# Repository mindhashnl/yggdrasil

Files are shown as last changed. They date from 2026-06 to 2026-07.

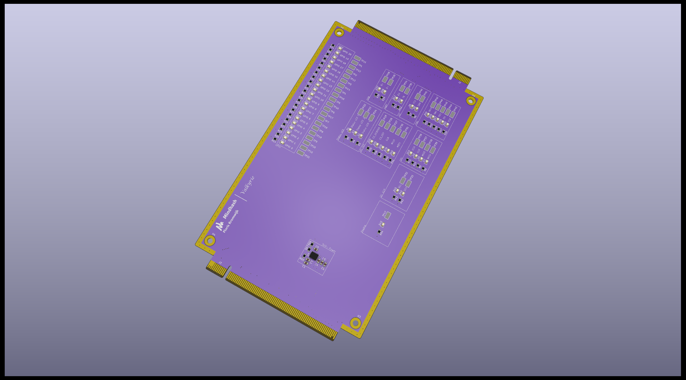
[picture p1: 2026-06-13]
hardware/valkyrie_led/TestBlade.png

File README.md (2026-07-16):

# 🌳 Yggdrasil - Hardware Infrastructure


[]()
[]()

> **⚠️ NOTE:** This repository contains **hardware design files only** (Schematics, PCB Layouts, Gerber files, BOMs, and Mechanical CAD). 
> The software stack is not yet updated to the new hardware.

## 📖 Overview

Yggdrasil is an open-source, modular hardware-in-the-loop (HIL) testing framework designed for continuous integration (CI/CD) of embedded systems. It allows developers to test firmware automatically on real microcontrollers (MCUs) at scale. 

The physical architecture is designed to fit inside a standard **19-inch 3U server rack** and consists of a primary control board, a multiplexing backplane, and hot-swappable target testing blades.

---

## 🧩 System Architecture

The hardware is split into three main modules:

### 1. Mimir (Compute Controller)
The "brain" of the server. It acts as the bridge between the high-level network and the low-level hardware matrix.
* **Core:** Raspberry Pi Compute Module 5 (CM5).
* **Storage:** M.2 NVMe SSD slot for reliable, high-speed storage.
* **Connectivity:** Gigabit Ethernet (RJ45), USB-A, HDMI (for local debugging).
* **Interface:** Connects to the backplane via a custom-pinned PCIe x8 mechanical connector.

### 2. Bifrost (The Backplane)
The routing matrix that connects Mimir to the testing blades. It contains no "smart" compute chips, only routing and switching logic.
* **Switching:** Uses cascaded `74HC595` and `SN74HCS165` shift registers to control `TMUX1511` analog multiplexers.
* **Buses:** Routes shared JTAG, UART, SPI, I2C, CAN, and GPIO lines to any connected blade.
* **Power:** Accepts 12V input and steps it down to 5V and 3.3V rails for the entire system using TPSM33625 modules.
* **Capacity:** Supports up to 16 daughter boards.

### 3. Valkyrie (Daughter Blades)
The Device-Under-Test (DUT) modules. These are inserted into the front of the server.
* **Form Factor:** 110mm x 170mm (excluding PCIe fingers). Fits in custom HDD-style hot-swap trays.
* **Standardization:** Connects to Bifrost using a custom-pinned PCIe x16 mechanical connector.
* **Included Reference Designs:**
  * **Valkyrie-ESP32S3:** A complete testing blade featuring an ESP32-S3, status LEDs, physical buttons, and a hardware identification EEPROM.
  * **Valkyrie-Test:** A diagnostic board with LEDs mapped to every PCIe lane to visually verify multiplexer switching logic.

---

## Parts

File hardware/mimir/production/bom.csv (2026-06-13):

Designator | Footprint | Quantity | Value | LCSC Part #
C1, C10, C11, C12, C2, C3 | 805 | 6 | 22uF
C13, C14, C15, C16, C17, C18, C20 | 1210 | 7 | 100uF
C4, C7 | 805 | 2 | 4.7uF
C5, C8 | 805 | 2 | 100nF
C6, C9 | 805 | 2 | 1uF
D1 | 603 | 1 | LED Green
J10 | HDMI_A_Molex_208658-1001_Horizontal | 1 | HDMI_A_1.4
J11 | PinHeader_2x07_P2.54mm_Vertical | 1 | Conn_02x07_Odd_Even
J2 | M.2 M Key socket | 1 | Bus_M.2_Socket_M
J3 | PinHeader_1x03_P2.54mm_Vertical | 1 | Conn_01x03
J5 | Hirose_FH12-22S-0.5SH_1x22-1MP_P0.50mm_Horizontal | 2 | Conn_01x22_Socket
J6 | RJ45_Hanrun_HR911130A_Horizontal | 1 | RJ45_Hanrun_HR911130A_Horizontal | C54408
J7 | BUS_PCIexpress_x8 | 1 | Bus_PCI_Express_x8
J9 | USB_A_Molex_67643_Horizontal | 1 | USB_A
MODULE3, MODULE4 | Raspberry-Pi-5-Compute-Module | 2 | ComputeModule5-CM5 | C597931
R1 | 805 | 1 | 1k
R10, R11, R12, R13 | 805 | 4 | 4.7kOhm
R3, R4 | 805 | 2 | 470R
R5 | 805 | 1 | 40.2kOhm
R6, R9 | 805 | 2 | 10kOhm
R7 | 805 | 1 | 20kOhm
R8 | 805 | 1 | 23.2kOhm
SW1 | KEY-TH_4P-L7.5-W6.8-P4.50-LS7.2 | 1 | 1825027-5
U1, U2 | RDN0011A-MFG_custom | 2 | TPSM33625RDNR

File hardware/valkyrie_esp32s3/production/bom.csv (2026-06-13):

Designator | Footprint | Quantity | Value | LCSC Part #
C1, C15 | 0805 | 2 | 4.7uF
C10, C16, C2, C7, C8, C9 | 0805 | 6 | 100nF
C11, C12, C13, C14, C17, C3 | 0805 | 6 | 1uF
C18, C19, C20, C4, C5, C6 | 0805 | 6 | 22uF
CR1 | SO-8_STM | 1 | M24C02-WMN6TP
D1, D2, D3 | 0805 | 3 | LED
J1 | BUS_PCIexpress_x16 | 1 | Bus_PCI_Express_x16_Blade
J2 | PinHeader_1x02_P2.54mm_Vertical | 1 | Conn_01x02_Pin
J4 | PinHeader_1x04_P2.54mm_Vertical | 1 | Conn_01x04_Pin
J5 | USB_C_Receptacle_G-Switch_GT-USB-7010ASV | 1 | USB_C_Receptacle_USB2.0_14P
R1 | 0805 | 1 | 40.2kOhm
R10, R11, R21, R22 | 0805 | 4 | 5.1K
R12, R8, R9 | 0805 | 3 | 10k
R13, R15, R17, R19 | 0805 | 4 | 1k
R14, R16, R18, R2, R20, R25 | 0805 | 6 | 10kOhm
R23 | 0805 | 1 | 20kOhm
R24 | 0805 | 1 | 23.2kOhm
R3, R4 | 0805 | 2 | 0Ohm
R5, R6, R7 | 0805 | 3 | 470
SW1, SW2, SW3, SW4, SW6 | SW_Push_1P1T_XKB_TS-1187A | 5 | SW_Push
SW5, SW7 | SW-TH_DSWB02LHGET | 2 | DSWB02LHGET
U1 | ESP32-S3-WROOM-1 | 1 | ESP32-S3-WROOM-1
U2 | SOIC8_ONS | 1 | CAT25160VI-GT3
U3, U5 | RDN0011A-MFG_custom | 2 | TPSM33625RDNR
U4 | RSW10_TEX | 1 | TS3USB30ERSWR

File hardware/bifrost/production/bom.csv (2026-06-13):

Designator | Footprint | Quantity | Value | LCSC Part #
C1, C2 | 0603 | 2 | 4.7uF
C10, C11, C12, C7, C8, C9 | 0603 | 6 | 22uF
C103, C104, C105, C13, C16, C17, C18, C19, C20, C21, C22, C23, C24, C25, C26, C27, C28, C29, C3, C30, C31, C32, C33, C34, C35, C36, C37, C38, C39, C4, C40, C41, C42, C43, C44, C45, C46, C47, C48, C49, C50, C51, C52, C53, C54, C55, C56, C57, C58, C59, C60, C61, C62, C63, C64, C65, C66, C67, C68, C69, C70, C71, C72, C73, C74, C75, C76, C77, C78, C79, C80, C81, C82, C83, C84, C85, C86, C87, C88, C89, C90, C91, C92, C93, C94, C95, C96, C97, C98, C99 | 0201 | 90 | 100nF
C5, C6 | 0603 | 2 | 1uF
IC1, IC2, IC3 | SOP50P326X110-16N | 3 | SN74HCS165DYYR
J1 | Molex_Mini-Fit_Jr_5566-02A_2x01_P4.20mm_Vertical | 1 | Conn_01x02_Socket
J11, J15, J4 | CONN-SMD_164P-P1.00-X3113WVS-164-9TV01 | 3 | Bus_PCI_Express_x16_Blade | C5711234
J2 | CONN-TH_2EG04927-D2LN-DF | 1 | Bus_PCI_Express_x8 | C5141736
J3 | USB_C_Receptacle_G-Switch_GT-USB-7010ASV | 1 | USB_C_Receptacle_USB2.0_14P
R1 | 0603 | 1 | 20kOhm
R10, R102, R105, R108, R11, R111, R114, R117, R12, R120, R123, R126, R129, R13, R132, R135, R138, R14, R141, R144, R145, R146, R147, R148, R149, R15, R150, R151, R152, R153, R154, R155, R156, R157, R158, R159, R16, R160, R161, R162, R163, R164, R165, R166, R17, R18, R19, R20, R21, R22, R23, R24, R27, R30, R33, R36, R39, R42, R45, R48, R51, R54, R57, R6, R60, R63, R66, R69, R7, R72, R75, R78, R8, R81, R84, R87, R9, R90, R93, R96, R99 | 0201 | 81 | 5.1K
R2 | 0603 | 1 | 23.2kOhm
R3, R5 | 0603 | 2 | 10kOhm
R4 | 0603 | 1 | 40.2kOhm
U1, U2 | RDN0011A-MFG_custom | 2 | TPSM33625RDNR
U10, U11, U12, U17, U18, U19, U20, U21, U22, U27, U28, U29, U30, U33, U34, U35, U36, U37, U42, U43, U44, U45, U46, U47, U52, U53, U54, U55, U58, U59, U60, U61, U62, U67, U68, U69, U70, U71, U72, U77, U78, U79, U8, U80, U9 | RSV0016A-MFG | 45 | TMUX1511RSVR
U13, U16, U23, U24, U25, U26, U38, U41, U48, U49, U50, U51, U63, U66, U73, U74, U75, U76 | TQFN-16_L2.5-W2.5-P0.40-BL-EP1.4 | 18 | 74HC595 | C2682068
U14, U3, U39, U64 | TQFN-16_L2.5-W2.5-P0.40-BL-EP1.4 | 4 | 74HC595
U15, U40, U65 | RSW10_TEX | 3 | TS3USB30ERSWR
U31, U32, U56, U57, U6, U7 | TSOT-23-8 | 6 | TCA9416DDFR
U4 | SOT-363_SC-70-6 | 1 | SiP32431DR3

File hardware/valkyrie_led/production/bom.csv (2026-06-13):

Designator | Footprint | Quantity | Value | LCSC Part #
C1 | 0805 | 1 | 4.7uF
C2 | 0805 | 1 | 100nF
C3 | 0805 | 1 | 1uF
C4, C5, C6 | 0805 | 3 | 22uF
D10, D11, D12, D13, D14, D15, D16, D17, D18, D19, D2, D20, D21, D22, D23, D24, D25, D26, D27, D28, D29, D3, D30, D31, D32, D33, D34, D35, D36, D37, D38, D39, D4, D40, D41, D42, D43, D5, D54, D55, D56, D57, D58, D6, D7, D8, D9 | 0805 | 47 | LED
J2, J3 | BUS_PCIexpress_x16 | 2 | Bus_PCI_Express_x16_Blade
R10, R11, R12, R13, R14, R15, R16, R17, R18, R19, R20, R21, R22, R23, R24, R25, R26, R27, R28, R29, R3, R30, R31, R32, R33, R34, R35, R36, R37, R38, R39, R4, R40, R41, R42, R43, R44, R5, R55, R56, R57, R58, R59, R6, R7, R8, R9 | 0805 | 47 | 470
R65 | 0805 | 1 | 20kOhm
R66 | 0805 | 1 | 23.2kOhm
R67 | 0805 | 1 | 10kOhm
TP1, TP10, TP11, TP12, TP13, TP14, TP15, TP16, TP17, TP18, TP19, TP2, TP20, TP21, TP22, TP23, TP24, TP25, TP26, TP27, TP28, TP29, TP3, TP30, TP31, TP32, TP33, TP34, TP35, TP36, TP37, TP38, TP39, TP4, TP40, TP41, TP42, TP43, TP44, TP45, TP46, TP47, TP5, TP6, TP7, TP8, TP9 | TestPoint_Keystone_5019_Minature | 47 | TestPoint
U1 | RDN0011A-MFG_custom | 1 | TPSM33625RDNR

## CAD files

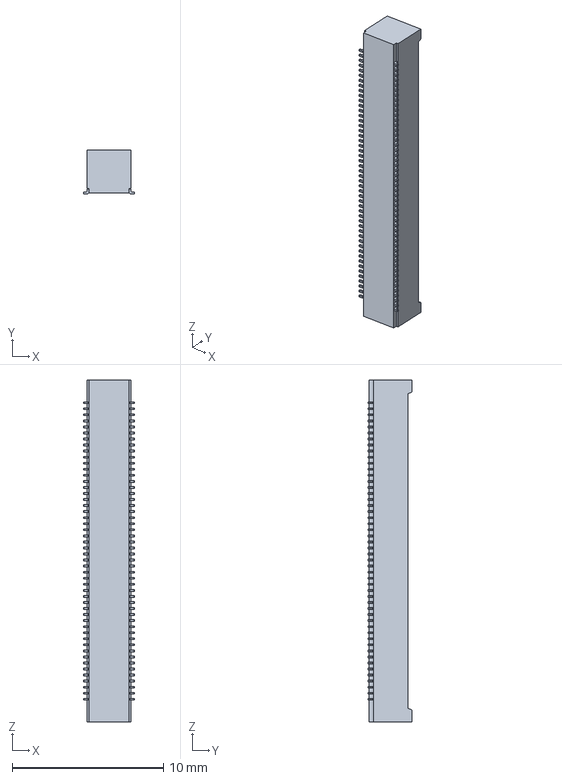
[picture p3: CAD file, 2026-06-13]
hardware/imports/RPi-CM4-Kicad-master/3D/DF40HC(3.0)-100DS-0.4V.stp
3.38 x 2.90 x 22.6 mm

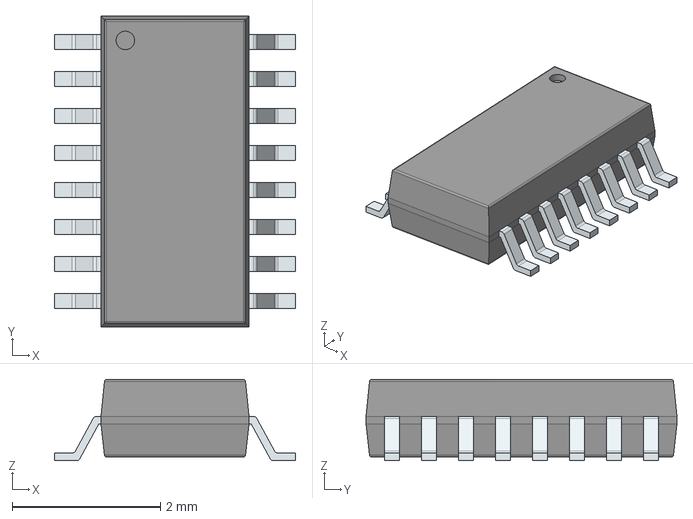
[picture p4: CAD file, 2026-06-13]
hardware/imports/step.3d/SN74HCS165DYYR.stp
3.26 x 4.20 x 1.10 mm
PinsArrayLR

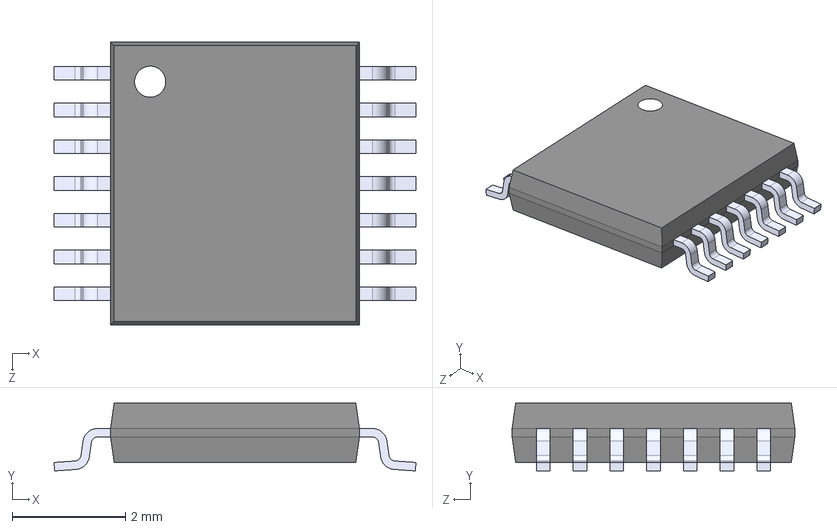
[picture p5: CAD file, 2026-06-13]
hardware/imports/TMUX1511PWR/TMUX1511PWR.step
6.40 x 1.20 x 5.00 mm

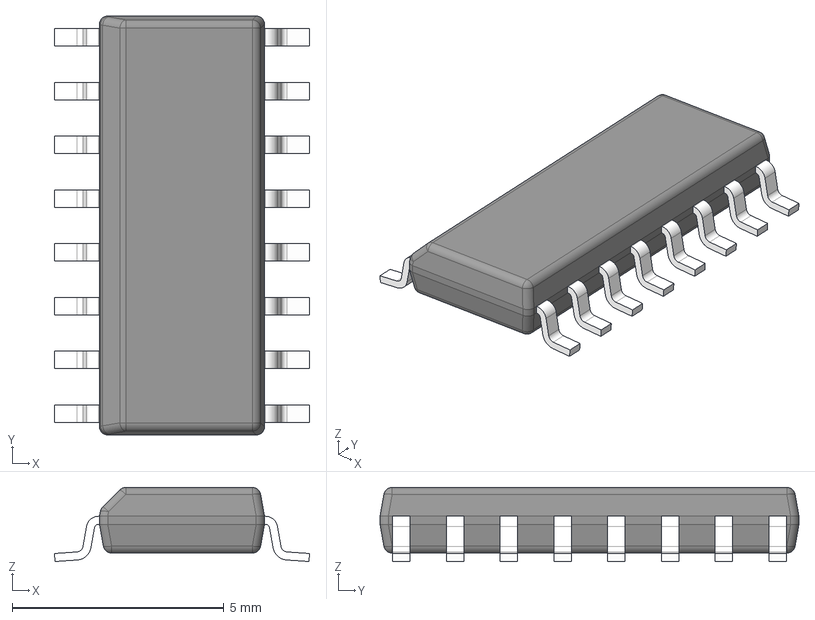
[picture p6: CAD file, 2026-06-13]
hardware/imports/ul_SN74HC595D/D0016A.stp
6.03 x 9.90 x 1.75 mm
BODY-SO
LEAD-SO x 16
PIN1-ID

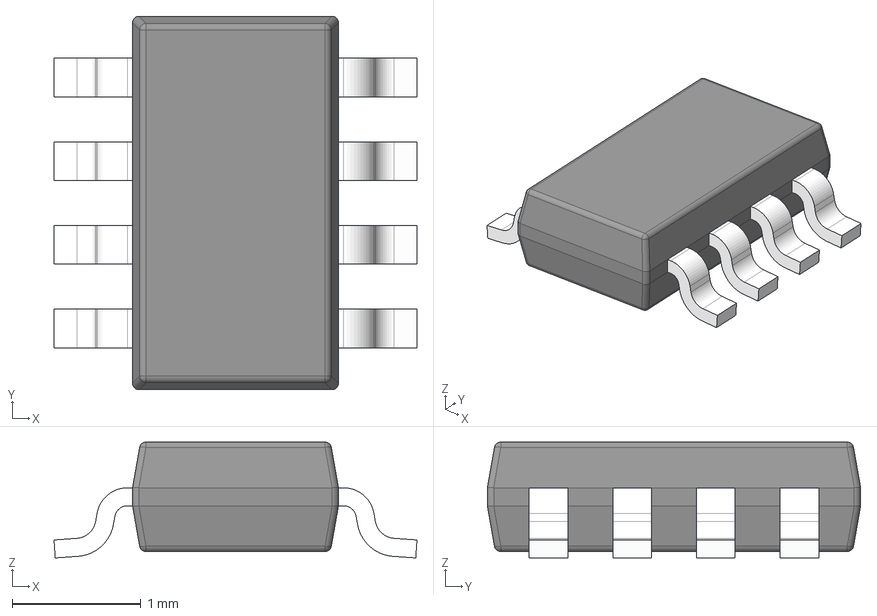
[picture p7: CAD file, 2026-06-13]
hardware/imports/ul_TCA9416DDFR/DDF0008A.stp
2.82 x 2.90 x 0.9 mm
BODY-SO
LEAD-SO x 8
PIN1-ID

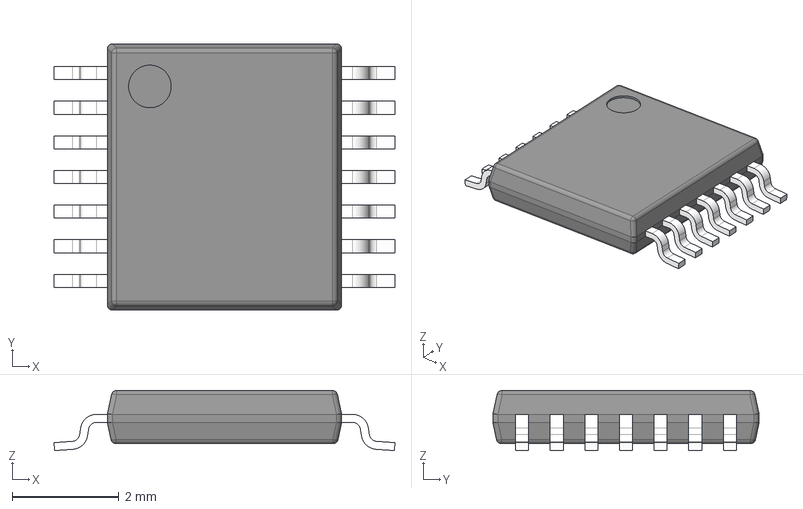
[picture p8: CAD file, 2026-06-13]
hardware/imports/ul_TMUX1511PWR/PW0014A.stp
6.40 x 5.00 x 1.13 mm
BODY-TSSOP
LEAD-TSSOP x 14
PIN1

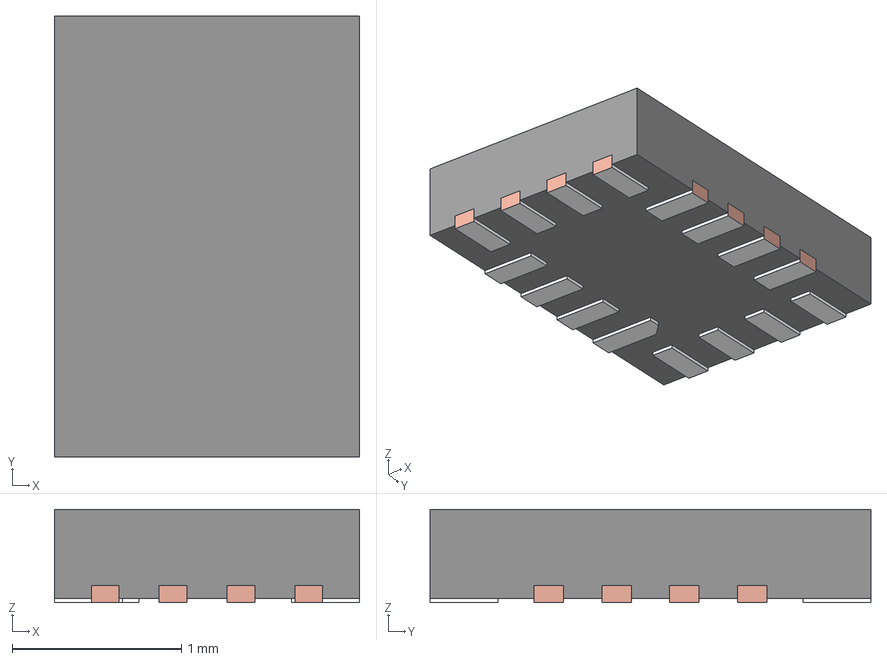
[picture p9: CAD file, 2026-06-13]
hardware/imports/ul_TMUX1511RSVR/RSV0016A.stp
1.80 x 2.60 x 0.55 mm
BODY-SON1
FRAME-RSV0016A

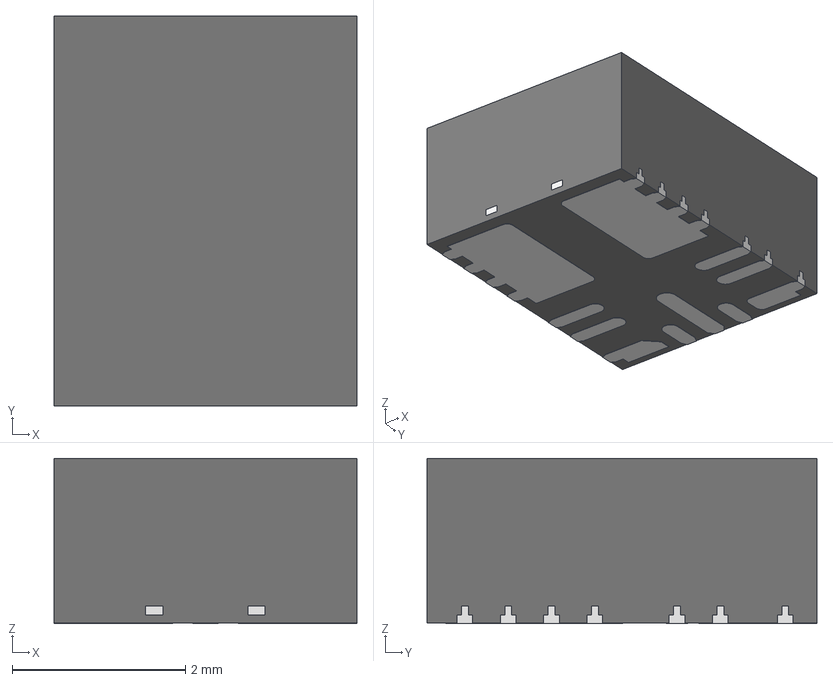
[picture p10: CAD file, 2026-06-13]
hardware/imports/ul_TPSM33625RDNR/TPSM33635.stp
3.50 x 4.50 x 1.91 mm
MOLD_CPOMPOUND_AF0
SOLID1-489_AF0
SOLID1-490_AF0
SOLID1-491_AF0
SOLID1-492_AF0
SOLID1-493_AF0
SOLID1-494_AF0
SOLID1-495_AF0
SOLID1-496_AF0
SOLID1-497_AF0
SOLID1-498_AF0

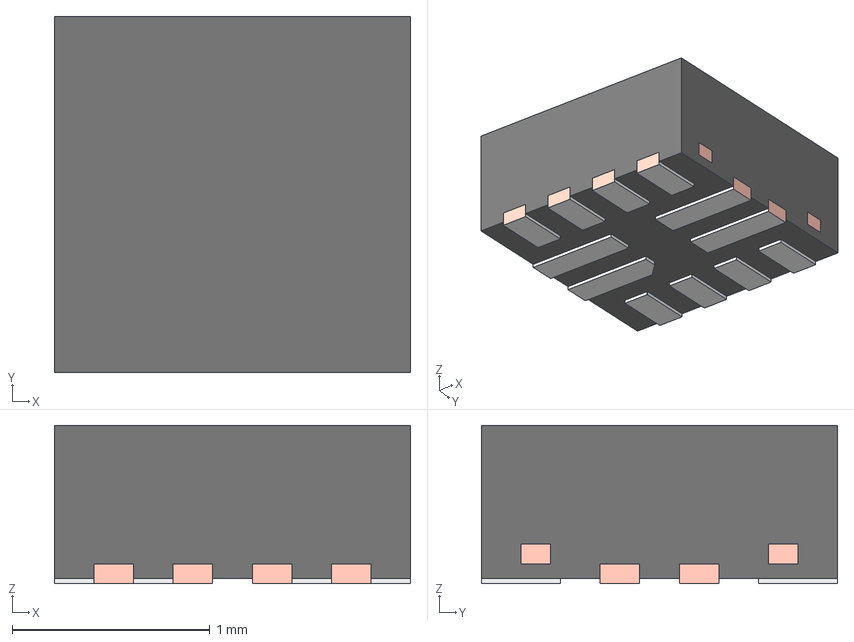
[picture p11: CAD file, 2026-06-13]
hardware/imports/ul_TS3USB3031RMGR/RMG0012A.stp
1.80 x 1.80 x 0.8 mm
FRAME
PIN1_AREA

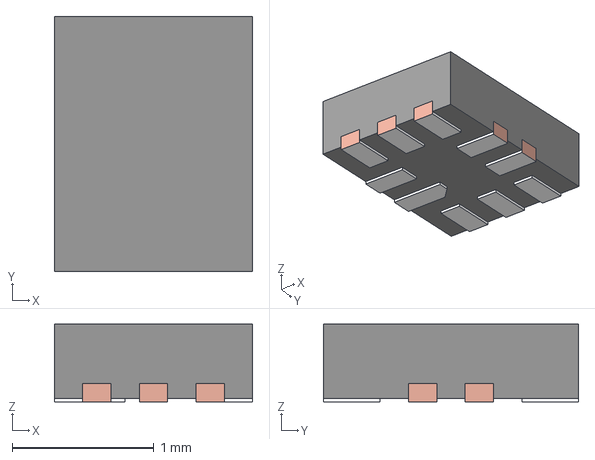
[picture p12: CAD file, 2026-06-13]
hardware/imports/ul_TS3USB30ERSWR/RSW0010A.stp
1.40 x 1.80 x 0.55 mm
FRAME

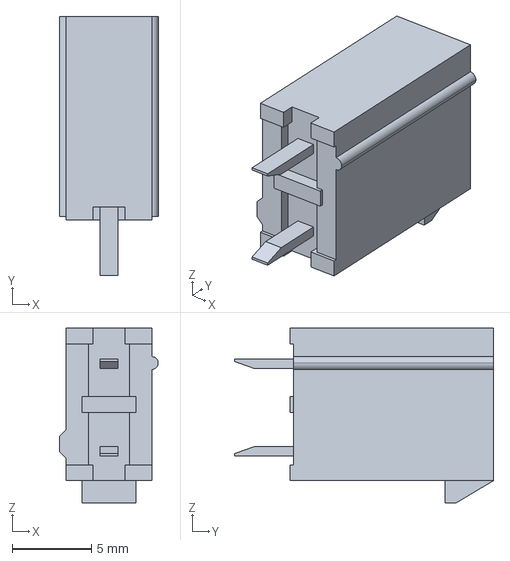
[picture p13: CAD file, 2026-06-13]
hardware/imports/174478858-659-0039281023/0039281023.stp
6.20 x 16.3 x 11.0 mm

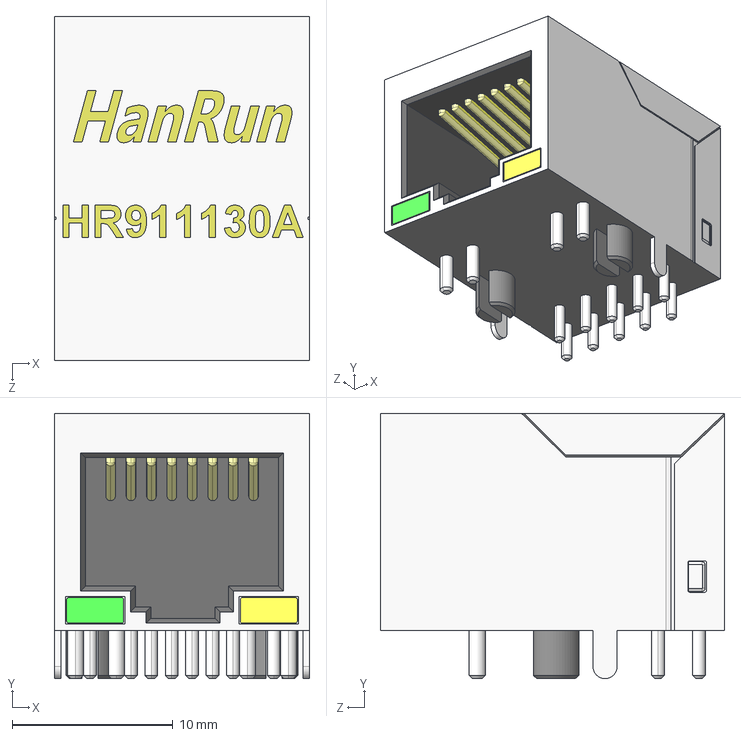
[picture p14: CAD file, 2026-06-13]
hardware/imports/Hanrun/HR911130A.STEP
15.9 x 16.5 x 21.4 mm

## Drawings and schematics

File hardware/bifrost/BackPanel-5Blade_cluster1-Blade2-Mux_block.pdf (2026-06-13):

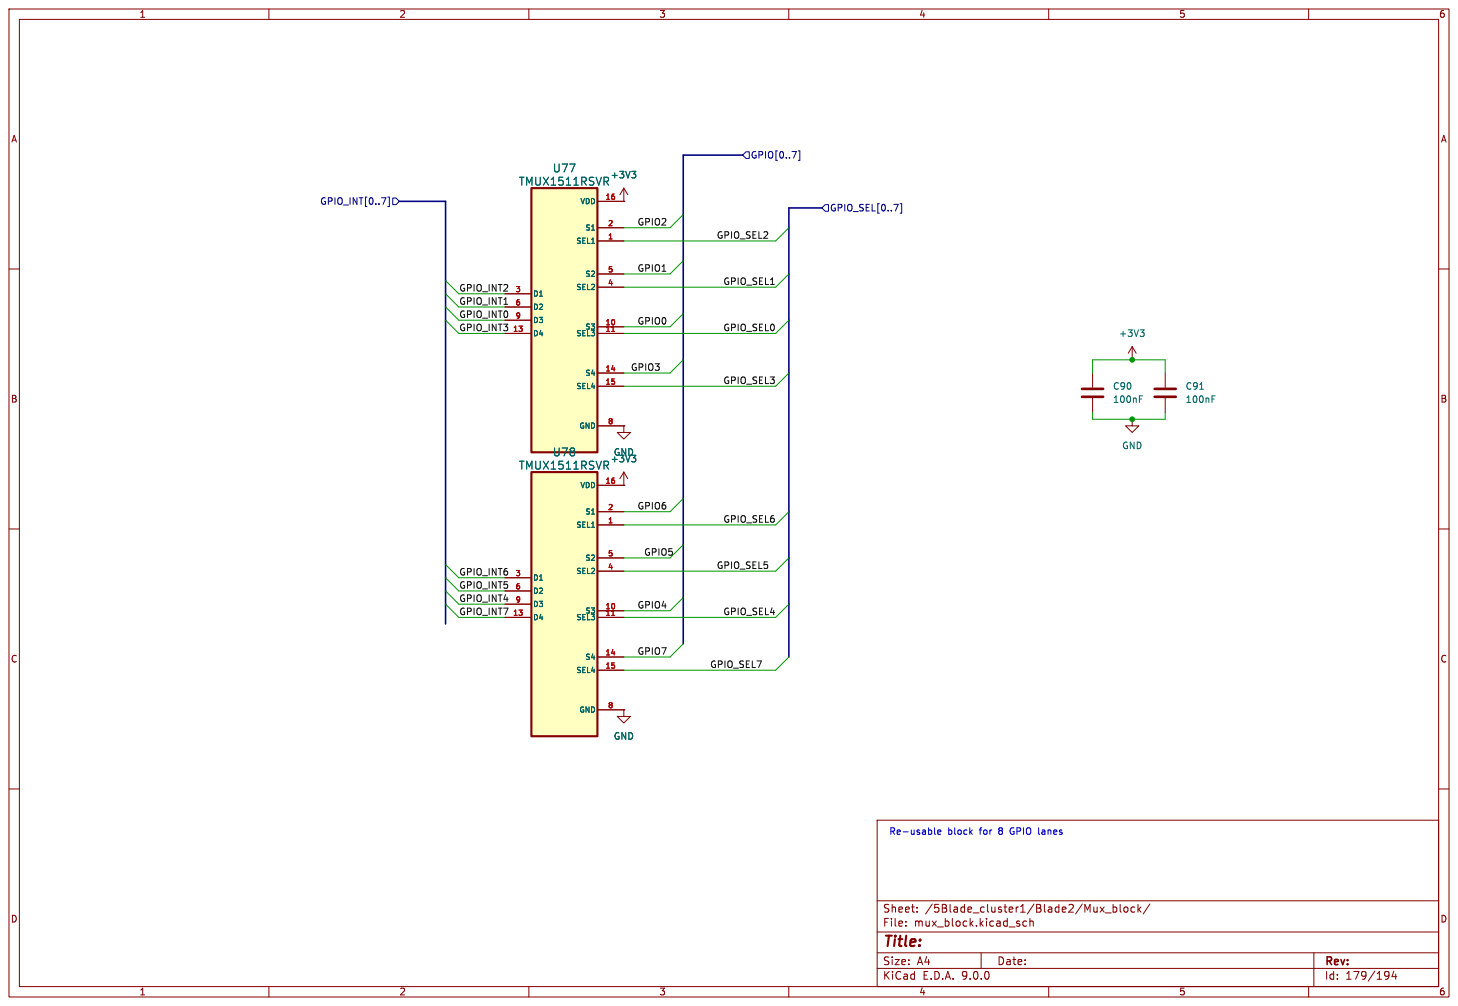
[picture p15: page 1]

Id: 179/194 Title: File: mux_block.kicad_sch Sheet: /5Blade_cluster1/Blade2/Mux_block/

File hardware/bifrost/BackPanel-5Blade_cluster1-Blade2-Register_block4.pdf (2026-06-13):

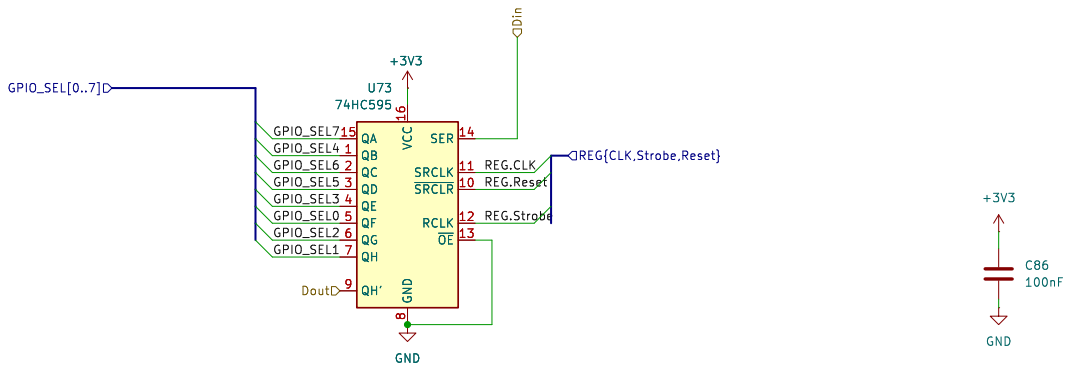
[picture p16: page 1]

8 QA 15 QB 1 QC 2 QD 3 QE 4 QF 5 QG 6 QH 7 QH' 9 GND

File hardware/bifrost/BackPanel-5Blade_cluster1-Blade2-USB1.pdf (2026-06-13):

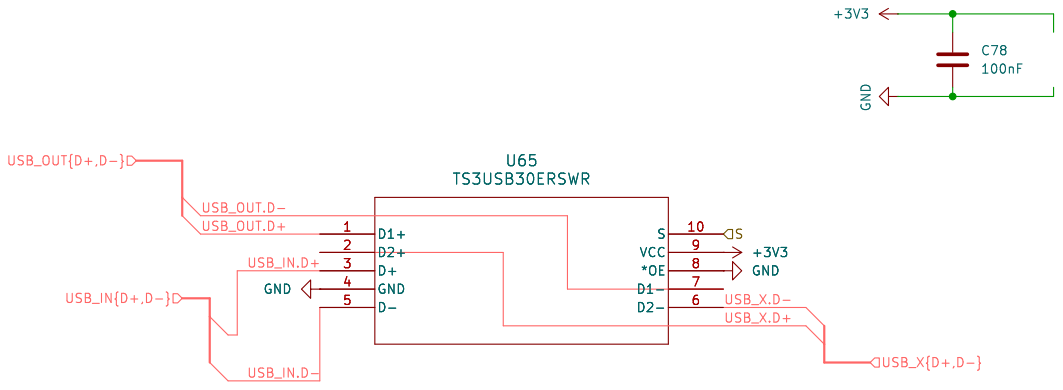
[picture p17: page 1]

Id: 169/194 Title: File: USB.kicad_sch Sheet: /5Blade_cluster1/Blade2/USB1/ GND

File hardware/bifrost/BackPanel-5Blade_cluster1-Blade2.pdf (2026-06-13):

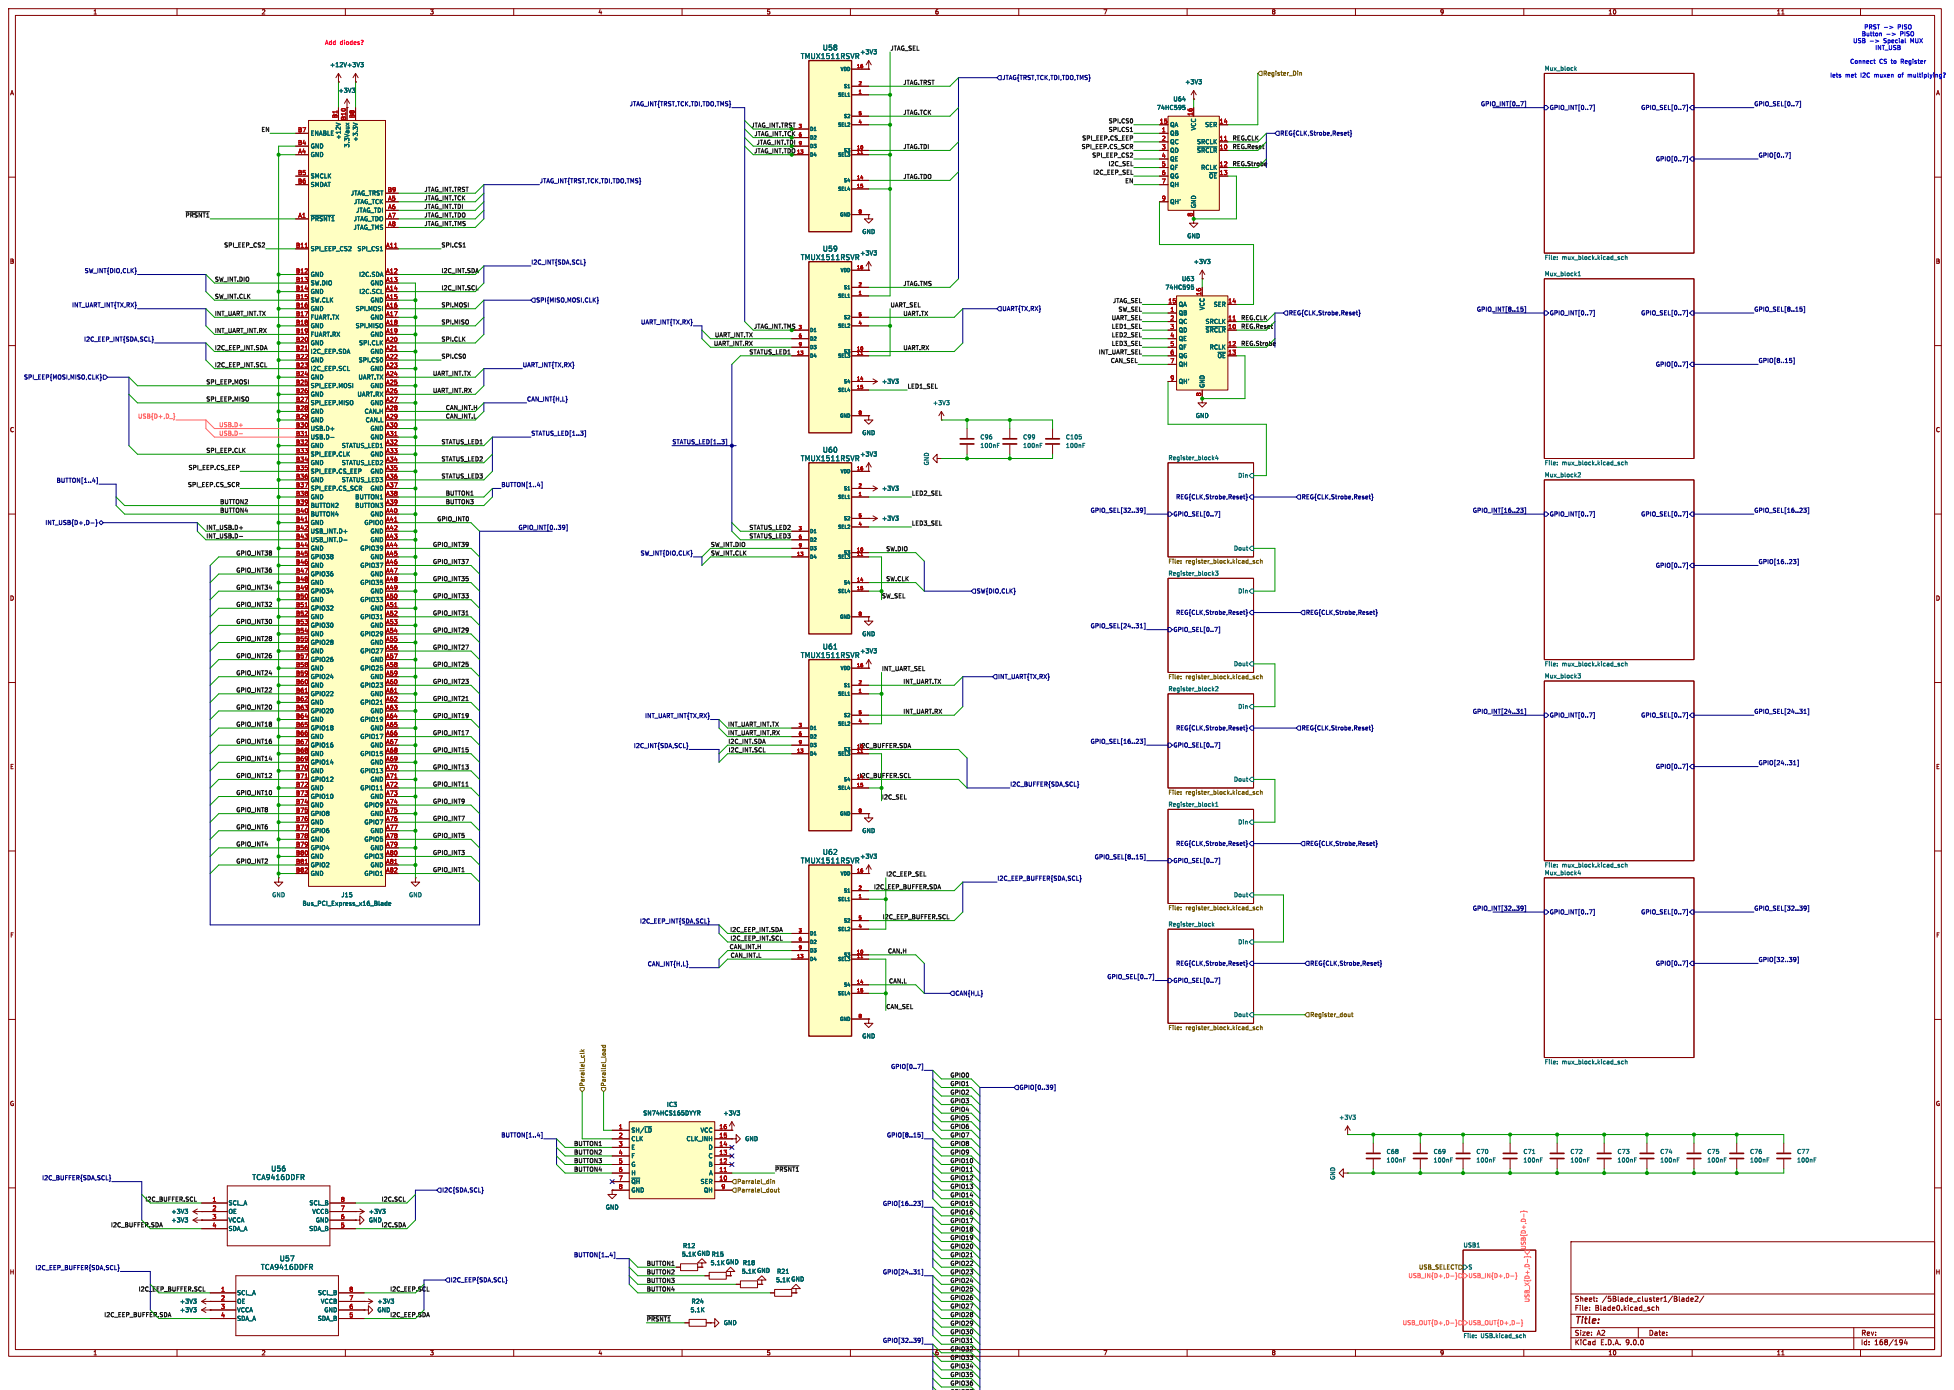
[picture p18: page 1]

INT_USB Connect CS to Register

ENABLE B7 GND B4 GND A4 SMCLK B5 SMDAT B6 ~{PRSNT1} A1 SPI_EEP_CS2 B11 GND B12 SW.DIO B13 GND B14 SW.CLK B15 GND B16 FUART.TX B17 GND B18 FUART.RX B19 GND B20

JTAG{TRST,TCK,TDI,TDO,TMS}

8 QA 15 QB 1 QC 2 QD 3 QE 4 QF 5 QG 6 QH 7 QH' 9 +3V3 GND

JTAG.TDI JTAG.TCK GPIO_INT[0..39] GPIO_INT25 GPIO_INT27 GPIO_INT33 GPIO_INT39 GPIO_INT37 GPIO_INT31 GPIO_INT35

REG{CLK,Strobe,Reset}

REG.Reset REG.CLK REG.Strobe

JTAG_INT{TRST,TCK,TDI,TDO,TMS}

I2C.SCL A14 GND A15 SPI.MOSI A16 GND A17 SPI.MISO A18 GND A19 SPI.CLK A20 GND A21 SPI.CS0 A22 GND A23 UART.TX A24 GND A25 UART.RX A26 GND A27 CAN.H A28 CAN.L A29 GND A30 GND A31 STATUS_LED1 A32 GND A33 STATUS_LED2 A34 GND A35 STATUS_LED3 A36 GND A37 BUTTON1 A38 BUTTON3 A39 GND A40 GPIO0 A41 GND A42 GND A43 GPIO39 A44 GND A45 GPIO37 A46 GND A47 GPIO35 A48 GND A49 GPIO33 A50 GND A51 GPIO31 A52 GND A53 GPIO29 A54 GND A55 GPIO27 A56 GND A57 GPIO25 A58 GND A59 GPIO23 A60 GND A61 GPIO21 A62 GND A63 GPIO19 A64 GND A65 GPIO17 A66 GND A67 GPIO15 A68 GND A69 GPIO13 A70 GND A71 GPIO11 A72 GND A73 GPIO9 A74 GND A75 GPIO7 A76 GND A77 GPIO5 A78 GND A79 GPIO3 A80 GND A81 GPIO1 A82

JTAG_TRST B9
JTAG_TCK A5
JTAG_TDI A6
JTAG_TDO A7
JTAG_TMS A8 SPI_CS1 A11
I2C_INT.SCL CAN_INT.H
I2C.SCL A14 GND A15 SPI.MOSI A16 GND A17 SPI.MISO A18 GND A19 SPI.CLK A20 GND A21 SPI.CS0 A22 GND A23 UART.TX A24 GND A25 UART.RX A26 GND A27 CAN.H A28 CAN.L A29 GND A30 GND A31 STATUS_LED1 A32 GND A33 STATUS_LED2 A34 GND A35 STATUS_LED3 A36 GND A37 BUTTON1 A38 BUTTON3 A39 GND A40 GPIO0 A41 GND A42 GND A43 GPIO39 A44 GND A45 GPIO37 A46 GND A47 GPIO35 A48 GND A49 GPIO33 A50 GND A51 GPIO31 A52 GND A53 GPIO29 A54 GND A55 GPIO27 A56 GND A57 GPIO25 A58 GND A59 GPIO23 A60 GND A61 GPIO21 A62 GND A63 GPIO19 A64 GND A65 GPIO17 A66 GND A67 GPIO15 A68 GND A69 GPIO13 A70 GND A71 GPIO11 A72 GND A73 GPIO9 A74 GND A75 GPIO7 A76 GND A77 GPIO5 A78 GND A79 GPIO3 A80 GND A81 GPIO1 A82 GND

+3V3 GND
GPIO[0..7] Mux_block1 File: mux_block.kicad_sch Din REG{CLK,Strobe,Reset}
12 ~{OE} 13 VCC 16 GND
14 SRCLK
SER
11 ~{SRCLR} 10 RCLK

I2C_EEP_INT.SCL SPI_EEP.MOSI SW_INT{DIO,CLK}

SPI{MISO,MOSI,CLK}

GPIO[0..7] Mux_block2 File: mux_block.kicad_sch Din REG{CLK,Strobe,Reset}

REG{CLK,Strobe,Reset} Parallel_clk

Din REG{CLK,Strobe,Reset}

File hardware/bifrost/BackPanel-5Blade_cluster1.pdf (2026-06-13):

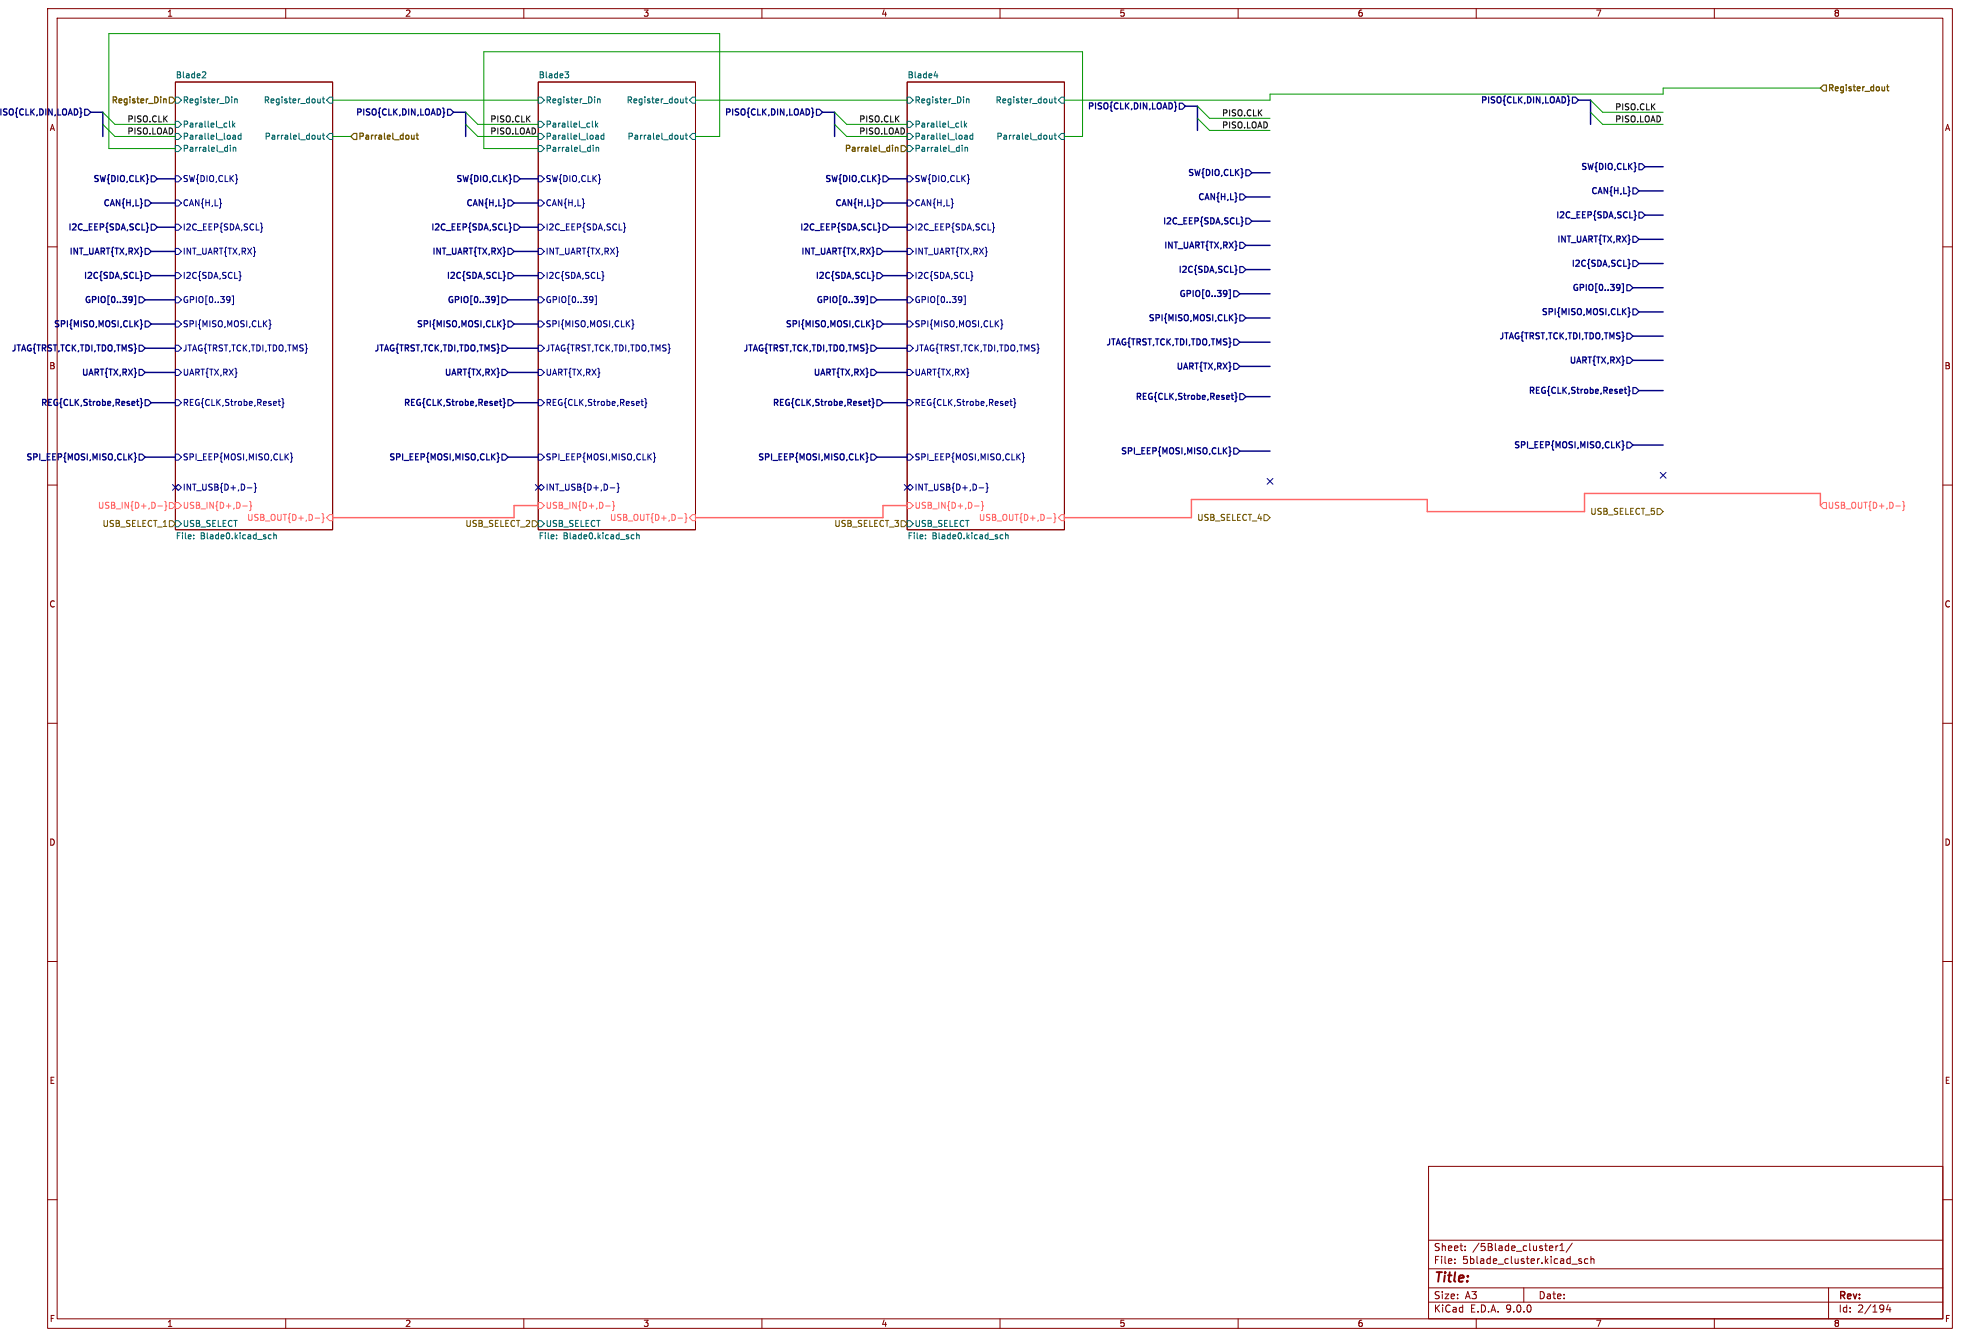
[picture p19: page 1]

SPI{MISO,MOSI,CLK} Blade5 File: Blade0.kicad_sch REG{CLK,Strobe,Reset}

PISO{CLK,DIN,LOAD}

I2C{SDA,SCL} Parralel_dout PISO{CLK,DIN,LOAD}

SPI{MISO,MOSI,CLK} Blade9 File: Blade0.kicad_sch REG{CLK,Strobe,Reset}

SPI{MISO,MOSI,CLK} Blade8 File: Blade0.kicad_sch REG{CLK,Strobe,Reset}

SPI{MISO,MOSI,CLK}

JTAG{TRST,TCK,TDI,TDO,TMS}

REG{CLK,Strobe,Reset}

Id: 2/194 Title: File: 5blade_cluster.kicad_sch Sheet: /5Blade_cluster1/

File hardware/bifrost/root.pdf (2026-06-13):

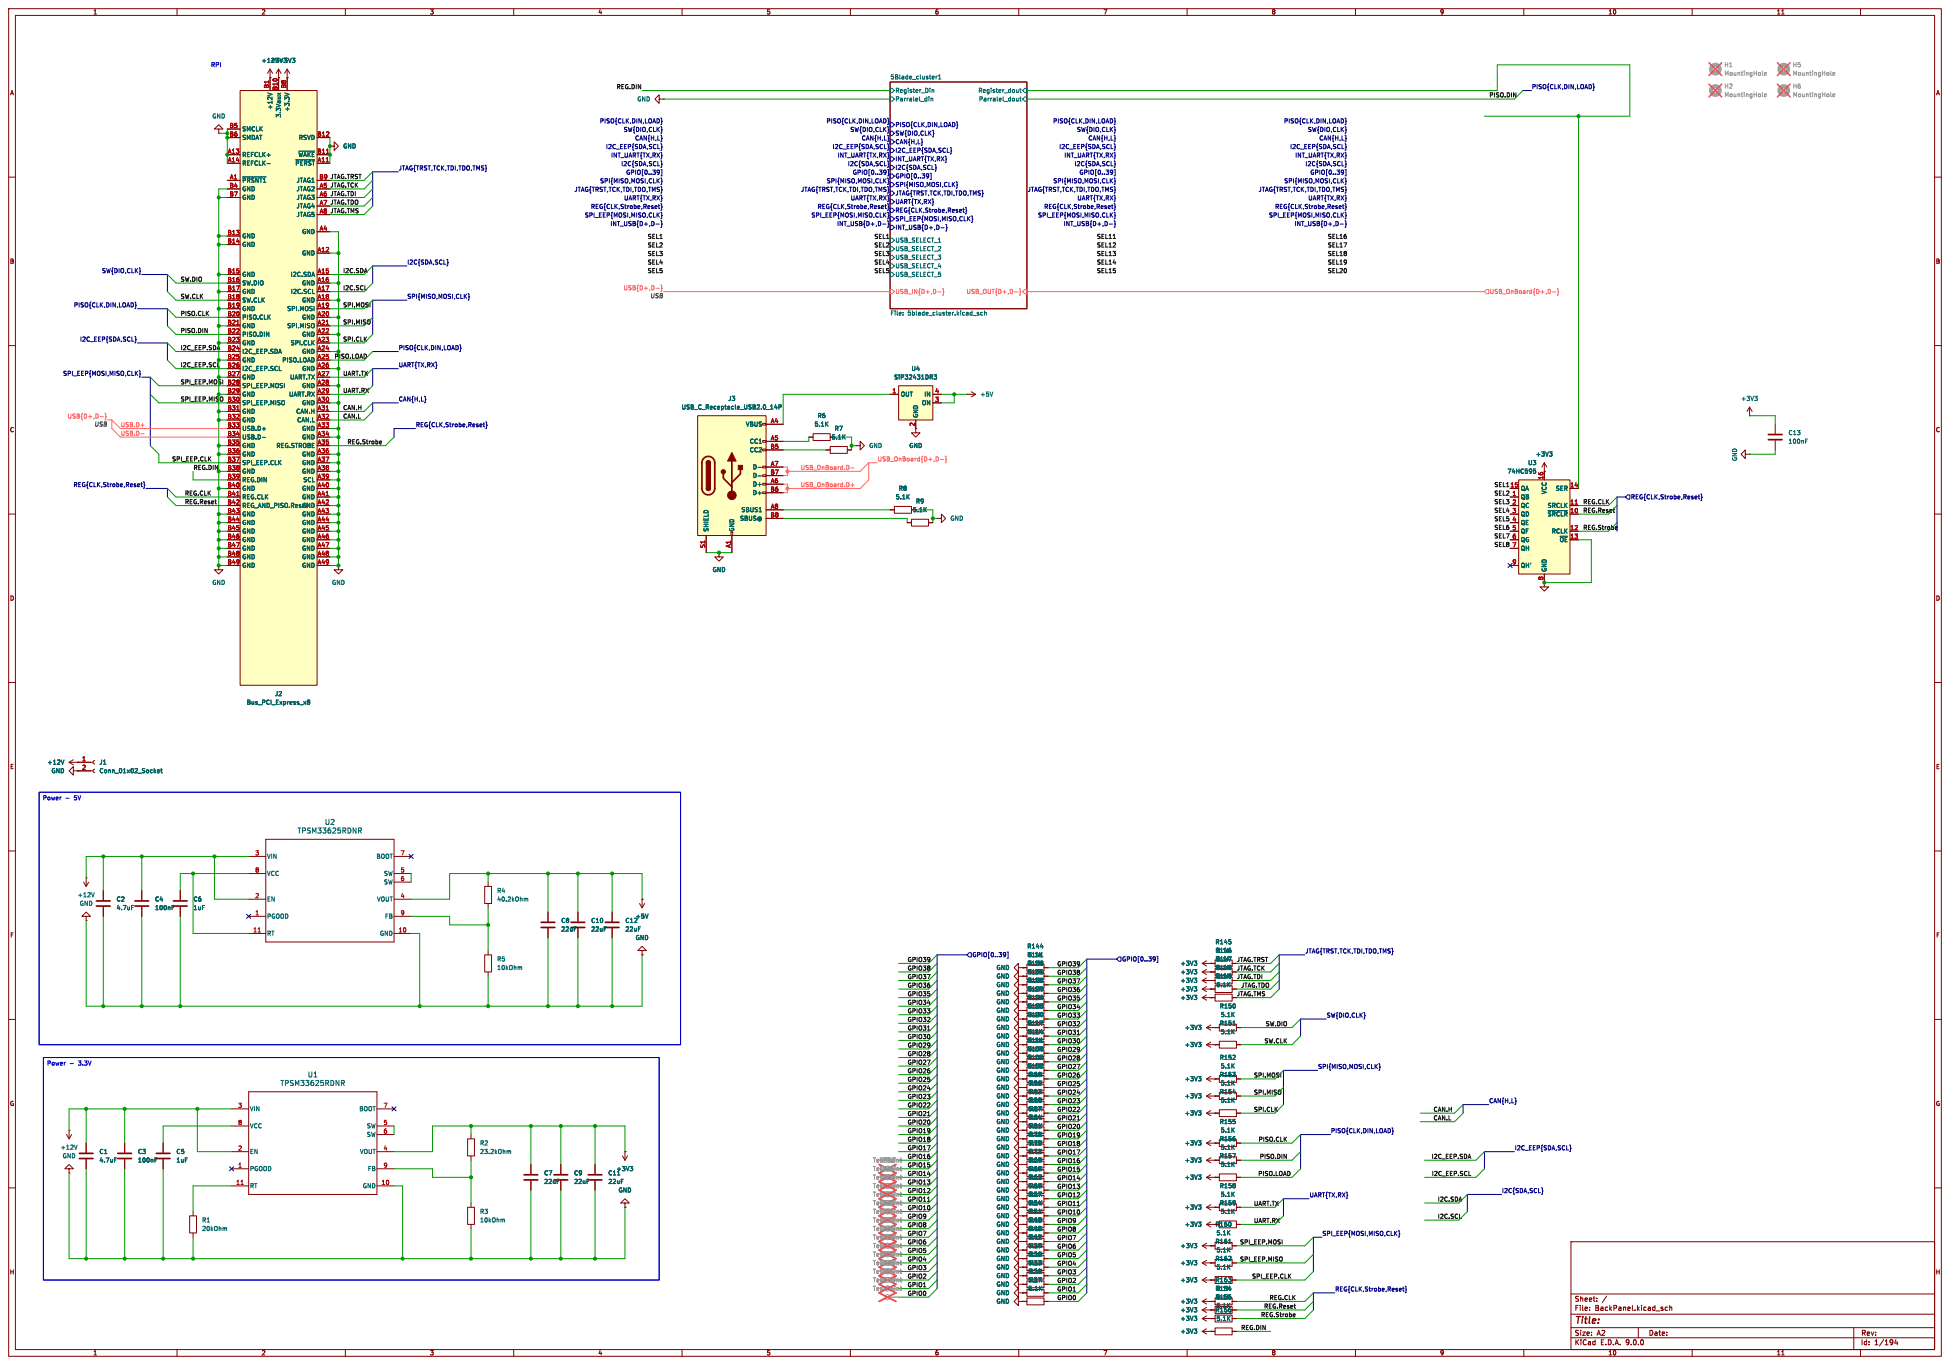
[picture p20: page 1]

+12V+3V3+3V3 GND
RPI
SMCLK B5 SMDAT B6 REFCLK+ A13 REFCLK- A14 ~{PRSNT1} A1 GND B4 GND B7 GND B13 GND B14 GND B15 SW.DIO B16 GND B17 SW.CLK B18 GND B19 PISO.CLK B20 GND B21 PISO.DIN B22 GND B23

PISO{CLK,DIN,LOAD} SEL11

Register_dout Parralel_dout PISO{CLK,DIN,LOAD}

PISO{CLK,DIN,LOAD}

INT_UART{TX,RX}
I2C{SDA,SCL}
GPIO[0..39]
SPI{MISO,MOSI,CLK}
JTAG{TRST,TCK,TDI,TDO,TMS}
UART{TX,RX}
REG{CLK,Strobe,Reset}
SPI_EEP{MOSI,MISO,CLK}
INT_USB{D+,D-}
USB_OUT{D+,D-} USB_SELECT_5 USB_SELECT_2 USB_SELECT_3 USB_SELECT_4 USB_IN{D+,D-} USB_SELECT_1

I2C{SDA,SCL} SPI_EEP.CLK REG.DIN
JTAG.TRST REG.CLK

INT_USB{D+,D-} SEL1 SPI{MISO,MOSI,CLK}

SPI{MISO,MOSI,CLK} SEL16 UART{TX,RX}

JTAG.TDI JTAG.TCK

JTAG.TDO
JTAG.TMS
I2C.SCL A17 GND A18 SPI.MOSI A19 GND A20 SPI.MISO A21 GND A22 SPI.CLK A23 GND A24 PISO.LOAD A25 GND A26 UART.TX A27 GND A28 UART.RX A29 GND A30 CAN.H A31 CAN.L A32 GND A33 GND A34 REG.STROBE A35 GND A36 GND A37 GND A38 SCL A39 GND A40 GND A41 GND A42 GND A43 GND A44 GND A45 GND A46 GND A47 GND A48 GND A49

SEL4 SPI_EEP{MOSI,MISO,CLK}

REG{CLK,Strobe,Reset} SEL13

USB_OnBoard{D+,D-} SEL7 USB{D+,D-} USB

REG{CLK,Strobe,Reset} SPI.MOSI
UART.RX REG.Strobe UART.TX

I2C_EEP{SDA,SCL}
I2C_EEP.SDA REG{CLK,Strobe,Reset}

REG.CLK REG.Strobe REG.Reset

5.1K GND GND GND GND GND GND GND GND

GPIO34 GPIO36
SPI{MISO,MOSI,CLK} GPIO21 GPIO20 GPIO35 GPIO33 GPIO29 GPIO32 GPIO31 GPIO27 GPIO26 GPIO23 GPIO24

5.1K GND GND GND GND GND GND

SPI.MOSI SPI.CLK

GPIO22
5.1K GND GND GND GND GND GND GND GND GND GND GND GND

GND

REG{CLK,Strobe,Reset} SPI_EEP.MOSI SPI_EEP.MISO

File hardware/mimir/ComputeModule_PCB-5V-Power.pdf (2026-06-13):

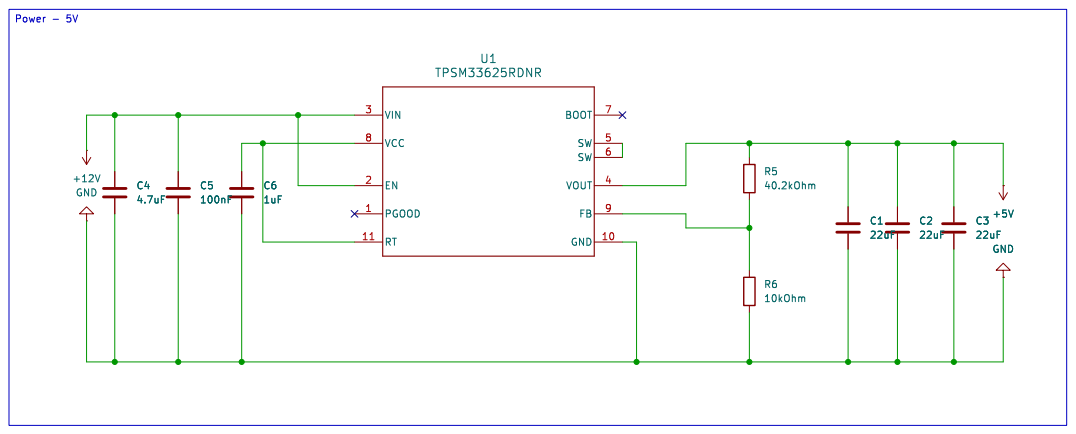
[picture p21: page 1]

Id: 3/3 Title: File: 5V_power.kicad_sch Sheet: /5V-Power/

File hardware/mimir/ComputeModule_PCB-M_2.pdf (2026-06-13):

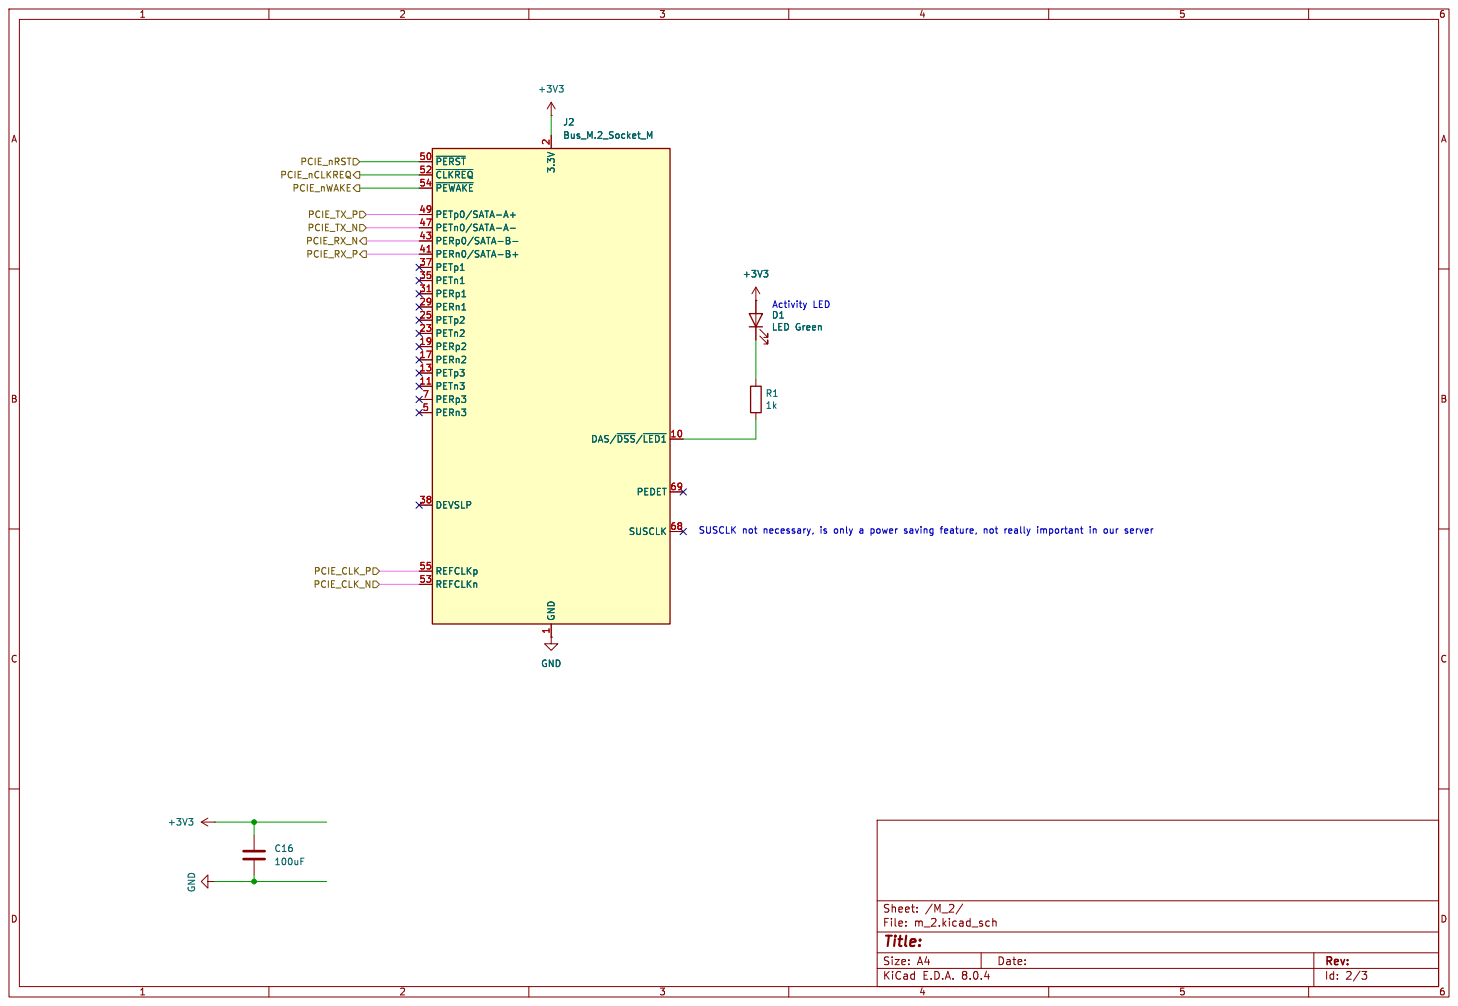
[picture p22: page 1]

2 PETn2 23 PETp2 25 PERn1 29 PERp1 31 PETn1 35 PETp1 37 DEVSLP 38 PERn0/SATA-B+ 41 PERp0/SATA-B- 43 PETn0/SATA-A- 47 PETp0/SATA-A+ 49 PERn3 5 ~{PERST} 50 ~{CLKREQ} 52 REFCLKn 53

Id: 2/3 Title: File: m_2.kicad_sch Sheet: /M_2/

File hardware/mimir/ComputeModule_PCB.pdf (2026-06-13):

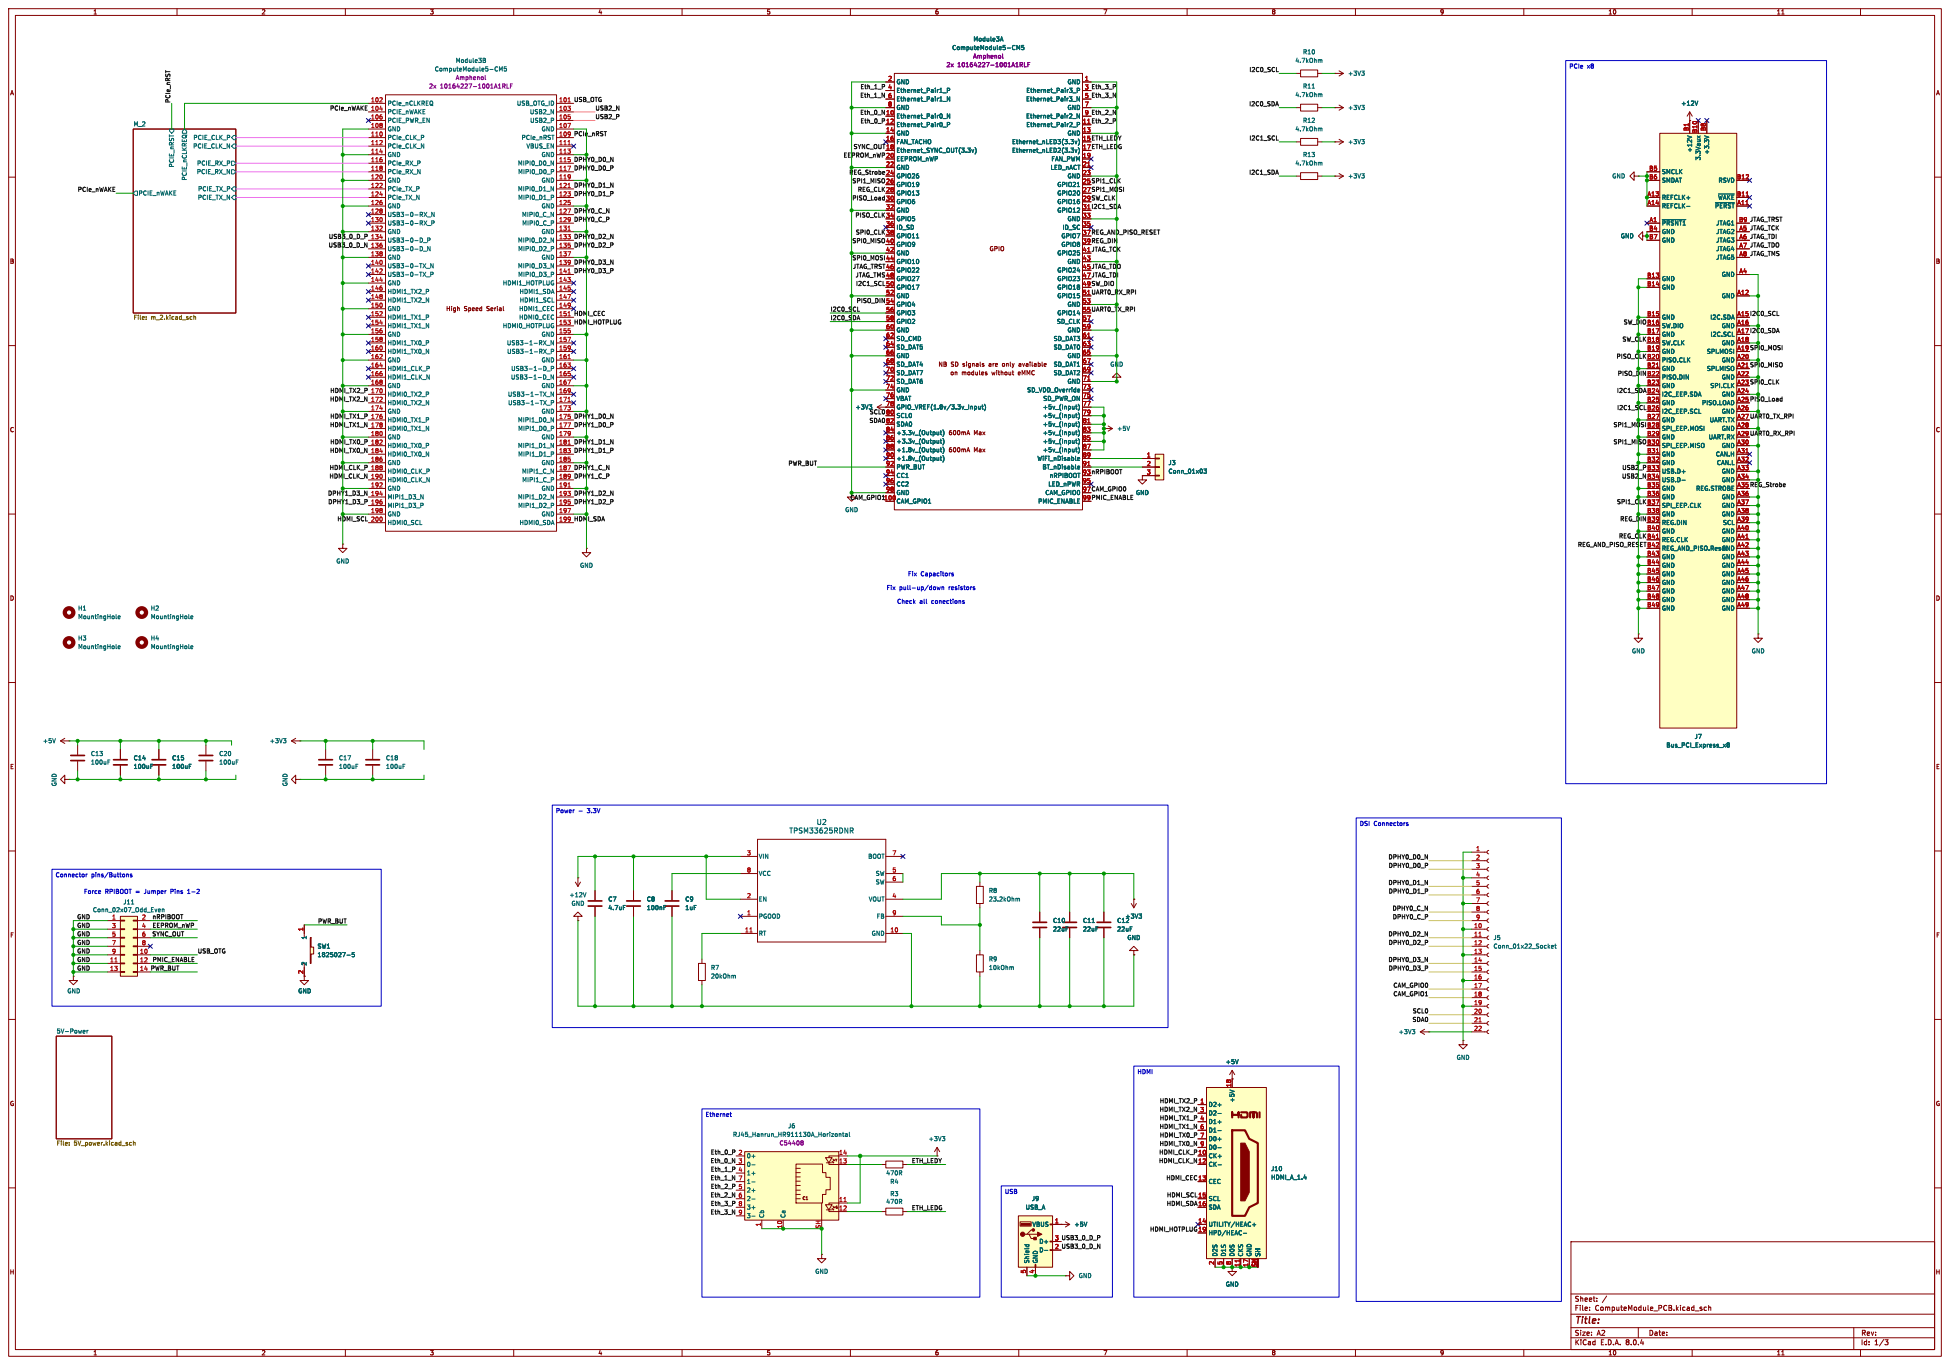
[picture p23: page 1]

600mA Max 600mA Max NB SD signals are only available

Force RPIBOOT = Jumper Pins 1-2
J11 Conn_02x07_Odd_Even

SYNC_OUT GND GND GND GND GND GND

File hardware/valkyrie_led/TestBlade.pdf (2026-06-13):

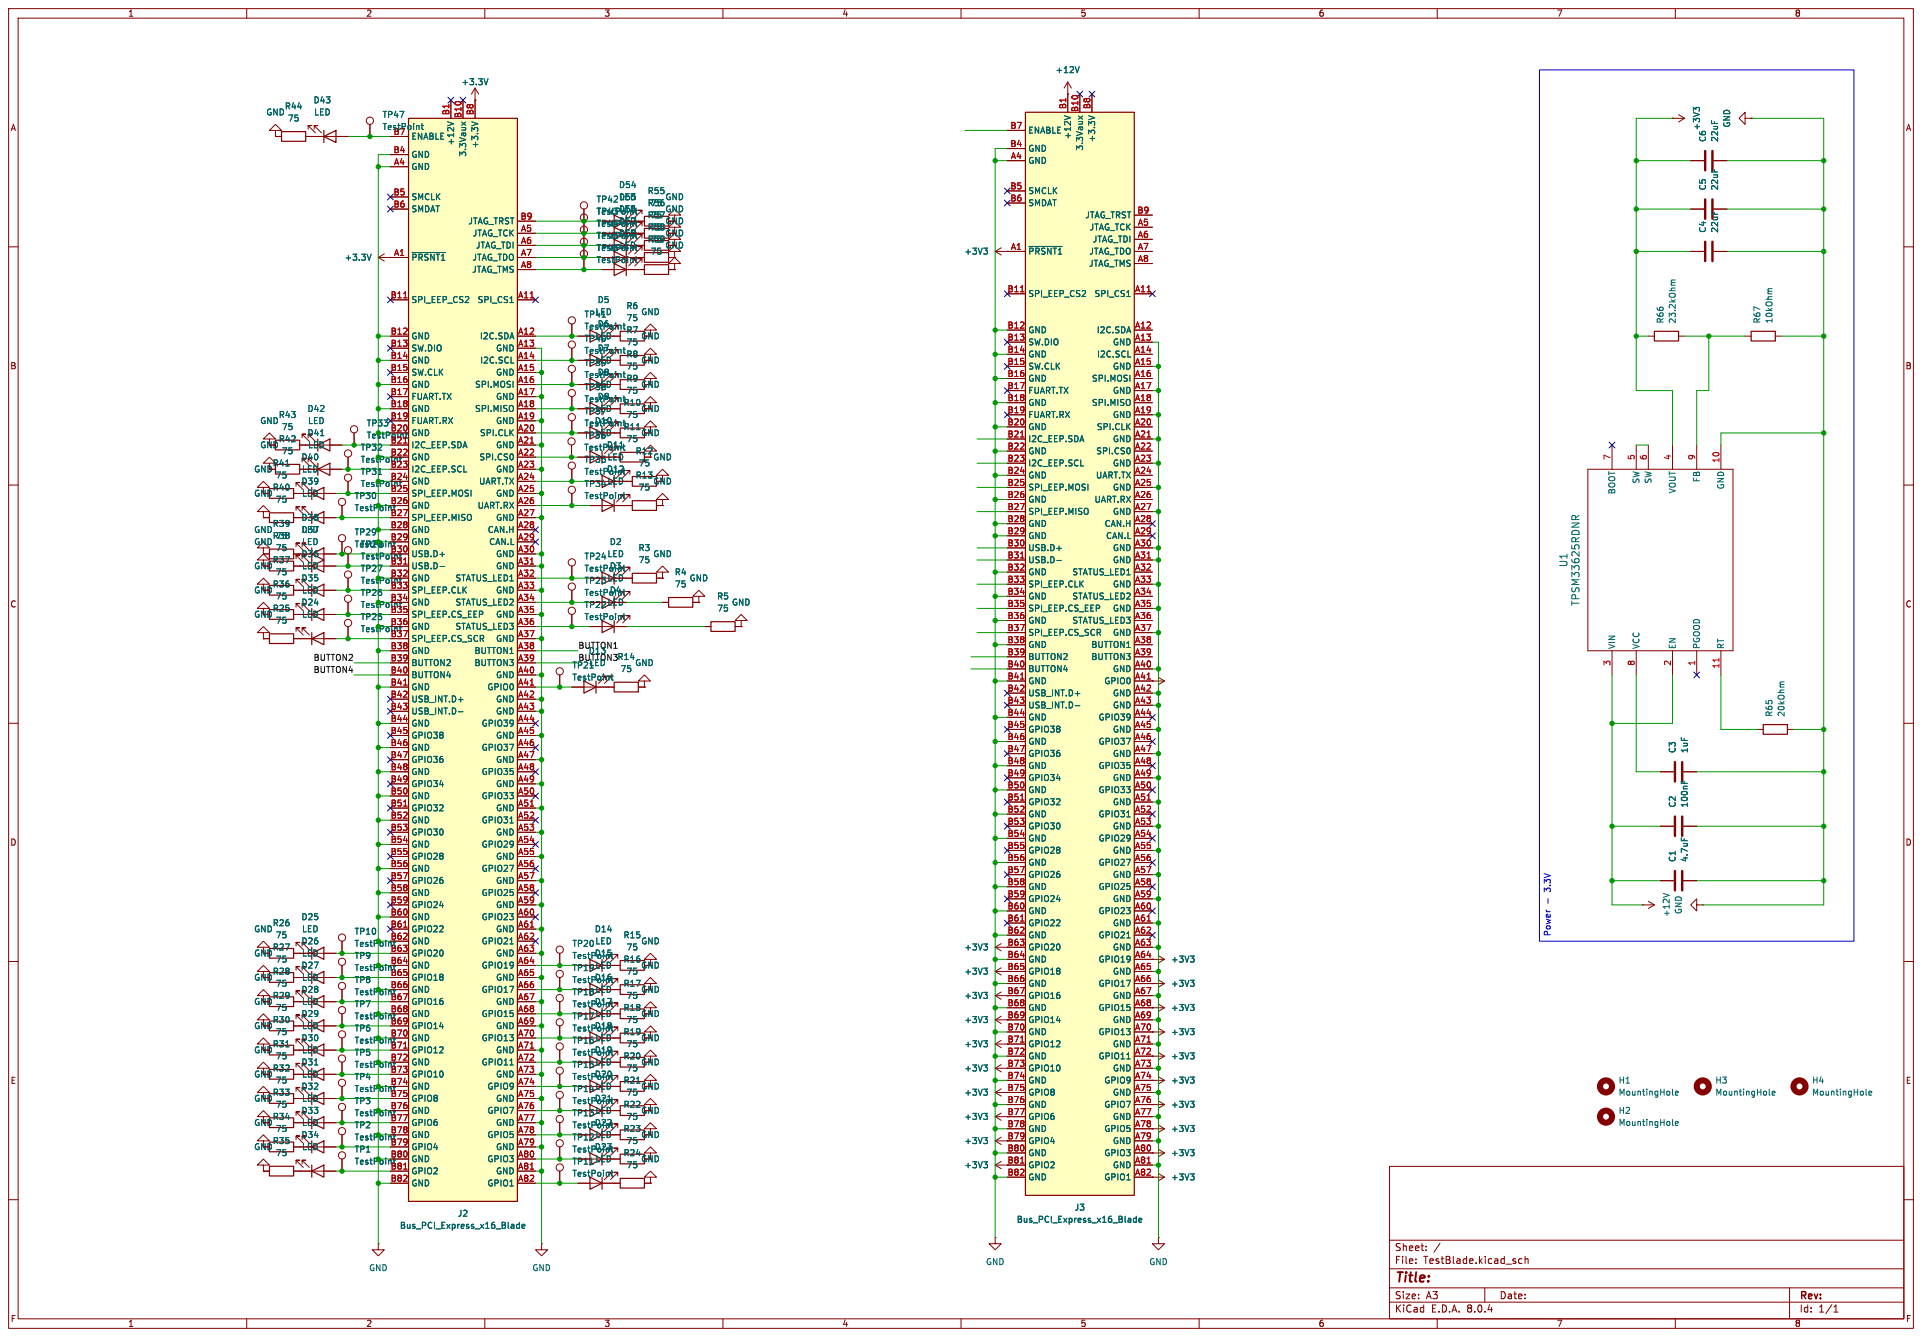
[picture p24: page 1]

GND B4 BUTTON4 B40 GND B41 USB_INT.D+ B42 USB_INT.D- B43 GND B44 GPIO38 B45 GND B46 GPIO36 B47 GND B48 GPIO34 B49
SMCLK B5 GND B50 GPIO32 B51 GND B52 GPIO30 B53 GND B54 GPIO28 B55 GND B56 GPIO26 B57 GND B58 GPIO24 B59
SMDAT B6
JTAG_TCK A5 GPIO33 A50 GND A51 GPIO31 A52 GND A53 GPIO29 A54 GND A55 GPIO27 A56 GND A57 GPIO25 A58 GND A59
JTAG_TDI A6 GPIO23 A60 GND A61 GPIO21 A62 GND A63 GPIO19 A64 GND A65 GPIO17 A66 GND A67 GPIO15 A68 GND A69
JTAG_TDO A7

TP47 TestPoint R44
JTAG_TMS A8

D54 D55 LED
75 GND GND
LED
TP39 TestPoint D5
75 GND
TestPoint TP41 TestPoint D7
D6 TP40LED
I2C.SCL A14 GND A15 SPI.MOSI A16 GND A17 SPI.MISO A18 GND A19 SPI.CLK A20 GND A21 SPI.CS0 A22 GND A23 UART.TX A24 GND A25 UART.RX A26 GND A27 CAN.H A28 CAN.L A29 GND A30 GND A31 STATUS_LED1 A32 GND A33 STATUS_LED2 A34 GND A35 STATUS_LED3 A36 GND A37 BUTTON1 A38 BUTTON3 A39

D56 D57 LED

I2C_EEP.SCL B23 GND B24 SPI_EEP.MOSI B25 GND B26 SPI_EEP.MISO B27 GND B28 GND B29 USB.D+ B30 USB.D- B31 GND B32 SPI_EEP.CLK B33 GND B34 SPI_EEP.CS_EEP B35 GND B36 SPI_EEP.CS_SCR B37 GND B38 BUTTON2 B39

GND B60 GPIO22 B61 GND B62 GPIO20 B63 GND B64 GPIO18 B65 GND B66 GPIO16 B67 GND B68 GPIO14 B69

Id: 1/1 Title: File: TestBlade.kicad_sch Sheet: /

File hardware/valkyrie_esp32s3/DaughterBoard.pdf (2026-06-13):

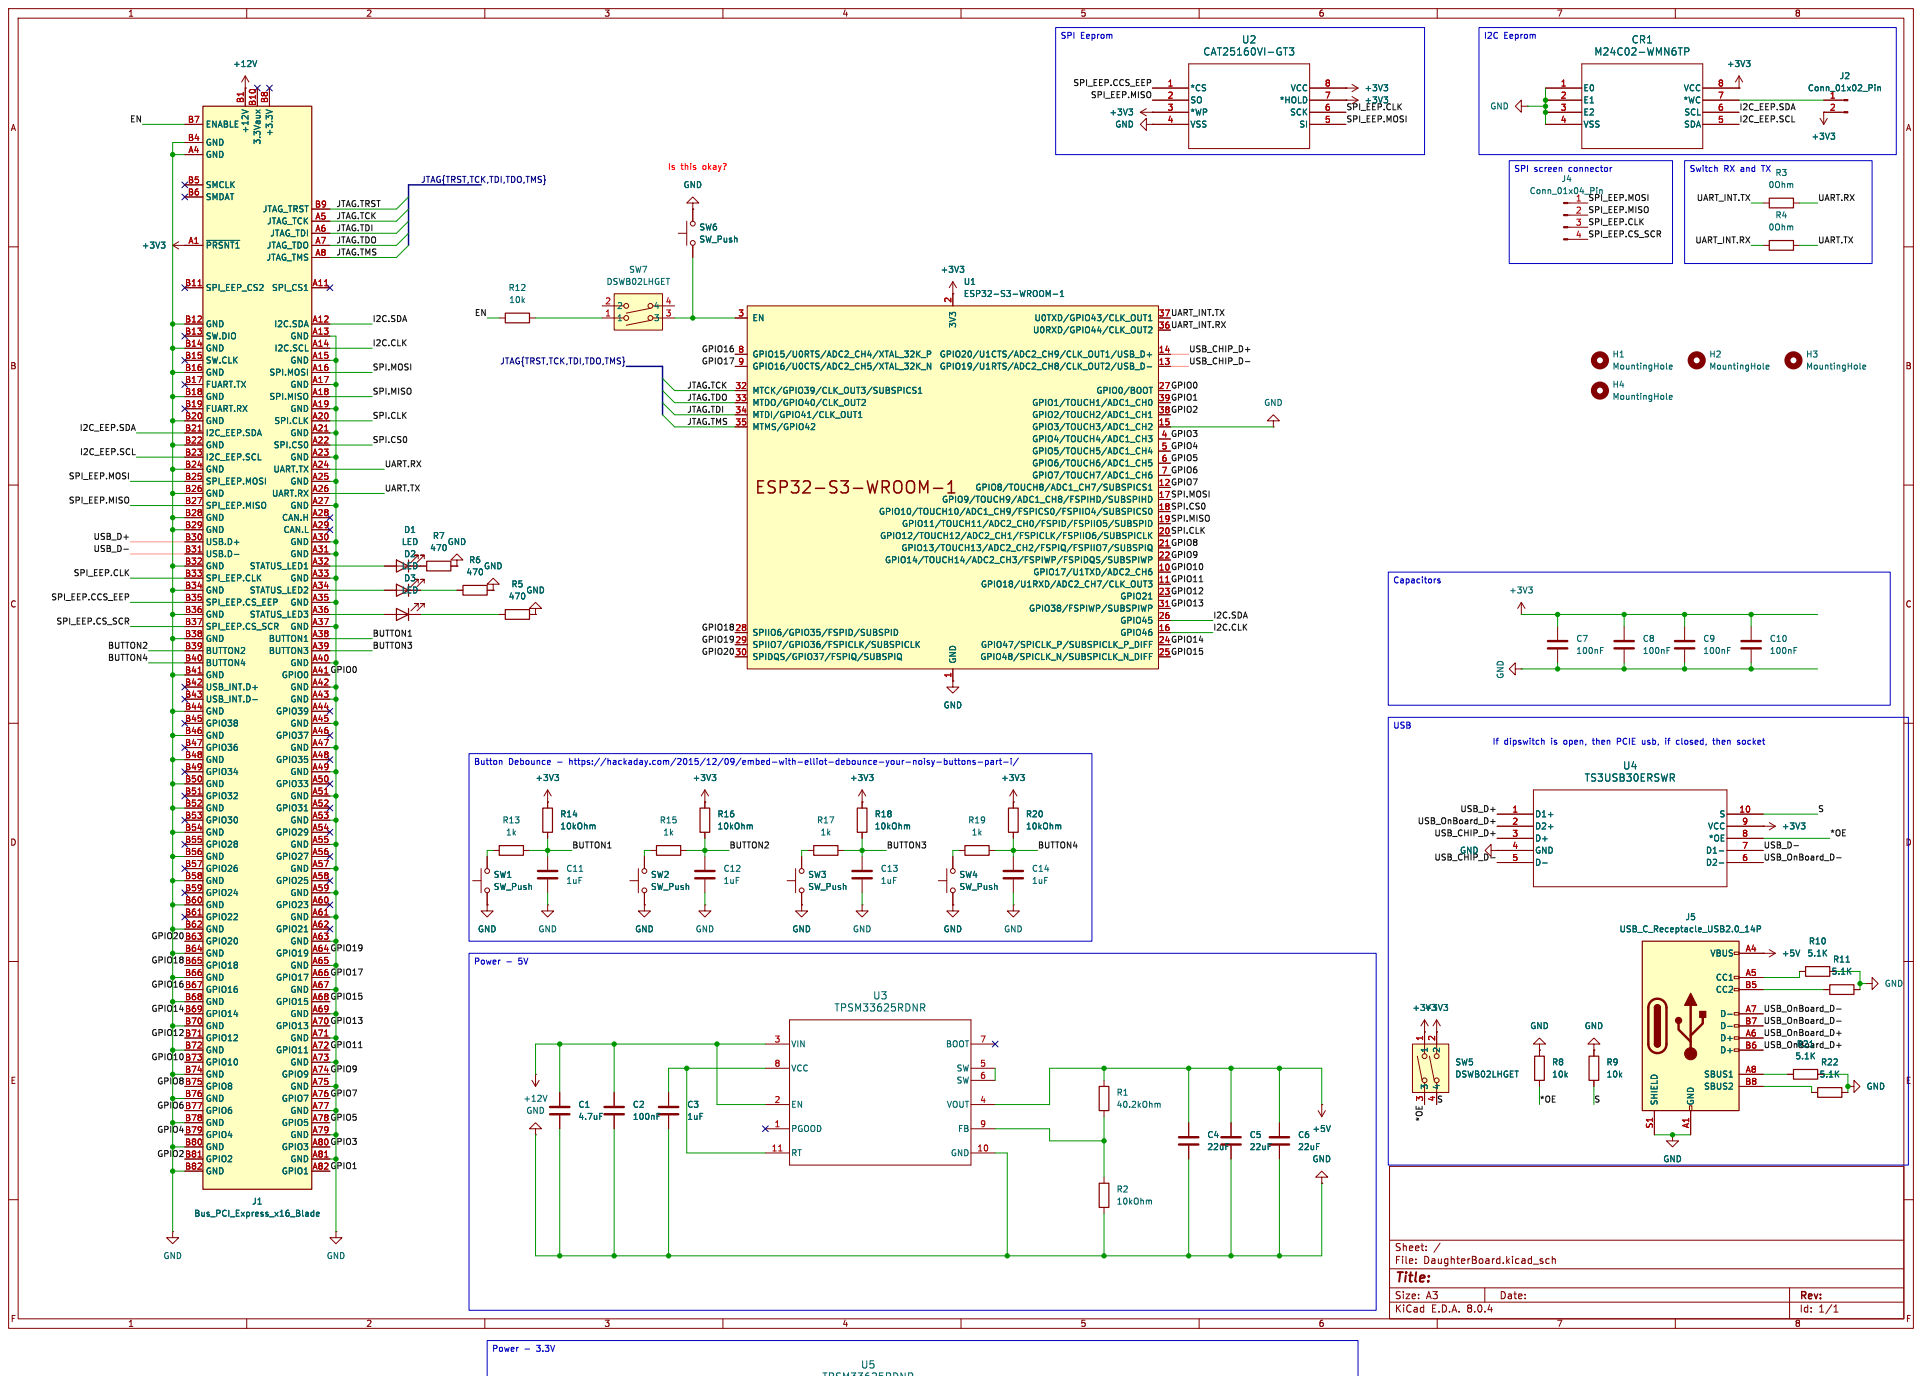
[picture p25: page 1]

SPI screen connector USB

Switch RX and TX

JTAG{TRST,TCK,TDI,TDO,TMS}

2 GPIO12/TOUCH12/ADC2_CH1/FSPICLK/FSPIIO6/SUBSPICLK 20 GPIO13/TOUCH13/ADC2_CH2/FSPIQ/FSPIIO7/SUBSPIQ 21 GPIO14/TOUCH14/ADC2_CH3/FSPIWP/FSPIDQS/SUBSPIWP 22 GPIO21 23 GPIO47/SPICLK_P/SUBSPICLK_P_DIFF 24 GPIO48/SPICLK_N/SUBSPICLK_N_DIFF 25 GPIO45 26 GPIO0/BOOT 27 SPIIO6/GPIO35/FSPID/SUBSPID 28 SPIIO7/GPIO36/FSPICLK/SUBSPICLK 29 EN 3 SPIDQS/GPIO37/FSPIQ/SUBSPIQ 30 GPIO38/FSPIWP/SUBSPIWP 31 MTCK/GPIO39/CLK_OUT3/SUBSPICS1 32 MTDO/GPIO40/CLK_OUT2 33 MTDI/GPIO41/CLK_OUT1 34 MTMS/GPIO42 35 U0RXD/GPIO44/CLK_OUT2 36 U0TXD/GPIO43/CLK_OUT1 37 GPIO2/TOUCH2/ADC1_CH1 38 GPIO1/TOUCH1/ADC1_CH0 39 GPIO4/TOUCH4/ADC1_CH3 4 GPIO5/TOUCH5/ADC1_CH4 5 GPIO6/TOUCH6/ADC1_CH5 6 GPIO7/TOUCH7/ADC1_CH6 7 GPIO15/U0RTS/ADC2_CH4/XTAL_32K_P 8 GPIO16/U0CTS/ADC2_CH5/XTAL_32K_N 9 U1ESP32-S3-WROOM-1

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

1 GPIO17/U1TXD/ADC2_CH6 10 GPIO18/U1RXD/ADC2_CH7/CLK_OUT3 11 GPIO8/TOUCH8/ADC1_CH7/SUBSPICS1 12 GPIO19/U1RTS/ADC2_CH8/CLK_OUT2/USB_D- 13 GPIO20/U1CTS/ADC2_CH9/CLK_OUT1/USB_D+ 14 GPIO3/TOUCH3/ADC1_CH2 15 GPIO46 16 GPIO9/TOUCH9/ADC1_CH8/FSPIHD/SUBSPIHD 17 GPIO10/TOUCH10/ADC1_CH9/FSPICS0/FSPIIO4/SUBSPICS0 18 GPIO11/TOUCH11/ADC2_CH0/FSPID/FSPIIO5/SUBSPID 19 3V3

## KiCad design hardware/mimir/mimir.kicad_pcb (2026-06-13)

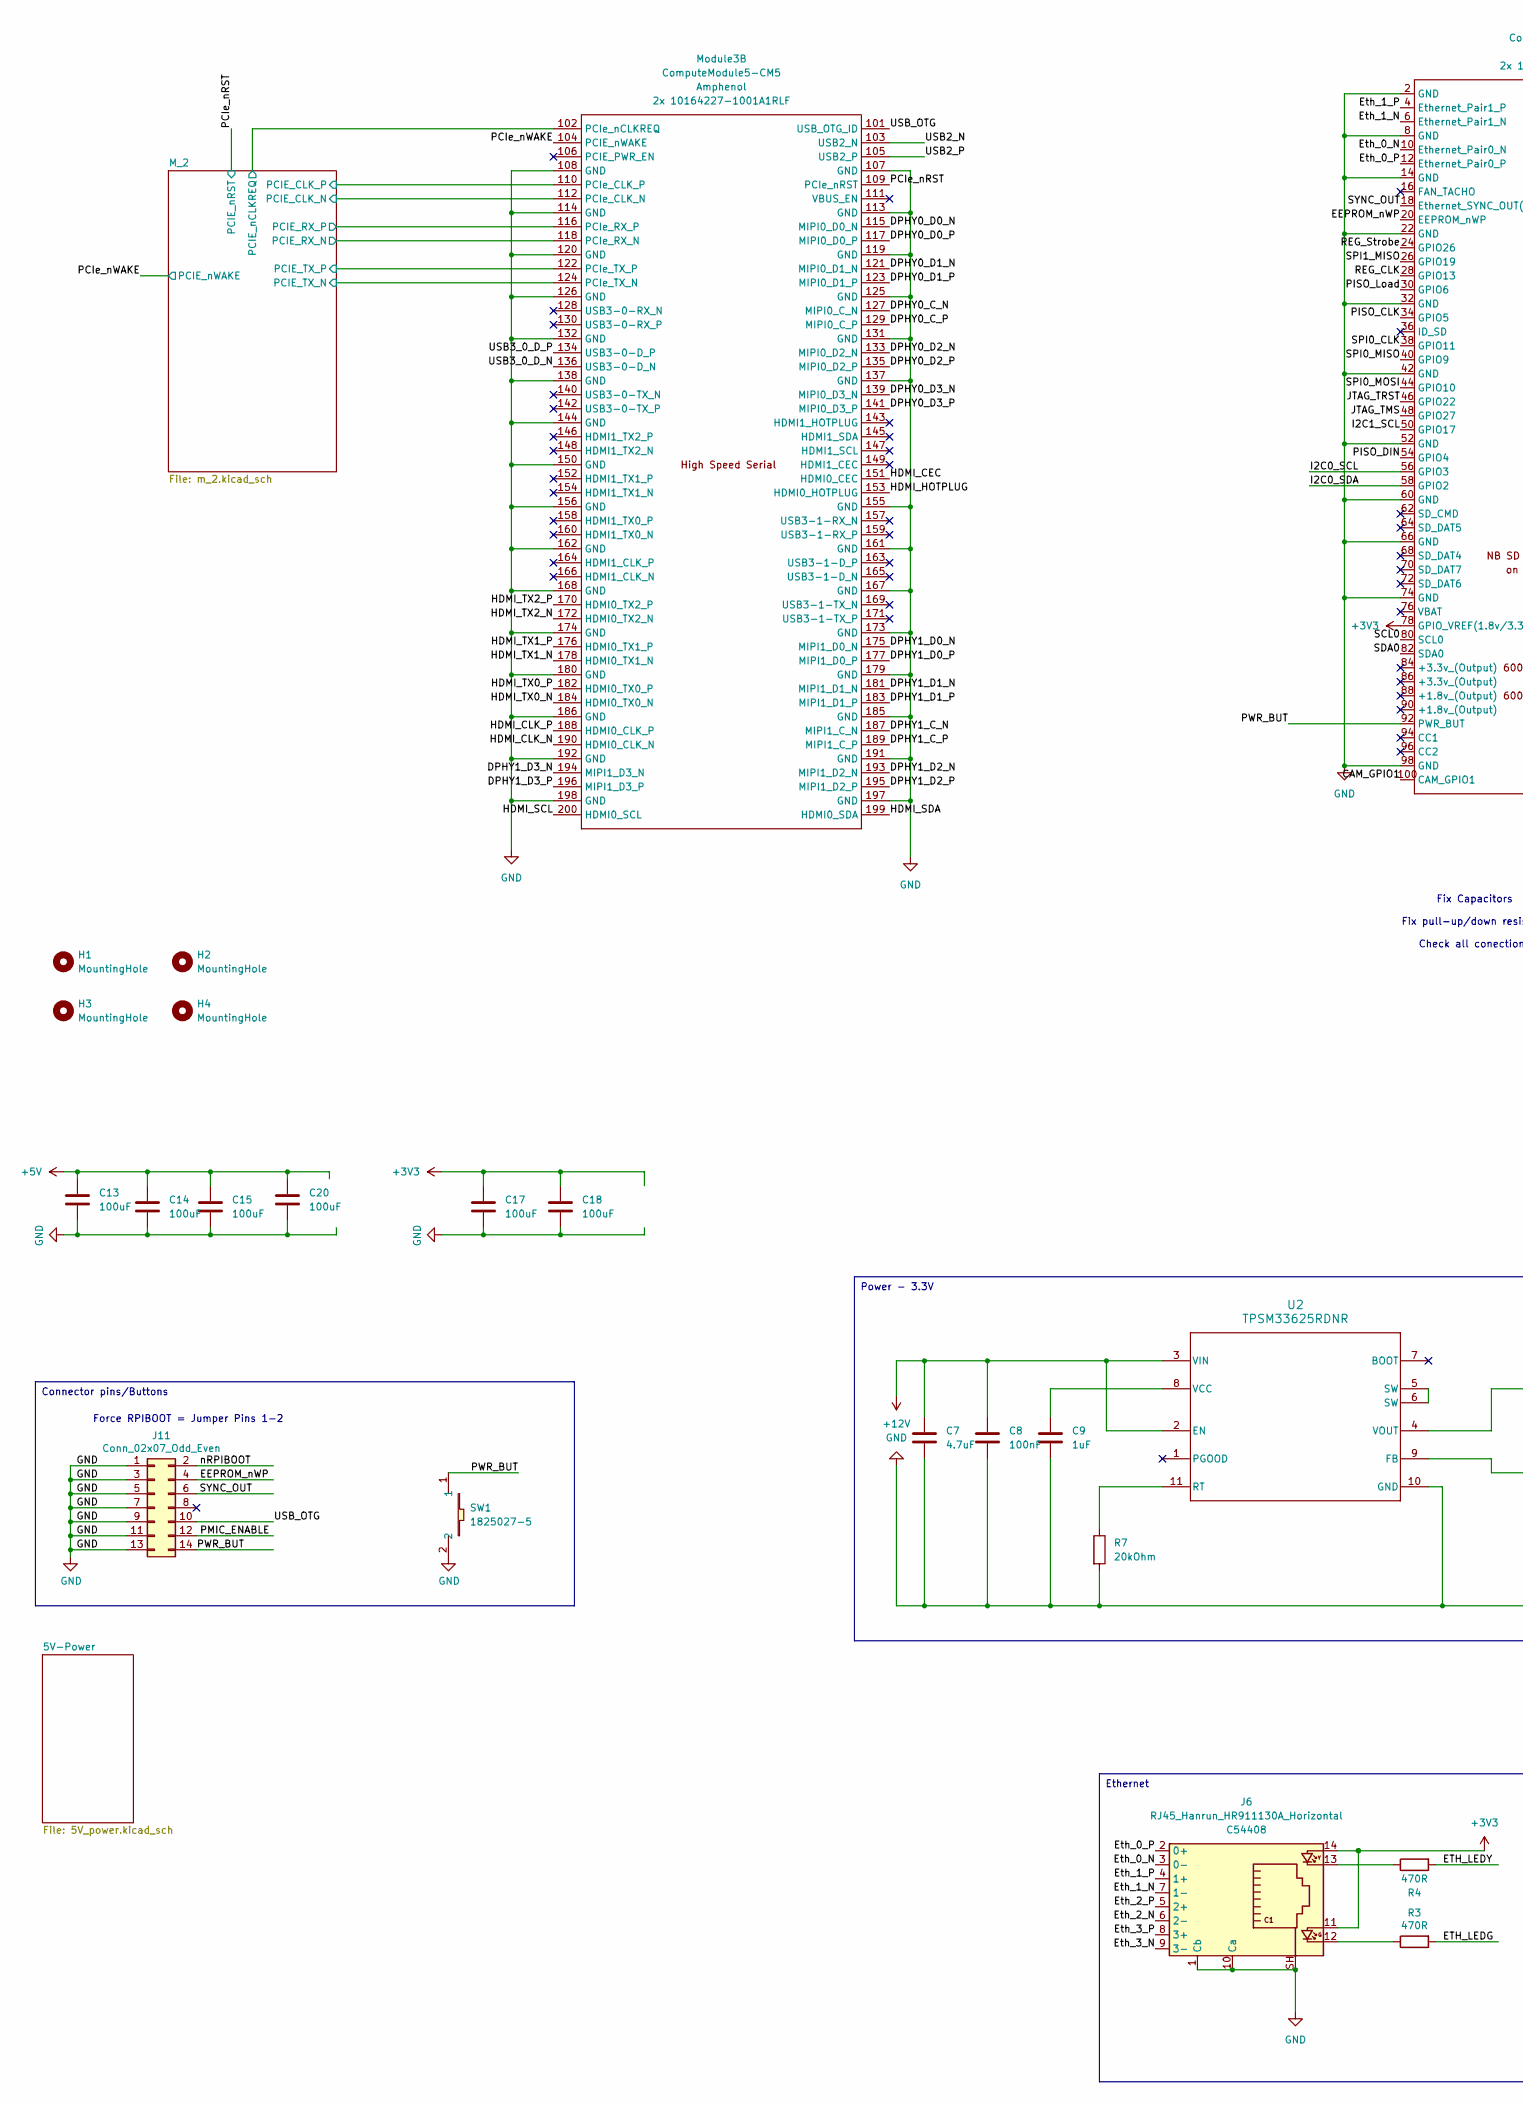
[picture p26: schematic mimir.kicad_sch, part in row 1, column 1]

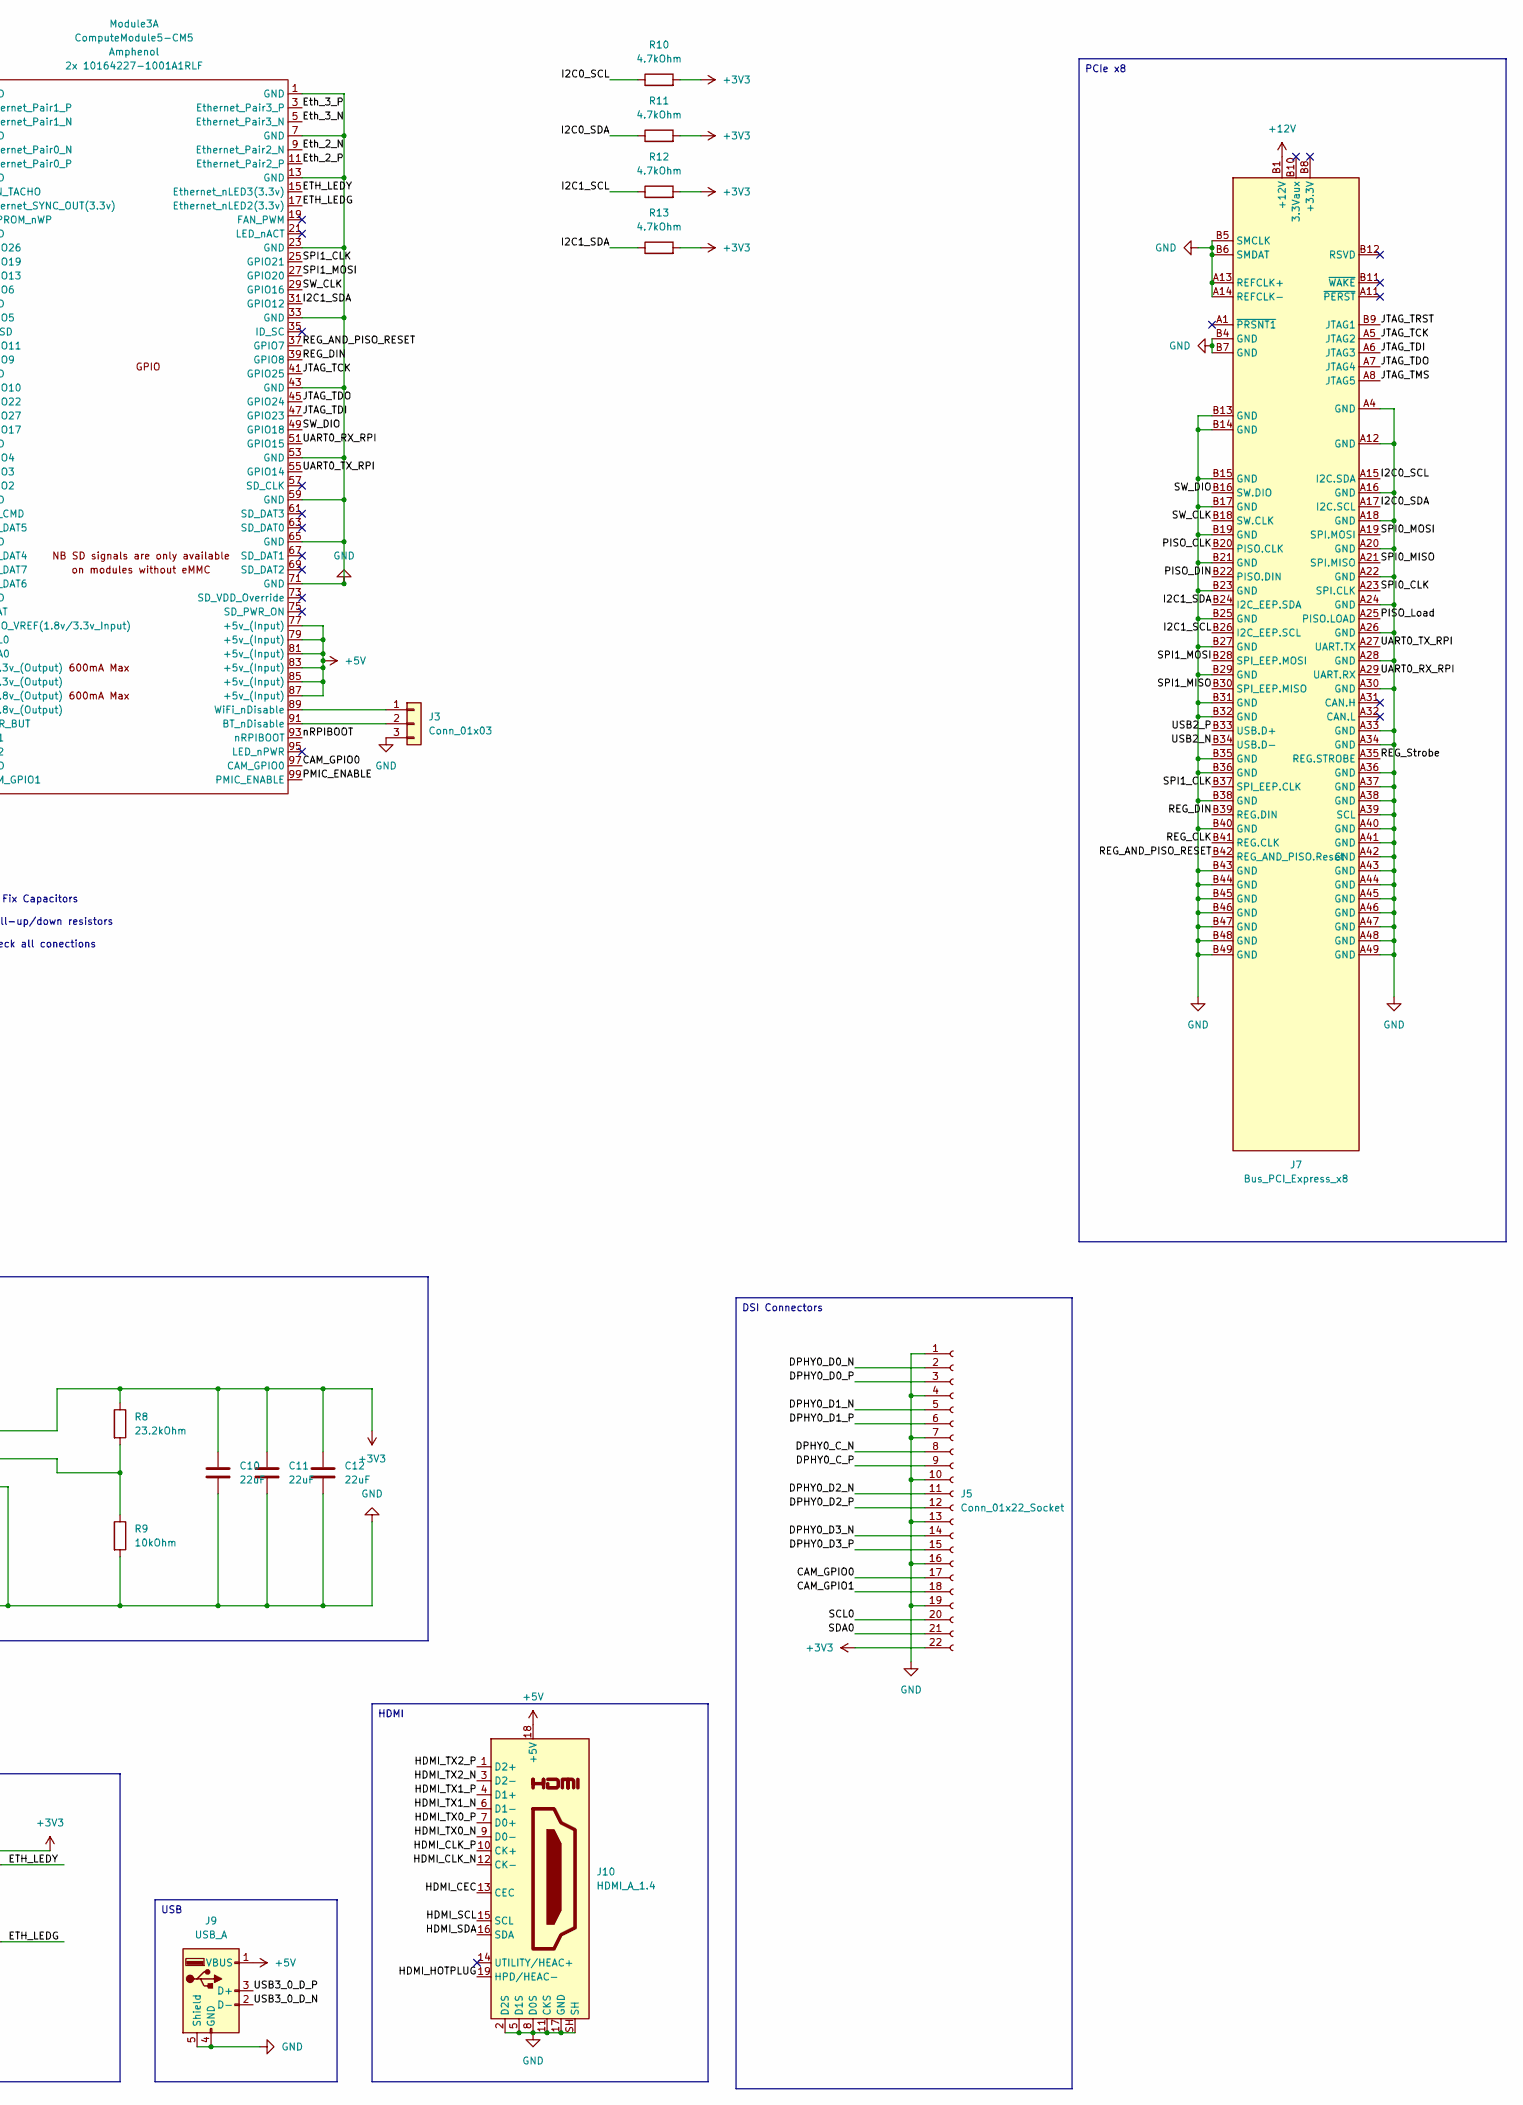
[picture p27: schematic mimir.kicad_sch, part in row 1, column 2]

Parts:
C7: 4.7uF; C_0805_2012Metric
C8: 100nF; C_0805_2012Metric
C9: 1uF; C_0805_2012Metric
C10, C11, C12: 22uF; C_0805_2012Metric
C13, C14, C15, C17, C18, C20: 100uF; C_1210_3225Metric
H1, H2, H3, H4: MountingHole; MountingHole_3.2mm_M3_DIN965_Pad_TopBottom
J3: Conn_01x03; PinHeader_1x03_P2.54mm_Vertical
J5: Conn_01x22_Socket; Hirose_FH12-22S-0.5SH_1x22-1MP_P0.50mm_Horizontal
J6: RJ45_Hanrun_HR911130A_Horizontal; MPN C54408
J7: Bus_PCI_Express_x8; BUS_PCIexpress_x8
J9: USB_A; USB_A_Molex_67643_Horizontal
J10: HDMI_A_1.4; HDMI_A_Molex_208658-1001_Horizontal
J11: Conn_02x07_Odd_Even; PinHeader_2x07_P2.54mm_Vertical; Part Description PinHeader_2x07_P2.54mm_Vertical
Module3: ComputeModule5-CM5; Raspberry-Pi-5-Compute-Module; MPN C597931
R3, R4: 470R; R_0805_2012Metric; Part Description Resistor 470R M1005 1% 63mW
R7: 20kOhm; R_0805_2012Metric
R8: 23.2kOhm; R_0805_2012Metric
R9: 10kOhm; R_0805_2012Metric
R10, R11, R12, R13: 4.7kOhm; R_0805_2012Metric
SW1: 1825027-5; KEY-TH_4P-L7.5-W6.8-P4.50-LS7.2; LCSC Part C86476
U2: TPSM33625RDNR; RDN0011A-MFG_custom

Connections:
+3V3: C10.1, C11.1, C12.1, C17.1, C18.1, J5.22, J6.11, J6.14, Module3.78 (GPIO_VREF(1.8v/3.3v_Input)), R8.1, R10.2, R11.2, R12.2, R13.2, U2.4 (VOUT); also elsewhere on the board
+5V: C13.1, C14.1, C15.1, C20.1, J9.1 (VBUS), J10.18 (+5V), Module3.77 (+5v_(Input)), Module3.79 (+5v_(Input)), Module3.81 (+5v_(Input)), Module3.83 (+5v_(Input)), Module3.85 (+5v_(Input)), Module3.87 (+5v_(Input)); also elsewhere on the board
+12V: C7.1, C8.1, J7.A2 (+12V), J7.A3 (+12V), J7.B1 (+12V), J7.B2 (+12V), J7.B3 (+12V), U2.2 (EN), U2.3 (VIN); also elsewhere on the board
/CAM_GPIO0: J5.17, Module3.97 (CAM_GPIO0)
/CAM_GPIO1: J5.18, Module3.100 (CAM_GPIO1)
/DPHY0_C_N: J5.8, Module3.127 (MIPI0_C_N)
/DPHY0_C_P: J5.9, Module3.129 (MIPI0_C_P)
/DPHY0_D0_N: J5.2, Module3.115 (MIPI0_D0_N)
/DPHY0_D0_P: J5.3, Module3.117 (MIPI0_D0_P)
/DPHY0_D1_N: J5.5, Module3.121 (MIPI0_D1_N)
/DPHY0_D1_P: J5.6, Module3.123 (MIPI0_D1_P)
/DPHY0_D2_N: J5.11, Module3.133 (MIPI0_D2_N)
/DPHY0_D2_P: J5.12, Module3.135 (MIPI0_D2_P)
/DPHY0_D3_N: J5.14, Module3.139 (MIPI0_D3_N)
/DPHY0_D3_P: J5.15, Module3.141 (MIPI0_D3_P)
/DPHY1_C_N: Module3.187 (MIPI1_C_N)
/DPHY1_C_P: Module3.189 (MIPI1_C_P)
/DPHY1_D0_N: Module3.175 (MIPI1_D0_N)
/DPHY1_D0_P: Module3.177 (MIPI1_D0_P)
/DPHY1_D1_N: Module3.181 (MIPI1_D1_N)
/DPHY1_D1_P: Module3.183 (MIPI1_D1_P)
/DPHY1_D2_N: Module3.193 (MIPI1_D2_N)
/DPHY1_D2_P: Module3.195 (MIPI1_D2_P)
/DPHY1_D3_N: Module3.194 (MIPI1_D3_N)
/DPHY1_D3_P: Module3.196 (MIPI1_D3_P)
/EEPROM_nWP: J11.4, Module3.20 (EEPROM_nWP)
/ETH_LEDG: Module3.17 (Ethernet_nLED2(3.3v)), R3.2
/ETH_LEDY: Module3.15 (Ethernet_nLED3(3.3v)), R4.2
/Eth_0_N: J6.3 (0-), Module3.10 (Ethernet_Pair0_N)
/Eth_0_P: J6.2 (0+), Module3.12 (Ethernet_Pair0_P)
/Eth_1_N: J6.7 (1-), Module3.6 (Ethernet_Pair1_N)
/Eth_1_P: J6.4 (1+), Module3.4 (Ethernet_Pair1_P)
/Eth_2_N: J6.6 (2-), Module3.9 (Ethernet_Pair2_N)
/Eth_2_P: J6.5 (2+), Module3.11 (Ethernet_Pair2_P)
/Eth_3_N: J6.9 (3-), Module3.5 (Ethernet_Pair3_N)
/Eth_3_P: J6.8 (3+), Module3.3 (Ethernet_Pair3_P)
/HDMI_CEC: J10.13 (CEC), Module3.151 (HDMI0_CEC)
/HDMI_CLK_N: J10.12 (CK-), Module3.190 (HDMI0_CLK_N)
/HDMI_CLK_P: J10.10 (CK+), Module3.188 (HDMI0_CLK_P)
/HDMI_HOTPLUG: J10.19 (HPD/HEAC-), Module3.153 (HDMI0_HOTPLUG)
/HDMI_SCL: J10.15 (SCL), Module3.200 (HDMI0_SCL)
/HDMI_SDA: J10.16 (SDA), Module3.199 (HDMI0_SDA)
/HDMI_TX0_N: J10.9 (D0-), Module3.184 (HDMI0_TX0_N)
/HDMI_TX0_P: J10.7 (D0+), Module3.182 (HDMI0_TX0_P)
/HDMI_TX1_N: J10.6 (D1-), Module3.178 (HDMI0_TX1_N)
/HDMI_TX1_P: J10.4 (D1+), Module3.176 (HDMI0_TX1_P)
/HDMI_TX2_N: J10.3 (D2-), Module3.172 (HDMI0_TX2_N)
/HDMI_TX2_P: J10.1 (D2+), Module3.170 (HDMI0_TX2_P)
/I2C0_SCL: J7.A15 (I2C.SDA), Module3.56 (GPIO3), R10.1
/I2C0_SDA: J7.A17 (I2C.SCL), Module3.58 (GPIO2), R11.1
/I2C1_SCL: J7.B26 (I2C_EEP.SCL), Module3.50 (GPIO17), R12.1
/I2C1_SDA: J7.B24 (I2C_EEP.SDA), Module3.31 (GPIO12), R13.1
/JTAG_TCK: J7.A5 (JTAG2), Module3.41 (GPIO25)
/JTAG_TDI: J7.A6 (JTAG3), Module3.47 (GPIO23)
/JTAG_TDO: J7.A7 (JTAG4), Module3.45 (GPIO24)
/JTAG_TMS: J7.A8 (JTAG5), Module3.48 (GPIO27)
/JTAG_TRST: J7.B9 (JTAG1), Module3.46 (GPIO22)
/M_2/PCIE_CLK_N: Module3.112 (PCIe_CLK_N); also elsewhere on the board
/M_2/PCIE_CLK_P: Module3.110 (PCIe_CLK_P); also elsewhere on the board
/M_2/PCIE_RX_N: Module3.118 (PCIe_RX_N); also elsewhere on the board
/M_2/PCIE_RX_P: Module3.116 (PCIe_RX_P); also elsewhere on the board
/M_2/PCIE_TX_N: Module3.124 (PCIe_TX_N); also elsewhere on the board
/M_2/PCIE_TX_P: Module3.122 (PCIe_TX_P); also elsewhere on the board
/M_2/PCIE_nCLKREQ: Module3.102 (PCIe_nCLKREQ); also elsewhere on the board
/PCIe_nRST: Module3.109 (PCIe_nRST); also elsewhere on the board
/PCIe_nWAKE: Module3.104 (PCIE_nWAKE); also elsewhere on the board
/PISO_CLK: J7.B20 (PISO.CLK), Module3.34 (GPIO5)
/PISO_DIN: J7.B22 (PISO.DIN), Module3.54 (GPIO4)
/PISO_Load: J7.A25 (PISO.LOAD), Module3.30 (GPIO6)
/PMIC_ENABLE: J11.12, Module3.99 (PMIC_ENABLE)
/PWR_BUT: J11.14, Module3.92 (PWR_BUT), SW1.1
/REG_AND_PISO_RESET: J7.B42 (REG_AND_PISO.Reset), Module3.37 (GPIO7)
/REG_CLK: J7.B41 (REG.CLK), Module3.28 (GPIO13)
/REG_DIN: J7.B39 (REG.DIN), Module3.39 (GPIO8)
/REG_Strobe: J7.A35 (REG.STROBE), Module3.24 (GPIO26)
/SCL0: J5.20, Module3.80 (SCL0)
/SDA0: J5.21, Module3.82 (SDA0)
/SPI0_CLK: J7.A23 (SPI.CLK), Module3.38 (GPIO11)
/SPI0_MISO: J7.A21 (SPI.MISO), Module3.40 (GPIO9)
/SPI0_MOSI: J7.A19 (SPI.MOSI), Module3.44 (GPIO10)
/SPI1_CLK: J7.B37 (SPI_EEP.CLK), Module3.25 (GPIO21)
/SPI1_MISO: J7.B30 (SPI_EEP.MISO), Module3.26 (GPIO19)
/SPI1_MOSI: J7.B28 (SPI_EEP.MOSI), Module3.27 (GPIO20)
/SW_CLK: J7.B18 (SW.CLK), Module3.29 (GPIO16)
/SW_DIO: J7.B16 (SW.DIO), Module3.49 (GPIO18)
/SYNC_OUT: J11.6, Module3.18 (Ethernet_SYNC_OUT(3.3v))
/UART0_RX_RPI: J7.A29 (UART.RX), Module3.51 (GPIO15)
/UART0_TX_RPI: J7.A27 (UART.TX), Module3.55 (GPIO14)
/USB2_N: J7.B34 (USB.D-), Module3.103 (USB2_N)
/USB2_P: J7.B33 (USB.D+), Module3.105 (USB2_P)
/USB3_0_D_N: J9.2 (D-), Module3.136 (USB3-0-D_N)
/USB3_0_D_P: J9.3 (D+), Module3.134 (USB3-0-D_P)
/USB_OTG: J11.10, Module3.101 (USB_OTG_ID)
/nRPIBOOT: J11.2, Module3.93 (nRPIBOOT)
GND: C7.2, C8.2, C9.2, C10.2, C11.2, C12.2, C13.2, C14.2, C15.2, C17.2, C18.2, C20.2, J3.3, J5.1, J5.4, J5.7, J5.10, J5.13, J5.16, J5.19, J6.1 (Cb), J6.10 (Ca), J6.SH, J7.A4 (GND), J7.A12 (GND), J7.A13 (REFCLK+), J7.A14 (REFCLK-), J7.A16 (GND), J7.A18 (GND), J7.A20 (GND), J7.A22 (GND), J7.A24 (GND), J7.A26 (GND), J7.A28 (GND), J7.A30 (GND), J7.A33 (GND), J7.A34 (GND), J7.A36 (GND), J7.A37 (GND), J7.A38 (GND), J7.A39 (SCL), J7.A40 (GND), J7.A41 (GND), J7.A42 (GND), J7.A43 (GND), J7.A44 (GND), J7.A45 (GND), J7.A46 (GND), J7.A47 (GND), J7.A48 (GND), J7.A49 (GND), J7.B4 (GND), J7.B5 (SMCLK), J7.B6 (SMDAT), J7.B7 (GND), J7.B13 (GND), J7.B14 (GND), J7.B15 (GND), J7.B17 (GND), J7.B19 (GND), J7.B21 (GND), J7.B23 (GND), J7.B25 (GND), J7.B27 (GND), J7.B29 (GND), J7.B31 (GND), J7.B32 (GND), J7.B35 (GND), J7.B36 (GND), J7.B38 (GND), J7.B40 (GND), J7.B43 (GND), J7.B44 (GND), J7.B45 (GND), J7.B46 (GND), J7.B47 (GND), J7.B48 (GND), J7.B49 (GND), J9.4 (GND), J9.5 (Shield), J10.2 (D2S), J10.5 (D1S), J10.8 (D0S), J10.11 (CKS), J10.17 (GND), J10.SH, J11.1, J11.3, J11.5, J11.7, J11.9, J11.11, J11.13, Module3.1 (GND), Module3.2 (GND), Module3.7 (GND), Module3.8 (GND), Module3.13 (GND), Module3.14 (GND), Module3.22 (GND), Module3.23 (GND), Module3.32 (GND), Module3.33 (GND), Module3.42 (GND), Module3.43 (GND), Module3.52 (GND), Module3.53 (GND), Module3.59 (GND), Module3.60 (GND), Module3.65 (GND), Module3.66 (GND), Module3.71 (GND), Module3.74 (GND), Module3.98 (GND), Module3.107 (GND), Module3.108 (GND), Module3.113 (GND), Module3.114 (GND), Module3.119 (GND), Module3.120 (GND), Module3.125 (GND), Module3.126 (GND), Module3.131 (GND), Module3.132 (GND), Module3.137 (GND), Module3.138 (GND), Module3.144 (GND), Module3.150 (GND), Module3.155 (GND), Module3.156 (GND), Module3.161 (GND), Module3.162 (GND), Module3.167 (GND), Module3.168 (GND), Module3.173 (GND), Module3.174 (GND), Module3.179 (GND), Module3.180 (GND), Module3.185 (GND), Module3.186 (GND), Module3.191 (GND), Module3.192 (GND), Module3.197 (GND), Module3.198 (GND), R7.2, R9.2, SW1.2, U2.10 (GND); also elsewhere on the board
unnamed: J3.1, Module3.89 (WiFi_nDisable)
unnamed: J3.2, Module3.91 (BT_nDisable)
unnamed: J6.12, R3.1
unnamed: J6.13, R4.1
unnamed: R8.2, R9.1, U2.9 (FB)
unnamed: R7.1, U2.11 (RT)
unnamed: U2.5 (SW), U2.6 (SW)
unnamed: C9.1, U2.8 (VCC)

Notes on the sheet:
Ethernet
Connector pins/Buttons
USB
Power - 3.3V
HDMI
PCIe x8
DSI Connectors
Force RPIBOOT = Jumper Pins 1-2
Fix Capacitors Fix pull-up/down resistors Check all conections

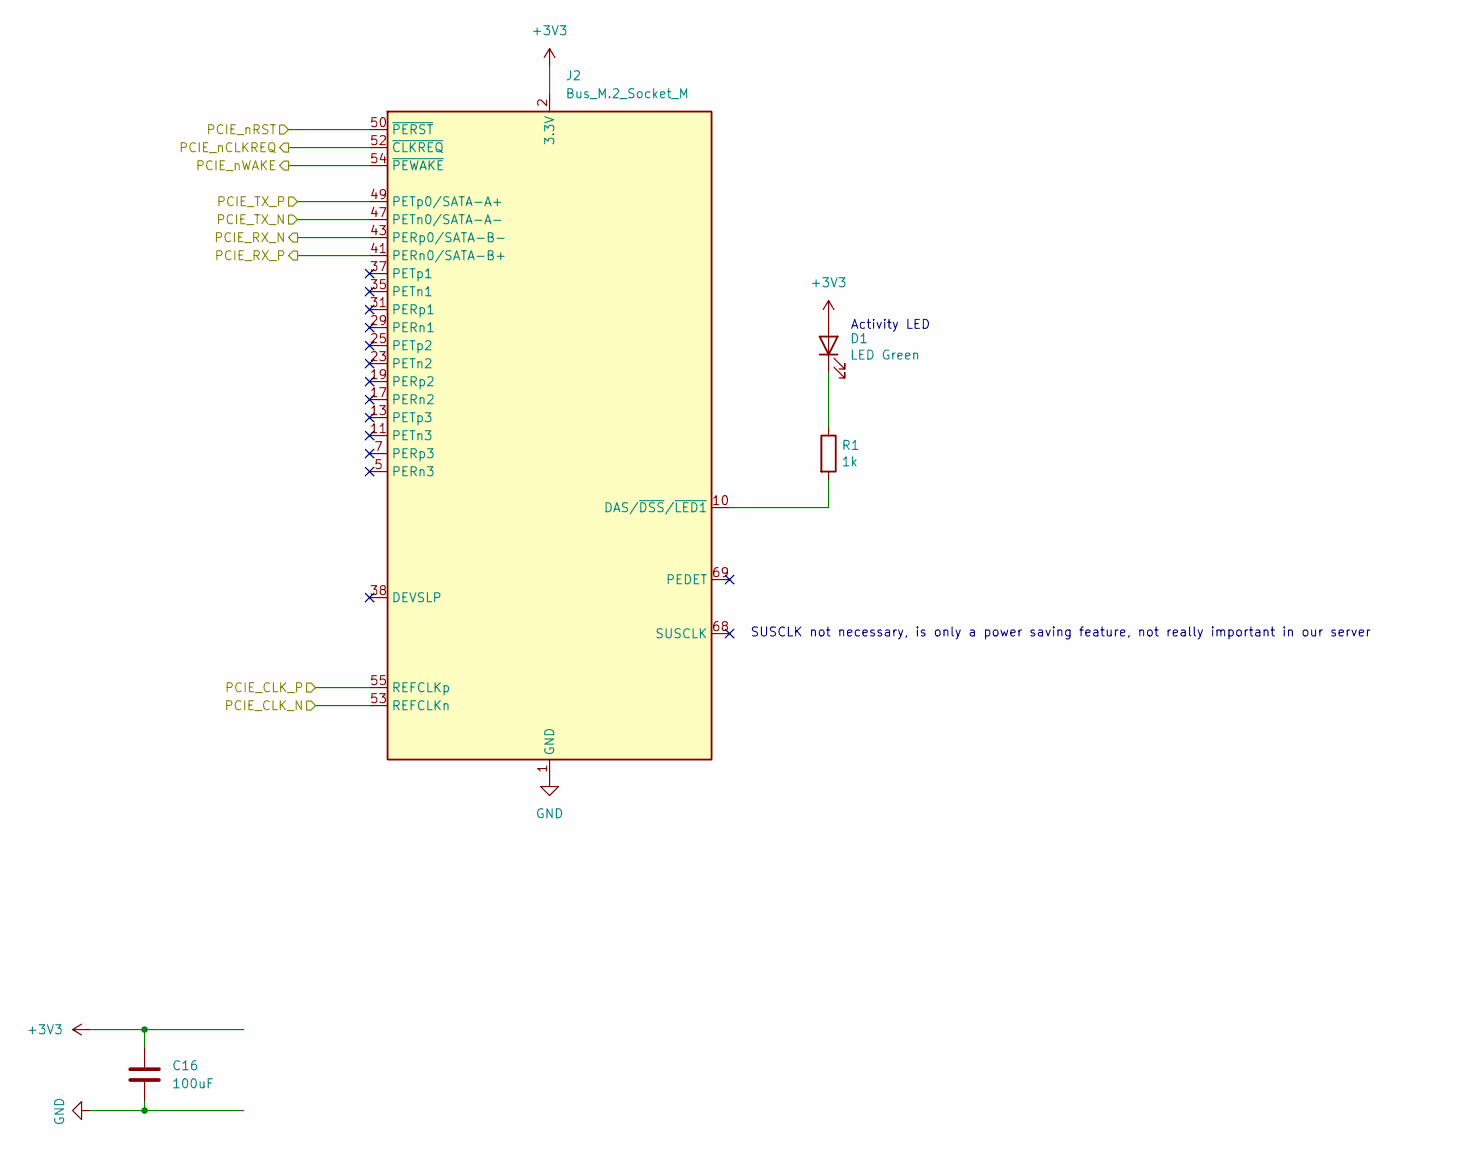
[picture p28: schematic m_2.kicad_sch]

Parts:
C16: 100uF; C_1210_3225Metric
D1: LED Green; LED_0603_1608Metric; Part Description Green 572nm LED Indication - Discrete 2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
J2: Bus_M.2_Socket_M; M.2 M Key socket
R1: 1k; R_0805_2012Metric; Part Description Resistor 1K M1005 1% 63mW

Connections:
+3V3: C16.1, D1.2 (A), J2.2 (3.3V), J2.4 (3.3V), J2.12 (3.3V), J2.14 (3.3V), J2.16 (3.3V), J2.18 (3.3V), J2.70 (3.3V), J2.72 (3.3V), J2.74 (3.3V); also elsewhere on the board
/M_2/PCIE_CLK_N: J2.53 (REFCLKn); also elsewhere on the board
/M_2/PCIE_CLK_P: J2.55 (REFCLKp); also elsewhere on the board
/M_2/PCIE_RX_N: J2.43 (PERp0/SATA-B-); also elsewhere on the board
/M_2/PCIE_RX_P: J2.41 (PERn0/SATA-B+); also elsewhere on the board
/M_2/PCIE_TX_N: J2.47 (PETn0/SATA-A-); also elsewhere on the board
/M_2/PCIE_TX_P: J2.49 (PETp0/SATA-A+); also elsewhere on the board
/M_2/PCIE_nCLKREQ: J2.52 (~CLKREQ); also elsewhere on the board
/PCIe_nRST: J2.50 (~PERST); also elsewhere on the board
/PCIe_nWAKE: J2.54 (~PEWAKE); also elsewhere on the board
GND: C16.2, J2.1 (GND), J2.3 (GND), J2.9 (GND), J2.15 (GND), J2.21 (GND), J2.27 (GND), J2.33 (GND), J2.39 (GND), J2.45 (GND), J2.51 (GND), J2.57 (GND), J2.71 (GND), J2.73 (GND), J2.75 (GND); also elsewhere on the board
unnamed: D1.1 (K), R1.1
unnamed: J2.10 (DAS/~DSS/~LED1), R1.2

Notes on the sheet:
SUSCLK not necessary, is only a power saving feature, not really important in our server
Activity LED

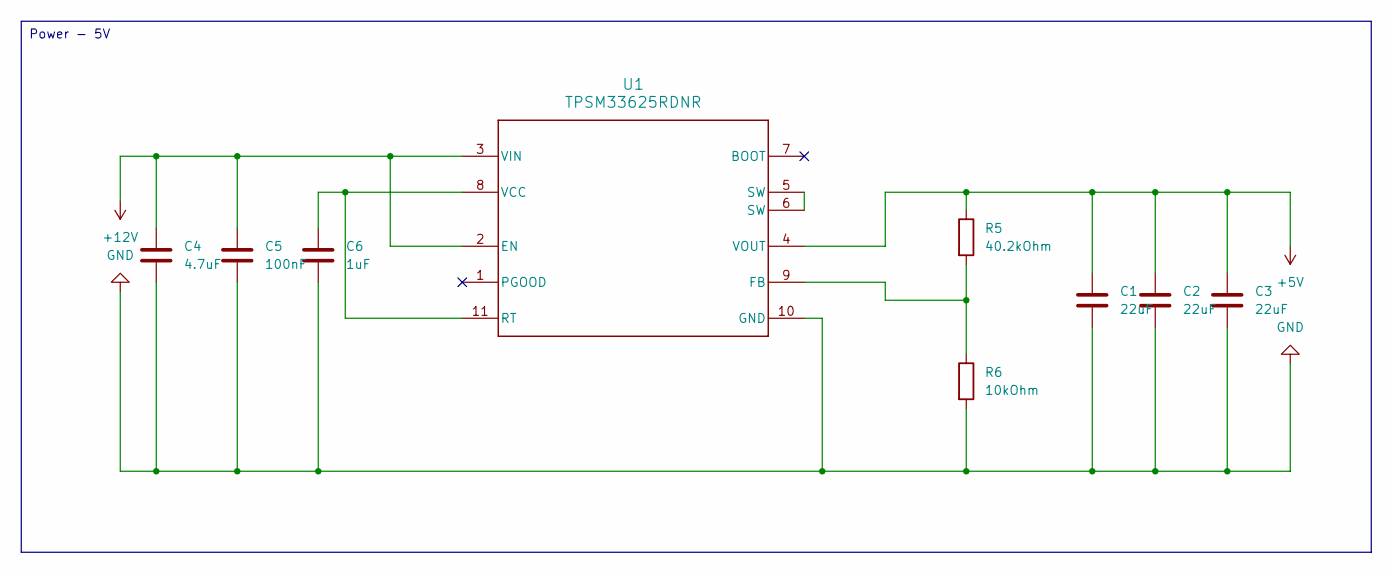
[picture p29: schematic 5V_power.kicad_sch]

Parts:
C1, C2, C3: 22uF; C_0805_2012Metric
C4: 4.7uF; C_0805_2012Metric
C5: 100nF; C_0805_2012Metric
C6: 1uF; C_0805_2012Metric
R5: 40.2kOhm; R_0805_2012Metric
R6: 10kOhm; R_0805_2012Metric
U1: TPSM33625RDNR; RDN0011A-MFG_custom

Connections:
+5V: C1.1, C2.1, C3.1, R5.1, U1.4 (VOUT); also elsewhere on the board
+12V: C4.1, C5.1, U1.2 (EN), U1.3 (VIN); also elsewhere on the board
GND: C1.2, C2.2, C3.2, C4.2, C5.2, C6.2, R6.2, U1.10 (GND); also elsewhere on the board
unnamed: R5.2, R6.1, U1.9 (FB)
unnamed: C6.1, U1.8 (VCC), U1.11 (RT)
unnamed: U1.5 (SW), U1.6 (SW)

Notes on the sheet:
Power - 5V

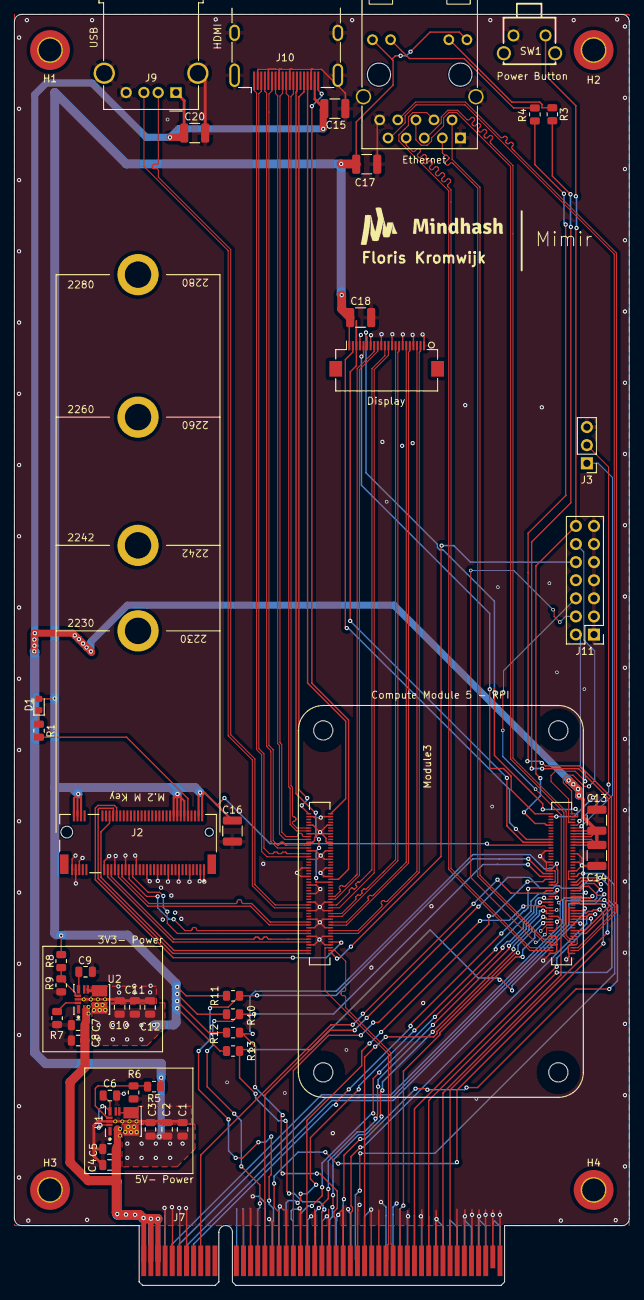
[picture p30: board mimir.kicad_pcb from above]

Board: 4 copper layers, 86.3 x 178.4 mm, 48 parts (0 on the bottom side), 98 nets.

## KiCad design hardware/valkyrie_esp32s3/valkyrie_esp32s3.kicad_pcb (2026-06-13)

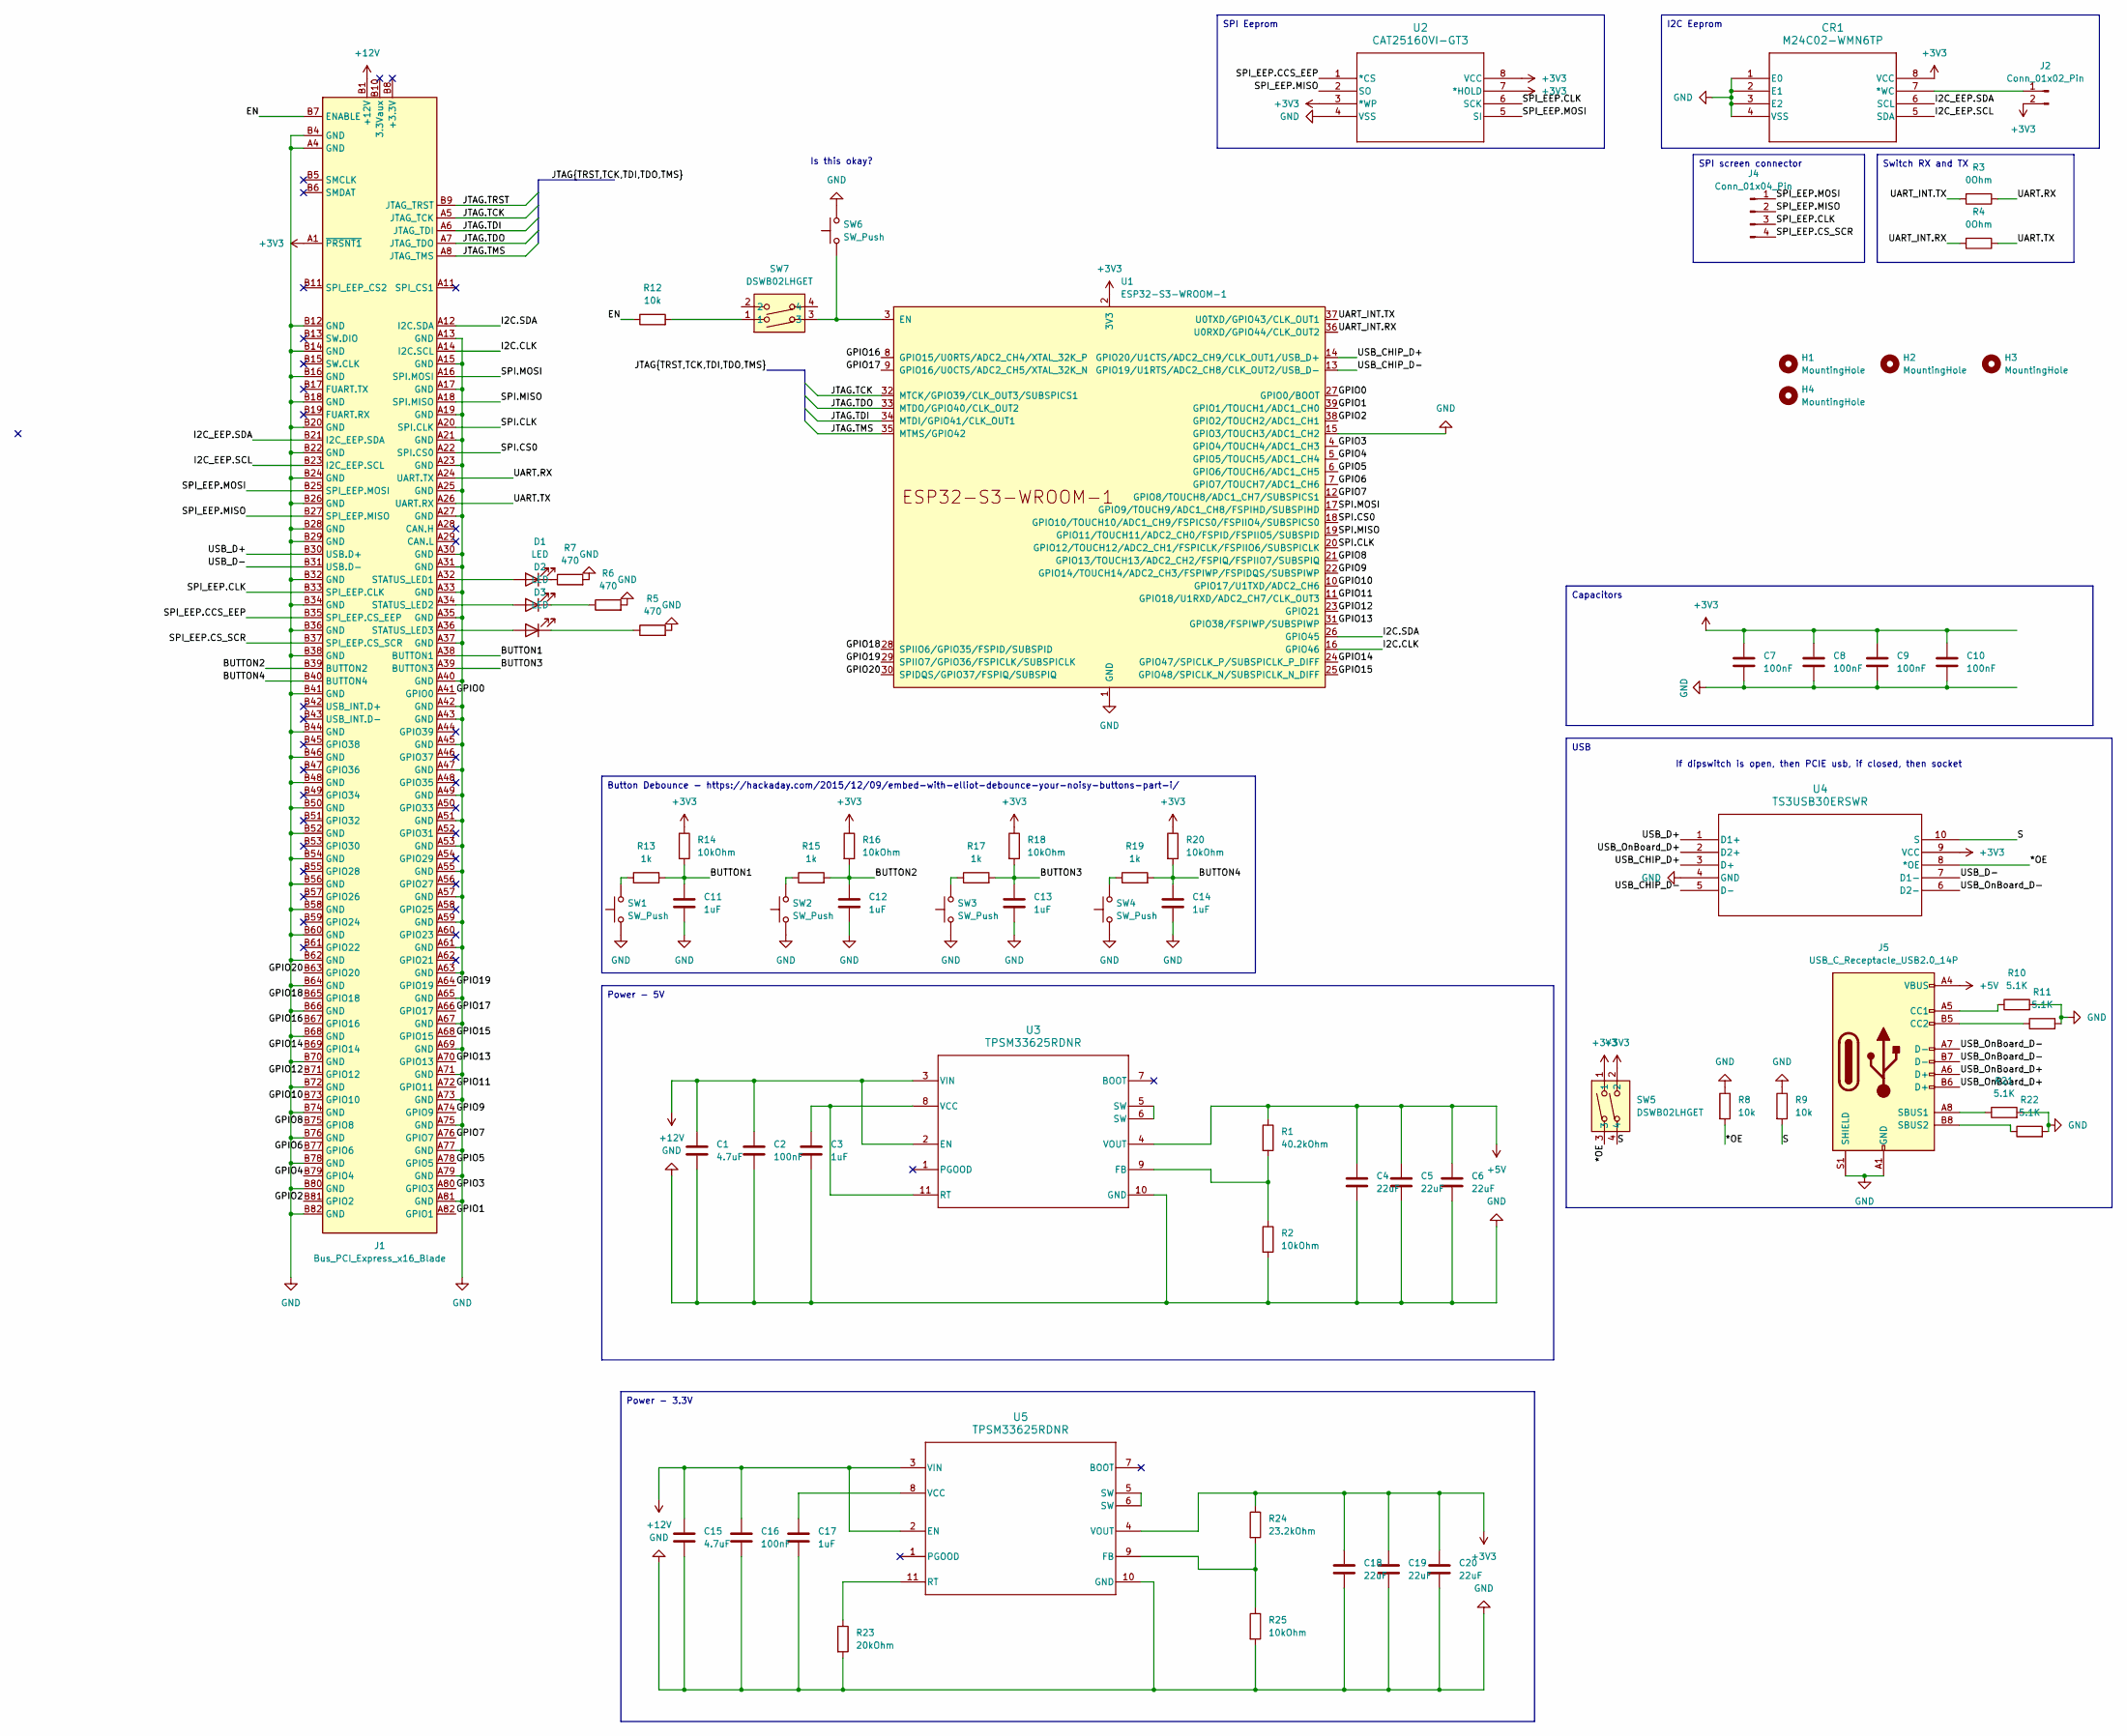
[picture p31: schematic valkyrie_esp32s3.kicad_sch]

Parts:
C1, C15: 4.7uF; C_0805_2012Metric
C2, C7, C8, C9, C10, C16: 100nF; C_0805_2012Metric
C3, C11, C12, C13, C14, C17: 1uF; C_0805_2012Metric
C4, C5, C6, C18, C19, C20: 22uF; C_0805_2012Metric
CR1: M24C02-WMN6TP; SO-8_STM
D1, D2, D3: LED; LED_0805_2012Metric
H1, H2, H3, H4: MountingHole; MountingHole_3.2mm_M3_Pad_TopBottom
J1: Bus_PCI_Express_x16_Blade; BUS_PCIexpress_x16
J2: Conn_01x02_Pin; PinHeader_1x02_P2.54mm_Vertical
J4: Conn_01x04_Pin; PinHeader_1x04_P2.54mm_Vertical
J5: USB_C_Receptacle_USB2.0_14P; USB_C_Receptacle_G-Switch_GT-USB-7010ASV
R1: 40.2kOhm; R_0805_2012Metric
R2, R14, R16, R18, R20, R25: 10kOhm; R_0805_2012Metric
R3, R4: 0Ohm; R_0805_2012Metric
R5, R6, R7: 470; R_0805_2012Metric
R8, R9, R12: 10k; R_0805_2012Metric
R10, R11, R21, R22: 5.1K; R_0805_2012Metric
R13, R15, R17, R19: 1k; R_0805_2012Metric
R23: 20kOhm; R_0805_2012Metric
R24: 23.2kOhm; R_0805_2012Metric
SW1, SW2, SW3, SW4, SW6: SW_Push; SW_Push_1P1T_XKB_TS-1187A
SW5, SW7: DSWB02LHGET; SW-TH_DSWB02LHGET; LCSC Part C99421
U1: ESP32-S3-WROOM-1
U2: CAT25160VI-GT3; SOIC8_ONS
U3, U5: TPSM33625RDNR; RDN0011A-MFG_custom
U4: TS3USB30ERSWR; RSW10_TEX

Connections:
+3V3: C7.1, C8.1, C9.1, C10.1, C18.1, C19.1, C20.1, CR1.8 (VCC), J1.A1 (~PRSNT1), J2.2, R14.1, R16.1, R18.1, R20.1, R24.1, SW5.1, SW5.2, U1.2 (3V3), U2.3 (*WP), U2.7 (*HOLD), U2.8 (VCC), U4.9 (VCC), U5.4 (VOUT)
+5V: C4.1, C5.1, C6.1, J5.A4 (VBUS), J5.A9 (VBUS), J5.B4 (VBUS), J5.B9 (VBUS), R1.1, U3.4 (VOUT)
+12V: C1.1, C2.1, C15.1, C16.1, J1.A2 (+12V), J1.A3 (+12V), J1.B1 (+12V), J1.B2 (+12V), J1.B3 (+12V), U3.2 (EN), U3.3 (VIN), U5.2 (EN), U5.3 (VIN)
/*OE: R8.2, SW5.3, U4.8 (*OE)
/BUTTON1: C11.1, J1.A38 (BUTTON1), R13.2, R14.2
/BUTTON2: C12.1, J1.B39 (BUTTON2), R15.2, R16.2
/BUTTON3: C13.1, J1.A39 (BUTTON3), R17.2, R18.2
/BUTTON4: C14.1, J1.B40 (BUTTON4), R19.2, R20.2
/EN: J1.B7 (ENABLE), R12.1
/GPIO0: J1.A41 (GPIO0), U1.27 (GPIO0/BOOT)
/GPIO1: J1.A82 (GPIO1), U1.39 (GPIO1/TOUCH1/ADC1_CH0)
/GPIO2: J1.B81 (GPIO2), U1.38 (GPIO2/TOUCH2/ADC1_CH1)
/GPIO3: J1.A80 (GPIO3), U1.4 (GPIO4/TOUCH4/ADC1_CH3)
/GPIO4: J1.B79 (GPIO4), U1.5 (GPIO5/TOUCH5/ADC1_CH4)
/GPIO5: J1.A78 (GPIO5), U1.6 (GPIO6/TOUCH6/ADC1_CH5)
/GPIO6: J1.B77 (GPIO6), U1.7 (GPIO7/TOUCH7/ADC1_CH6)
/GPIO7: J1.A76 (GPIO7), U1.12 (GPIO8/TOUCH8/ADC1_CH7/SUBSPICS1)
/GPIO8: J1.B75 (GPIO8), U1.21 (GPIO13/TOUCH13/ADC2_CH2/FSPIQ/FSPIIO7/S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)
/GPIO9: J1.A74 (GPIO9), U1.22 (GPIO14/TOUCH14/ADC2_CH3/FSPIWP/FSPIDQS/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)
/GPIO10: J1.B73 (GPIO10), U1.10 (GPIO17/U1TXD/ADC2_CH6)
/GPIO11: J1.A72 (GPIO11), U1.11 (GPIO18/U1RXD/ADC2_CH7/CLK_OUT3)
/GPIO12: J1.B71 (GPIO12), U1.23 (GPIO21)
/GPIO13: J1.A70 (GPIO13), U1.31 (GPIO38/FSPIWP/SUBSPIWP)
/GPIO14: J1.B69 (GPIO14), U1.24 (GPIO47/SPICLK_P/SUBSPICLK_P_DIFF)
/GPIO15: J1.A68 (GPIO15), U1.25 (GPIO48/SPICLK_N/SUBSPICLK_N_DIFF)
/GPIO16: J1.B67 (GPIO16), U1.8 (GPIO15/U0RTS/ADC2_CH4/XTAL_32K_P)
/GPIO17: J1.A66 (GPIO17), U1.9 (GPIO16/U0CTS/ADC2_CH5/XTAL_32K_N)
/GPIO18: J1.B65 (GPIO18), U1.28 (SPIIO6/GPIO35/FSPID/SUBSPID)
/GPIO19: J1.A64 (GPIO19), U1.29 (SPIIO7/GPIO36/FSPICLK/SUBSPICLK)
/GPIO20: J1.B63 (GPIO20), U1.30 (SPIDQS/GPIO37/FSPIQ/SUBSPIQ)
/I2C.CLK: J1.A14 (I2C.SCL), U1.16 (GPIO46)
/I2C.SDA: J1.A12 (I2C.SDA), U1.26 (GPIO45)
/I2C_EEP.SCL: CR1.5 (SDA), J1.B23 (I2C_EEP.SCL)
/I2C_EEP.SDA: CR1.6 (SCL), J1.B21 (I2C_EEP.SDA)
/JTAG.TCK: J1.A5 (JTAG_TCK), U1.32 (MTCK/GPIO39/CLK_OUT3/SUBSPICS1)
/JTAG.TDI: J1.A6 (JTAG_TDI), U1.34 (MTDI/GPIO41/CLK_OUT1)
/JTAG.TDO: J1.A7 (JTAG_TDO), U1.33 (MTDO/GPIO40/CLK_OUT2)
/JTAG.TMS: J1.A8 (JTAG_TMS), U1.35 (MTMS/GPIO42)
/JTAG.TRST: J1.B9 (JTAG_TRST)
/S: R9.2, SW5.4, U4.10 (S)
/SPI.CLK: J1.A20 (SPI.CLK), U1.20 (GPIO12/TOUCH12/ADC2_CH1/FSPICLK/FSPIIO6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)
/SPI.CS0: J1.A22 (SPI.CS0), U1.18 (GPIO10/TOUCH10/ADC1_CH9/FSPICS0/FSPIIO4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)
/SPI.MISO: J1.A18 (SPI.MISO), U1.19 (GPIO11/TOUCH11/ADC2_CH0/FSPID/FSPIIO5/S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)
/SPI.MOSI: J1.A16 (SPI.MOSI), U1.17 (GPIO9/TOUCH9/ADC1_CH8/FSPIHD/SUBSPIHD)
/SPI_EEP.CCS_EEP: J1.B35 (SPI_EEP.CS_EEP), U2.1 (*CS)
/SPI_EEP.CLK: J1.B33 (SPI_EEP.CLK), J4.3, U2.6 (SCK)
/SPI_EEP.CS_SCR: J1.B37 (SPI_EEP.CS_SCR), J4.4
/SPI_EEP.MISO: J1.B27 (SPI_EEP.MISO), J4.2, U2.2 (SO)
/SPI_EEP.MOSI: J1.B25 (SPI_EEP.MOSI), J4.1, U2.5 (SI)
/UART.RX: J1.A24 (UART.TX), R3.1
/UART.TX: J1.A26 (UART.RX), R4.1
/UART_INT.RX: R4.2, U1.36 (U0RXD/GPIO44/CLK_OUT2)
/UART_INT.TX: R3.2, U1.37 (U0TXD/GPIO43/CLK_OUT1)
/USB_CHIP_D+: U1.14 (GPIO20/U1CTS/ADC2_CH9/CLK_OUT1/USB_D+), U4.3 (D+)
/USB_CHIP_D-: U1.13 (GPIO19/U1RTS/ADC2_CH8/CLK_OUT2/USB_D-), U4.5 (D-)
/USB_D+: J1.B30 (USB.D+), U4.1 (D1+)
/USB_D-: J1.B31 (USB.D-), U4.7 (D1-)
/USB_OnBoard_D+: J5.A6 (D+), J5.B6 (D+), U4.2 (D2+)
/USB_OnBoard_D-: J5.A7 (D-), J5.B7 (D-), U4.6 (D2-)
GND: C1.2, C2.2, C3.2, C4.2, C5.2, C6.2, C7.2, C8.2, C9.2, C10.2, C11.2, C12.2, C13.2, C14.2, C15.2, C16.2, C17.2, C18.2, C19.2, C20.2, CR1.1 (E0), CR1.2 (E1), CR1.3 (E2), CR1.4 (VSS), J1.A4 (GND), J1.A13 (GND), J1.A15 (GND), J1.A17 (GND), J1.A19 (GND), J1.A21 (GND), J1.A23 (GND), J1.A25 (GND), J1.A27 (GND), J1.A30 (GND), J1.A31 (GND), J1.A33 (GND), J1.A35 (GND), J1.A37 (GND), J1.A40 (GND), J1.A42 (GND), J1.A43 (GND), J1.A45 (GND), J1.A47 (GND), J1.A49 (GND), J1.A51 (GND), J1.A53 (GND), J1.A55 (GND), J1.A57 (GND), J1.A59 (GND), J1.A61 (GND), J1.A63 (GND), J1.A65 (GND), J1.A67 (GND), J1.A69 (GND), J1.A71 (GND), J1.A73 (GND), J1.A75 (GND), J1.A77 (GND), J1.A79 (GND), J1.A81 (GND), J1.B4 (GND), J1.B12 (GND), J1.B14 (GND), J1.B16 (GND), J1.B18 (GND), J1.B20 (GND), J1.B22 (GND), J1.B24 (GND), J1.B26 (GND), J1.B28 (GND), J1.B29 (GND), J1.B32 (GND), J1.B34 (GND), J1.B36 (GND), J1.B38 (GND), J1.B41 (GND), J1.B44 (GND), J1.B46 (GND), J1.B48 (GND), J1.B50 (GND), J1.B52 (GND), J1.B54 (GND), J1.B56 (GND), J1.B58 (GND), J1.B60 (GND), J1.B62 (GND), J1.B64 (GND), J1.B66 (GND), J1.B68 (GND), J1.B70 (GND), J1.B72 (GND), J1.B74 (GND), J1.B76 (GND), J1.B78 (GND), J1.B80 (GND), J1.B82 (GND), J5.A1 (GND), J5.A12 (GND), J5.B1 (GND), J5.B12 (GND), J5.S1 (SHIELD), R2.2, R5.2, R6.2, R7.2, R8.1, R9.1, R10.2, R11.2, R21.2, R22.2, R23.2, R25.2, SW1.1, SW2.1, SW3.1, SW4.1, SW6.2, U1.1 (GND), U1.15 (GPIO3/TOUCH3/ADC1_CH2), U1.40 (GND), U1.41 (GND), U2.4 (VSS), U3.10 (GND), U4.4 (GND), U5.10 (GND)
unnamed: CR1.7 (*WC), J2.1
unnamed: D1.2 (A), J1.A32 (STATUS_LED1)
unnamed: D1.1 (K), R7.1
unnamed: D2.2 (A), J1.A34 (STATUS_LED2)
unnamed: D2.1 (K), R6.1
unnamed: D3.2 (A), J1.A36 (STATUS_LED3)
unnamed: D3.1 (K), R5.1
unnamed: J5.A5 (CC1), R10.1
unnamed: J5.B5 (CC2), R11.1
unnamed: J5.A8 (SBUS1), R21.1
unnamed: J5.B8 (SBUS2), R22.1
unnamed: R12.2, SW7.1
unnamed: R13.1, SW1.2
unnamed: R15.1, SW2.2
unnamed: R17.1, SW3.2
unnamed: R19.1, SW4.2
unnamed: SW6.1, SW7.3, U1.3 (EN)
unnamed: R1.2, R2.1, U3.9 (FB)
unnamed: C3.1, U3.8 (VCC), U3.11 (RT)
unnamed: U3.5 (SW), U3.6 (SW)
unnamed: R24.2, R25.1, U5.9 (FB)
unnamed: R23.1, U5.11 (RT)
unnamed: U5.5 (SW), U5.6 (SW)
unnamed: C17.1, U5.8 (VCC)

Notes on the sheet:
Switch RX and TX
Power - 5V
USB
I2C Eeprom
SPI screen connector
SPI Eeprom
Capacitors
Button Debounce - https://hackaday.com/2015/12/09/embed-with-elliot-debounce-your-noisy-buttons-part-i/
Power - 3.3V
Is this okay?
If dipswitch is open, then PCIE usb, if closed, then socket

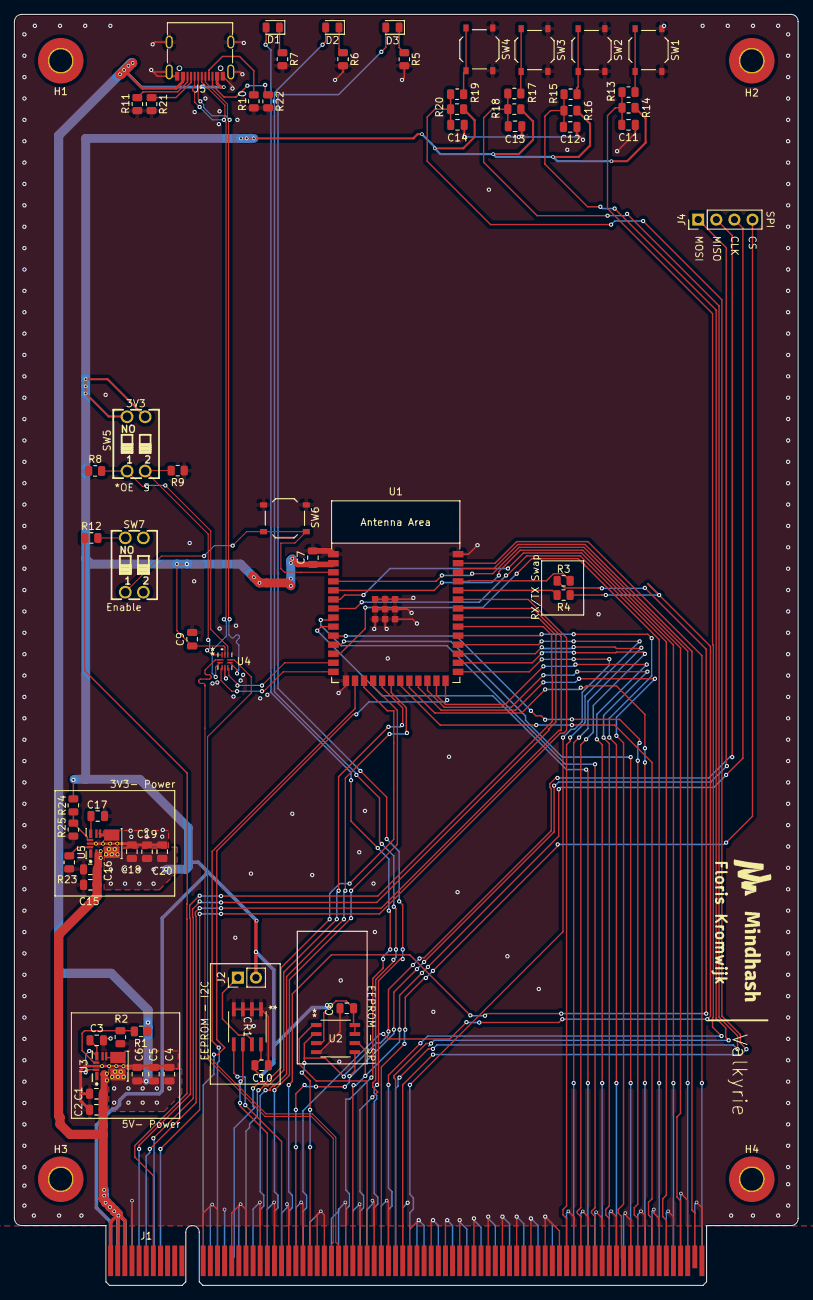
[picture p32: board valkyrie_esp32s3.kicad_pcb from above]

Board: 4 copper layers, 110.0 x 178.4 mm, 69 parts (0 on the bottom side), 83 nets.

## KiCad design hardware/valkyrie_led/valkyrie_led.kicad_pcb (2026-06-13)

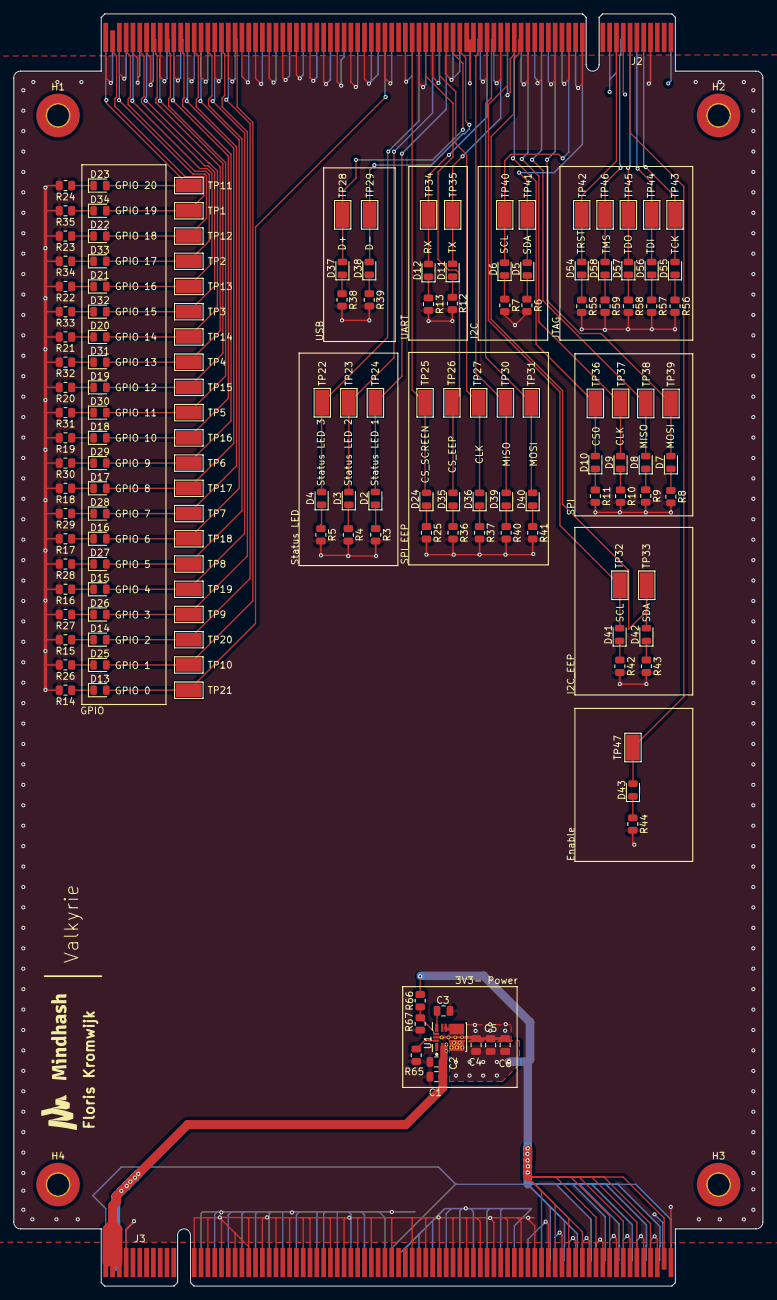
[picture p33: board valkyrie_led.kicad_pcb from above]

Board: 4 copper layers, 110.0 x 186.8 mm, 157 parts (0 on the bottom side), 102 nets.

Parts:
C1: 4.7uF; C_0805_2012Metric
C2: 100nF; C_0805_2012Metric
C3: 1uF; C_0805_2012Metric
C4, C5, C6: 22uF; C_0805_2012Metric
D2, D3, D4, D5, D6, D7, D8, D9, D10, D11, D12, D13, D14, D15, D16, D17, D18, D19, D20, D21, D22, D23, D24, D25, D26, D27, D28, D29, D30, D31, D32, D33, D34, D35, D36, D37, D38, D39, D40, D41, D42, D43, D54, D55, D56, D57, D58: LED; LED_0805_2012Metric
H1, H2, H3, H4: MountingHole; MountingHole_3.2mm_M3_Pad_TopBottom
J2, J3: Bus_PCI_Express_x16_Blade; BUS_PCIexpress_x16
R3, R4, R5, R6, R7, R8, R9, R10, R11, R12, R13, R14, R15, R16, R17, R18, R19, R20, R21, R22, R23, R24, R25, R26, R27, R28, R29, R30, R31, R32, R33, R34, R35, R36, R37, R38, R39, R40, R41, R42, R43, R44, R55, R56, R57, R58, R59: 470; R_0805_2012Metric
R65: 20kOhm; R_0805_2012Metric
R66: 23.2kOhm; R_0805_2012Metric
R67: 10kOhm; R_0805_2012Metric
TP1, TP2, TP3, TP4, TP5, TP6, TP7, TP8, TP9, TP10, TP11, TP12, TP13, TP14, TP15, TP16, TP17, TP18, TP19, TP20, TP21, TP22, TP23, TP24, TP25, TP26, TP27, TP28, TP29, TP30, TP31, TP32, TP33, TP34, TP35, TP36, TP37, TP38, TP39, TP40, TP41, TP42, TP43, TP44, TP45, TP46, TP47: TestPoint; TestPoint_Keystone_5019_Minature
U1: TPSM33625RDNR; RDN0011A-MFG_custom

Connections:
+3.3V: J2.A1 (~PRSNT1), J2.A9 (+3.3V), J2.A10 (+3.3V), J2.B8 (+3.3V)
+3V3: C4.1, C5.1, C6.1, J3.A1 (~PRSNT1), J3.A41 (GPIO0), J3.A64 (GPIO19), J3.A66 (GPIO17), J3.A68 (GPIO15), J3.A70 (GPIO13), J3.A72 (GPIO11), J3.A74 (GPIO9), J3.A76 (GPIO7), J3.A78 (GPIO5), J3.A80 (GPIO3), J3.A82 (GPIO1), J3.B63 (GPIO20), J3.B65 (GPIO18), J3.B67 (GPIO16), J3.B69 (GPIO14), J3.B71 (GPIO12), J3.B73 (GPIO10), J3.B75 (GPIO8), J3.B77 (GPIO6), J3.B79 (GPIO4), J3.B81 (GPIO2), R66.1, U1.4 (VOUT)
+12V: C1.1, C2.1, J3.A2 (+12V), J3.A3 (+12V), J3.B1 (+12V), J3.B2 (+12V), J3.B3 (+12V), U1.2 (EN), U1.3 (VIN)
GND: C1.2, C2.2, C3.2, C4.2, C5.2, C6.2, J2.A4 (GND), J2.A13 (GND), J2.A15 (GND), J2.A17 (GND), J2.A19 (GND), J2.A21 (GND), J2.A23 (GND), J2.A25 (GND), J2.A27 (GND), J2.A30 (GND), J2.A31 (GND), J2.A33 (GND), J2.A35 (GND), J2.A37 (GND), J2.A40 (GND), J2.A42 (GND), J2.A43 (GND), J2.A45 (GND), J2.A47 (GND), J2.A49 (GND), J2.A51 (GND), J2.A53 (GND), J2.A55 (GND), J2.A57 (GND), J2.A59 (GND), J2.A61 (GND), J2.A63 (GND), J2.A65 (GND), J2.A67 (GND), J2.A69 (GND), J2.A71 (GND), J2.A73 (GND), J2.A75 (GND), J2.A77 (GND), J2.A79 (GND), J2.A81 (GND), J2.B4 (GND), J2.B12 (GND), J2.B14 (GND), J2.B16 (GND), J2.B18 (GND), J2.B20 (GND), J2.B22 (GND), J2.B24 (GND), J2.B26 (GND), J2.B28 (GND), J2.B29 (GND), J2.B32 (GND), J2.B34 (GND), J2.B36 (GND), J2.B38 (GND), J2.B41 (GND), J2.B44 (GND), J2.B46 (GND), J2.B48 (GND), J2.B50 (GND), J2.B52 (GND), J2.B54 (GND), J2.B56 (GND), J2.B58 (GND), J2.B60 (GND), J2.B62 (GND), J2.B64 (GND), J2.B66 (GND), J2.B68 (GND), J2.B70 (GND), J2.B72 (GND), J2.B74 (GND), J2.B76 (GND), J2.B78 (GND), J2.B80 (GND), J2.B82 (GND), J3.A4 (GND), J3.A13 (GND), J3.A15 (GND), J3.A17 (GND), J3.A19 (GND), J3.A21 (GND), J3.A23 (GND), J3.A25 (GND), J3.A27 (GND), J3.A30 (GND), J3.A31 (GND), J3.A33 (GND), J3.A35 (GND), J3.A37 (GND), J3.A40 (GND), J3.A42 (GND), J3.A43 (GND), J3.A45 (GND), J3.A47 (GND), J3.A49 (GND), J3.A51 (GND), J3.A53 (GND), J3.A55 (GND), J3.A57 (GND), J3.A59 (GND), J3.A61 (GND), J3.A63 (GND), J3.A65 (GND), J3.A67 (GND), J3.A69 (GND), J3.A71 (GND), J3.A73 (GND), J3.A75 (GND), J3.A77 (GND), J3.A79 (GND), J3.A81 (GND), J3.B4 (GND), J3.B12 (GND), J3.B14 (GND), J3.B16 (GND), J3.B18 (GND), J3.B20 (GND), J3.B22 (GND), J3.B24 (GND), J3.B26 (GND), J3.B28 (GND), J3.B29 (GND), J3.B32 (GND), J3.B34 (GND), J3.B36 (GND), J3.B38 (GND), J3.B41 (GND), J3.B44 (GND), J3.B46 (GND), J3.B48 (GND), J3.B50 (GND), J3.B52 (GND), J3.B54 (GND), J3.B56 (GND), J3.B58 (GND), J3.B60 (GND), J3.B62 (GND), J3.B64 (GND), J3.B66 (GND), J3.B68 (GND), J3.B70 (GND), J3.B72 (GND), J3.B74 (GND), J3.B76 (GND), J3.B78 (GND), J3.B80 (GND), J3.B82 (GND), R3.2, R4.2, R5.2, R6.2, R7.2, R8.2, R9.2, R10.2, R11.2, R12.2, R13.2, R14.2, R15.2, R16.2, R17.2, R18.2, R19.2, R20.2, R21.2, R22.2, R23.2, R24.2, R25.2, R26.2, R27.2, R28.2, R29.2, R30.2, R31.2, R32.2, R33.2, R34.2, R35.2, R36.2, R37.2, R38.2, R39.2, R40.2, R41.2, R42.2, R43.2, R44.2, R55.2, R56.2, R57.2, R58.2, R59.2, R65.2, R67.2, U1.10 (GND)
unnamed: D2.2 (A), J2.A32 (STATUS_LED1), TP24.1
unnamed: D2.1 (K), R3.1
unnamed: D3.2 (A), J2.A34 (STATUS_LED2), TP23.1
unnamed: D3.1 (K), R4.1
unnamed: D4.2 (A), J2.A36 (STATUS_LED3), TP22.1
unnamed: D4.1 (K), R5.1
unnamed: D5.2 (A), J2.A12 (I2C.SDA), TP41.1
unnamed: D5.1 (K), R6.1
unnamed: D6.2 (A), J2.A14 (I2C.SCL), TP40.1
unnamed: D6.1 (K), R7.1
unnamed: D7.2 (A), J2.A16 (SPI.MOSI), TP39.1
unnamed: D7.1 (K), R8.1
unnamed: D8.2 (A), J2.A18 (SPI.MISO), TP38.1
unnamed: D8.1 (K), R9.1
unnamed: D9.2 (A), J2.A20 (SPI.CLK), TP37.1
unnamed: D9.1 (K), R10.1
unnamed: D10.2 (A), J2.A22 (SPI.CS0), TP36.1
unnamed: D10.1 (K), R11.1
unnamed: D11.2 (A), J2.A24 (UART.TX), TP35.1
unnamed: D11.1 (K), R12.1
unnamed: D12.2 (A), J2.A26 (UART.RX), TP34.1
unnamed: D12.1 (K), R13.1
unnamed: D13.2 (A), J2.A41 (GPIO0), TP21.1
unnamed: D13.1 (K), R14.1
unnamed: D14.2 (A), J2.A64 (GPIO19), TP20.1
unnamed: D14.1 (K), R15.1
unnamed: D15.2 (A), J2.A66 (GPIO17), TP19.1
unnamed: D15.1 (K), R16.1
unnamed: D16.2 (A), J2.A68 (GPIO15), TP18.1
unnamed: D16.1 (K), R17.1
unnamed: D17.2 (A), J2.A70 (GPIO13), TP17.1
unnamed: D17.1 (K), R18.1
unnamed: D18.2 (A), J2.A72 (GPIO11), TP16.1
unnamed: D18.1 (K), R19.1
unnamed: D19.2 (A), J2.A74 (GPIO9), TP15.1
unnamed: D19.1 (K), R20.1
unnamed: D20.2 (A), J2.A76 (GPIO7), TP14.1
unnamed: D20.1 (K), R21.1
unnamed: D21.2 (A), J2.A78 (GPIO5), TP13.1
unnamed: D21.1 (K), R22.1
unnamed: D22.2 (A), J2.A80 (GPIO3), TP12.1
unnamed: D22.1 (K), R23.1
unnamed: D23.2 (A), J2.A82 (GPIO1), TP11.1
unnamed: D23.1 (K), R24.1
unnamed: D24.2 (A), J2.B37 (SPI_EEP.CS_SCR), TP25.1
unnamed: D24.1 (K), R25.1
unnamed: D25.2 (A), J2.B63 (GPIO20), TP10.1
unnamed: D25.1 (K), R26.1
unnamed: D26.2 (A), J2.B65 (GPIO18), TP9.1
unnamed: D26.1 (K), R27.1
unnamed: D27.2 (A), J2.B67 (GPIO16), TP8.1
unnamed: D27.1 (K), R28.1
unnamed: D28.2 (A), J2.B69 (GPIO14), TP7.1
unnamed: D28.1 (K), R29.1
unnamed: D29.2 (A), J2.B71 (GPIO12), TP6.1
unnamed: D29.1 (K), R30.1
unnamed: D30.2 (A), J2.B73 (GPIO10), TP5.1
unnamed: D30.1 (K), R31.1
unnamed: D31.2 (A), J2.B75 (GPIO8), TP4.1
unnamed: D31.1 (K), R32.1
unnamed: D32.2 (A), J2.B77 (GPIO6), TP3.1
unnamed: D32.1 (K), R33.1
unnamed: D33.2 (A), J2.B79 (GPIO4), TP2.1
unnamed: D33.1 (K), R34.1
unnamed: D34.2 (A), J2.B81 (GPIO2), TP1.1
unnamed: D34.1 (K), R35.1
unnamed: D35.2 (A), J2.B35 (SPI_EEP.CS_EEP), TP26.1
unnamed: D35.1 (K), R36.1
unnamed: D36.2 (A), J2.B33 (SPI_EEP.CLK), TP27.1
unnamed: D36.1 (K), R37.1
unnamed: D37.2 (A), J2.B31 (USB.D-), TP28.1
unnamed: D37.1 (K), R38.1
unnamed: D38.2 (A), J2.B30 (USB.D+), TP29.1
unnamed: D38.1 (K), R39.1
unnamed: D39.2 (A), J2.B27 (SPI_EEP.MISO), TP30.1
unnamed: D39.1 (K), R40.1
unnamed: D40.2 (A), J2.B25 (SPI_EEP.MOSI), TP31.1
unnamed: D40.1 (K), R41.1
unnamed: D41.2 (A), J2.B23 (I2C_EEP.SCL), TP32.1
unnamed: D41.1 (K), R42.1
unnamed: D42.2 (A), J2.B21 (I2C_EEP.SDA), TP33.1
unnamed: D42.1 (K), R43.1
unnamed: D43.2 (A), J2.B7 (ENABLE), TP47.1
unnamed: D43.1 (K), R44.1
unnamed: D54.2 (A), J2.B9 (JTAG_TRST), TP42.1
unnamed: D54.1 (K), R55.1
unnamed: D55.2 (A), J2.A5 (JTAG_TCK), TP43.1
unnamed: D55.1 (K), R56.1
unnamed: D56.2 (A), J2.A6 (JTAG_TDI), TP44.1
unnamed: D56.1 (K), R57.1
unnamed: D57.2 (A), J2.A7 (JTAG_TDO), TP45.1
unnamed: D57.1 (K), R58.1
unnamed: D58.2 (A), J2.A8 (JTAG_TMS), TP46.1
unnamed: D58.1 (K), R59.1
unnamed: R66.2, R67.1, U1.9 (FB)
unnamed: R65.1, U1.11 (RT)
unnamed: U1.5 (SW), U1.6 (SW)
unnamed: C3.1, U1.8 (VCC)

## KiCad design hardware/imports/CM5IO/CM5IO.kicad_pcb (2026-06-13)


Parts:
C9, C18: 100n; C_0402_1005Metric; Part Description 0.1uF 10% 16V Ceramic Capacitor X7R 040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
H1, H2, H3, H4, H5, H6, H7, H8: MountingHole; MountingHole_2.7mm_M2.5_DIN965; Part Description M2.5 mounting hole; not fitted
J11: USB_C_Receptacle_USB2.0; USB_C_Receptacle_GCT_USB4105-xx-A_16P_TopMnt_Horizontal; Part Description USBC USB2 data and power connector
R9: 2.2K 1%; R_0402_1005Metric; Part Description Resistor 2.2K M1005 1% 63mW

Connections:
/+5v: C9.1, C18.1, J11.A4 (VBUS), J11.A9 (VBUS), J11.B4 (VBUS), J11.B9 (VBUS), R9.1; also elsewhere on the board
/CC1: J11.A5 (CC1); also elsewhere on the board
/CC2: J11.B5 (CC2); also elsewhere on the board
/USB2_N: J11.A7 (D-), J11.B7 (D-); also elsewhere on the board
/USB2_P: J11.A6 (D+), J11.B6 (D+); also elsewhere on the board
GND: C9.2, C18.2, J11.A1 (GND), J11.A12 (GND), J11.B1 (GND), J11.B12 (GND), J11.S1 (SHIELD), R9.2; also elsewhere on the board

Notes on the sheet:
Connectors ------- Ethernet SDCARD 40way RPI Jumpers Fan Battery
Connectors ------ M2 MKey
Discharge Resistor Needed by some Type C PSUs
TypeC Power connector
Connectors ------- HDMI 0 HDMI 1 CSI/DSI 0 CSI/DSI 1

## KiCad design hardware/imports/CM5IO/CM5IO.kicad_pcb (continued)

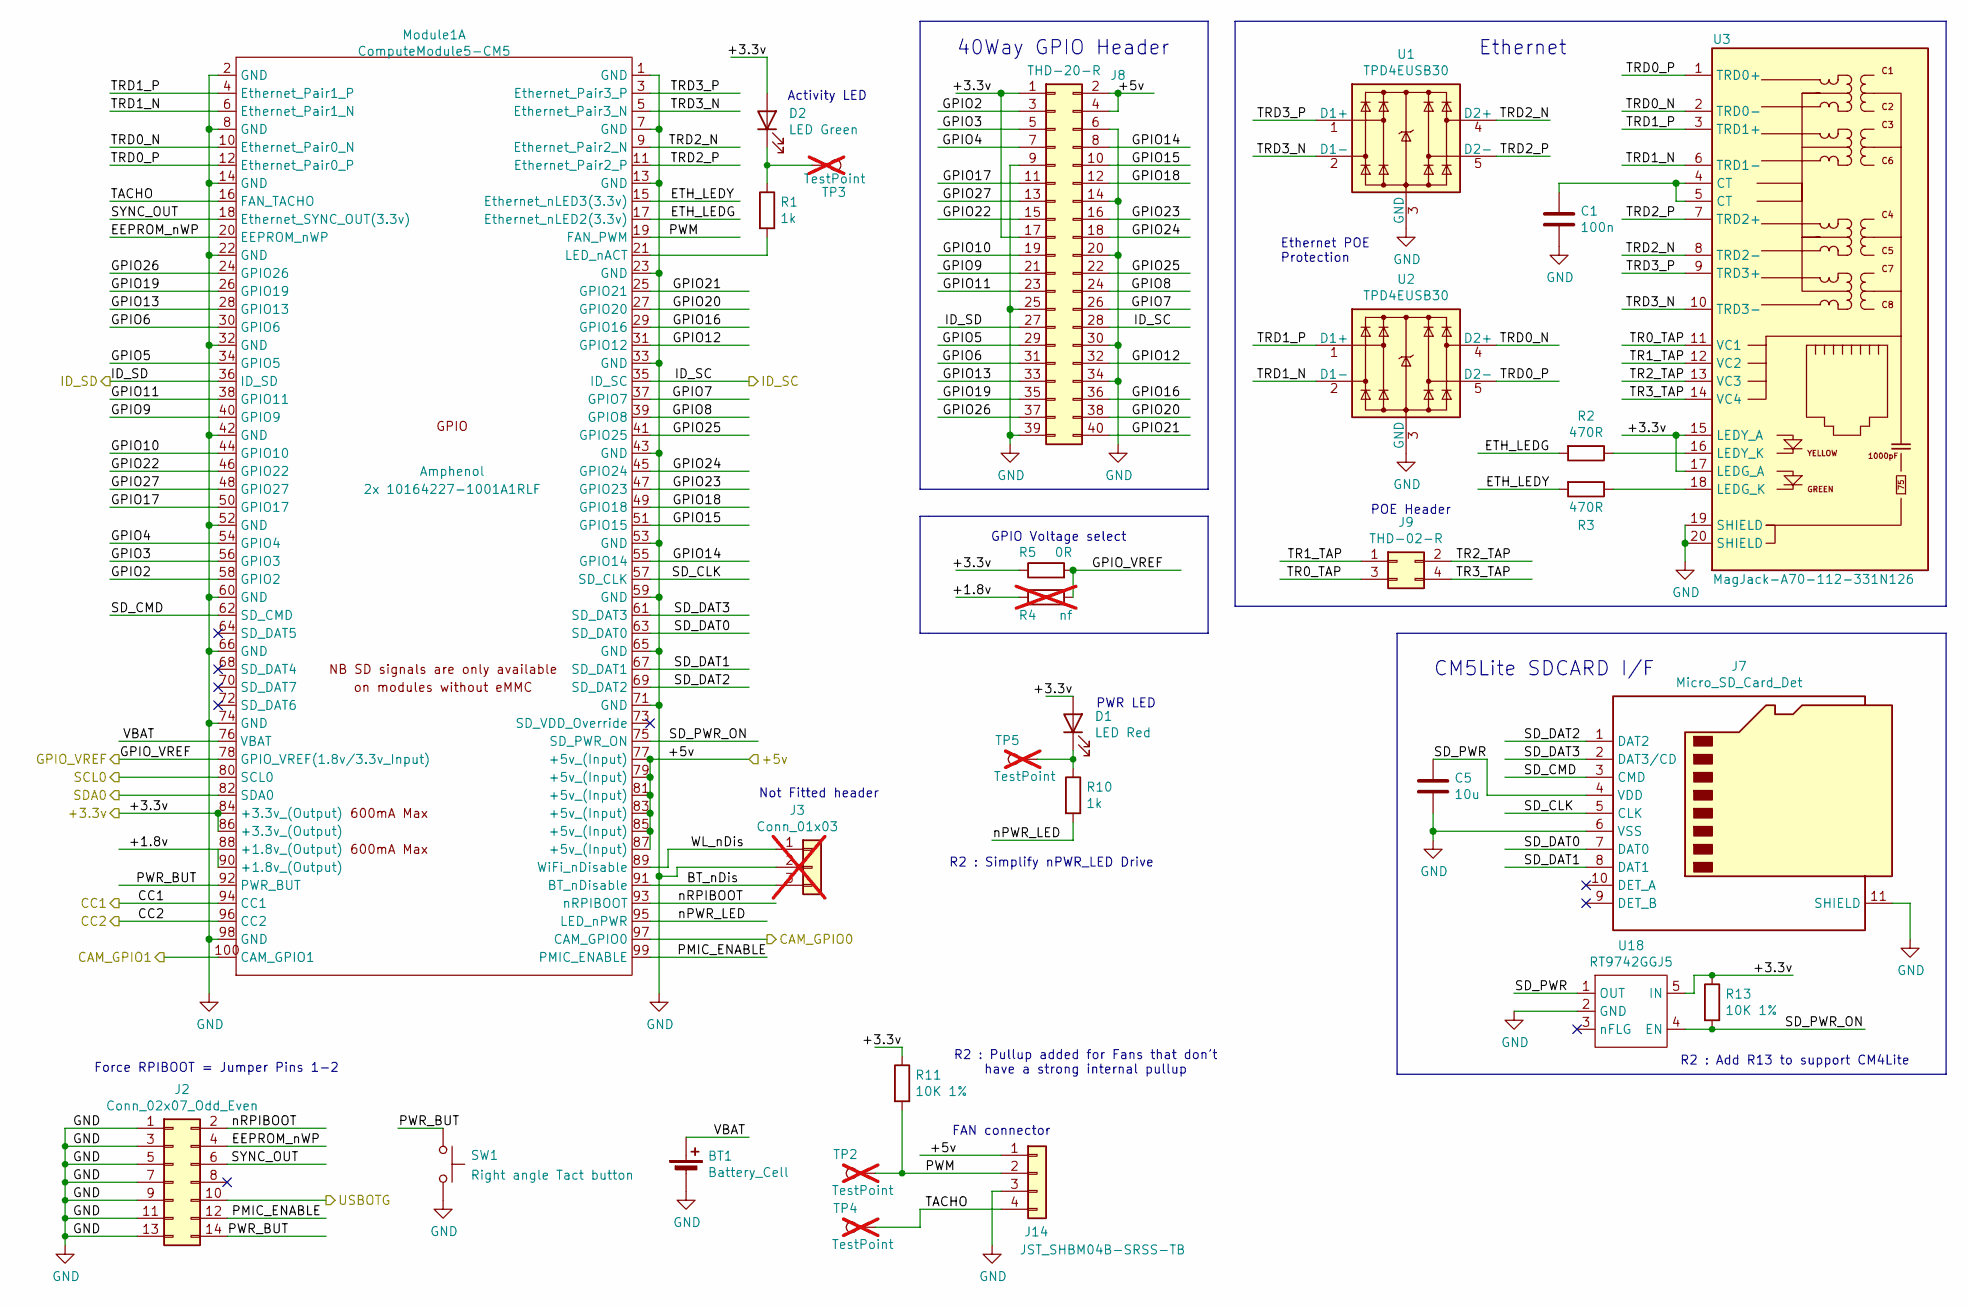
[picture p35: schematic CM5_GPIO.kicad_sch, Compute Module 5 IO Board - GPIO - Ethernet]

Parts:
BT1: Battery_Cell; BatteryHolder_Keystone_3034_1x20mm; Part Description Battery Retainer Coin, 20.0mm 1 Cell SM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
C1: 100n; C_0402_1005Metric; Part Description 0.1uF 10% 16V Ceramic Capacitor X7R 040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
C5: 10u; C_0805_2012Metric; Part Description 10uF 10% 10V Ceramic Capacitor X7R 0805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
D1: LED Red; LED_0603_1608Metric; Part Description Red 620nm LED Indication - Discrete 2.2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
D2: LED Green; LED_0603_1608Metric; Part Description Green 572nm LED Indication - Discrete 2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
J2: Conn_02x07_Odd_Even; PinHeader_2x07_P2.54mm_Vertical; Part Description PinHeader_2x07_P2.54mm_Vertical
J3: Conn_01x03; PinHeader_1x03_P2.54mm_Vertical; Part Description 3pin 0.1" connector; not fitted
J7: Micro_SD_Card_Det; SDCARD_MOLEX_503398-1892; Part Description 9 (8 + 1) Position Card Connector micro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
J8: THD-20-R; PinHeader_2x20_P2.54mm_Vertical; Part Description PinHeader_2x20_P2.54mm_Vertical
J9: THD-02-R; PinHeader_2x02_P2.54mm_Vertical; Part Description PinHeader_2x02_P2.54mm_Vertical
J14: JST_SHBM04B-SRSS-TB; JST_SH_BM04B-SRSS-TB_1x04-1MP_P1.00mm_Vertical; Part Description 4 pin vertical 1mm pitch connector
Module1: ComputeModule5-CM5; Raspberry-Pi-5-Compute-Module; Part Description 100 Position Connector Receptacle, Cent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
R1, R10: 1k; R_0402_1005Metric; Part Description Resistor 1K M1005 1% 63mW
R2, R3: 470R; R_0402_1005Metric; Part Description Resistor 470R M1005 1% 63mW
R4: nf; R_0805_2012Metric_Pad1.20x1.40mm_HandSolder; not fitted
R5: 0R; R_0805_2012Metric_Pad1.20x1.40mm_HandSolder; Part Description Resistor 0R M2012 5%
R11, R13: 10K 1%; R_0402_1005Metric; Part Description Resistor 10K M1005 1% 63mW
SW1: Right angle Tact button; SW_Tactile_SPST_Angled_PTS645Vx58-2LFS; Part Description Right angle through hole Tact switch
TP2, TP3, TP4, TP5: TestPoint; TestPoint_Pad_2.0x2.0mm; Part Description Test point; not fitted
U1, U2: TPD4EUSB30; USON-10_2.5x1.0mm_P0.5mm; Part Description Quad TVS diode for high speed signals (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
U3: MagJack-A70-112-331N126; TRJG0926HENL; Part Description Gigabit Ethernet Magjack
U18: RT9742GGJ5; SOT-23-5; Part Description Power Switch/Driver 1:1 N-Channel 1A TS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

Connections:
/+3.3v: D1.2 (A), D2.2 (A), J8.1, J8.17, Module1.84 (+3.3v_(Output)), Module1.86 (+3.3v_(Output)), R5.1, R11.1, R13.1, U3.15 (LEDY_A), U3.17 (LEDG_A), U18.5 (IN); also elsewhere on the board
/+5v: J8.2, J8.4, J14.1, Module1.77 (+5v_(Input)), Module1.79 (+5v_(Input)), Module1.81 (+5v_(Input)), Module1.83 (+5v_(Input)), Module1.85 (+5v_(Input)), Module1.87 (+5v_(Input)); also elsewhere on the board
/CC1: Module1.94 (CC1); also elsewhere on the board
/CC2: Module1.96 (CC2); also elsewhere on the board
/CM5_GPIO ( Ethernet, GPIO, SDCARD)/+1.8v: Module1.88 (+1.8v_(Output)), Module1.90 (+1.8v_(Output)), R4.1
/CM5_GPIO ( Ethernet, GPIO, SDCARD)/BT_nDis: J3.3, Module1.91 (BT_nDisable)
/CM5_GPIO ( Ethernet, GPIO, SDCARD)/CAM_GPIO0: Module1.97 (CAM_GPIO0); also elsewhere on the board
/CM5_GPIO ( Ethernet, GPIO, SDCARD)/CAM_GPIO1: Module1.100 (CAM_GPIO1); also elsewhere on the board
/CM5_GPIO ( Ethernet, GPIO, SDCARD)/EEPROM_nWP: J2.4, Module1.20 (EEPROM_nWP)
/CM5_GPIO ( Ethernet, GPIO, SDCARD)/ETH_LEDG: Module1.17 (Ethernet_nLED2(3.3v)), R2.2
/CM5_GPIO ( Ethernet, GPIO, SDCARD)/ETH_LEDY: Module1.15 (Ethernet_nLED3(3.3v)), R3.2
/CM5_GPIO ( Ethernet, GPIO, SDCARD)/GPIO2: J8.3, Module1.58 (GPIO2)
/CM5_GPIO ( Ethernet, GPIO, SDCARD)/GPIO3: J8.5, Module1.56 (GPIO3)
/CM5_GPIO ( Ethernet, GPIO, SDCARD)/GPIO4: J8.7, Module1.54 (GPIO4)
/CM5_GPIO ( Ethernet, GPIO, SDCARD)/GPIO5: J8.29, Module1.34 (GPIO5)
/CM5_GPIO ( Ethernet, GPIO, SDCARD)/GPIO6: J8.31, Module1.30 (GPIO6)
/CM5_GPIO ( Ethernet, GPIO, SDCARD)/GPIO7: J8.26, Module1.37 (GPIO7)
/CM5_GPIO ( Ethernet, GPIO, SDCARD)/GPIO8: J8.24, Module1.39 (GPIO8)
/CM5_GPIO ( Ethernet, GPIO, SDCARD)/GPIO9: J8.21, Module1.40 (GPIO9)
/CM5_GPIO ( Ethernet, GPIO, SDCARD)/GPIO10: J8.19, Module1.44 (GPIO10)
/CM5_GPIO ( Ethernet, GPIO, SDCARD)/GPIO11: J8.23, Module1.38 (GPIO11)
/CM5_GPIO ( Ethernet, GPIO, SDCARD)/GPIO12: J8.32, Module1.31 (GPIO12)
/CM5_GPIO ( Ethernet, GPIO, SDCARD)/GPIO13: J8.33, Module1.28 (GPIO13)
/CM5_GPIO ( Ethernet, GPIO, SDCARD)/GPIO14: J8.8, Module1.55 (GPIO14)
/CM5_GPIO ( Ethernet, GPIO, SDCARD)/GPIO15: J8.10, Module1.51 (GPIO15)
/CM5_GPIO ( Ethernet, GPIO, SDCARD)/GPIO16: J8.36, Module1.29 (GPIO16)
/CM5_GPIO ( Ethernet, GPIO, SDCARD)/GPIO17: J8.11, Module1.50 (GPIO17)
/CM5_GPIO ( Ethernet, GPIO, SDCARD)/GPIO18: J8.12, Module1.49 (GPIO18)
/CM5_GPIO ( Ethernet, GPIO, SDCARD)/GPIO19: J8.35, Module1.26 (GPIO19)
/CM5_GPIO ( Ethernet, GPIO, SDCARD)/GPIO20: J8.38, Module1.27 (GPIO20)
/CM5_GPIO ( Ethernet, GPIO, SDCARD)/GPIO21: J8.40, Module1.25 (GPIO21)
/CM5_GPIO ( Ethernet, GPIO, SDCARD)/GPIO22: J8.15, Module1.46 (GPIO22)
/CM5_GPIO ( Ethernet, GPIO, SDCARD)/GPIO23: J8.16, Module1.47 (GPIO23)
/CM5_GPIO ( Ethernet, GPIO, SDCARD)/GPIO24: J8.18, Module1.45 (GPIO24)
/CM5_GPIO ( Ethernet, GPIO, SDCARD)/GPIO25: J8.22, Module1.41 (GPIO25)
/CM5_GPIO ( Ethernet, GPIO, SDCARD)/GPIO26: J8.37, Module1.24 (GPIO26)
/CM5_GPIO ( Ethernet, GPIO, SDCARD)/GPIO27: J8.13, Module1.48 (GPIO27)
/CM5_GPIO ( Ethernet, GPIO, SDCARD)/GPIO_VREF: Module1.78 (GPIO_VREF(1.8v/3.3v_Input)), R4.2, R5.2; also elsewhere on the board
/CM5_GPIO ( Ethernet, GPIO, SDCARD)/ID_SC: J8.28, Module1.35 (ID_SC); also elsewhere on the board
/CM5_GPIO ( Ethernet, GPIO, SDCARD)/ID_SD: J8.27, Module1.36 (ID_SD); also elsewhere on the board
/CM5_GPIO ( Ethernet, GPIO, SDCARD)/PMIC_ENABLE: J2.12, Module1.99 (PMIC_ENABLE)
/CM5_GPIO ( Ethernet, GPIO, SDCARD)/PWM: J14.2, Module1.19 (FAN_PWM), R11.2, TP2.1
/CM5_GPIO ( Ethernet, GPIO, SDCARD)/PWR_BUT: J2.14, Module1.92 (PWR_BUT), SW1.1
/CM5_GPIO ( Ethernet, GPIO, SDCARD)/SD_CLK: J7.5 (CLK), Module1.57 (SD_CLK)
/CM5_GPIO ( Ethernet, GPIO, SDCARD)/SD_CMD: J7.3 (CMD), Module1.62 (SD_CMD)
/CM5_GPIO ( Ethernet, GPIO, SDCARD)/SD_DAT0: J7.7 (DAT0), Module1.63 (SD_DAT0)
/CM5_GPIO ( Ethernet, GPIO, SDCARD)/SD_DAT1: J7.8 (DAT1), Module1.67 (SD_DAT1)
/CM5_GPIO ( Ethernet, GPIO, SDCARD)/SD_DAT2: J7.1 (DAT2), Module1.69 (SD_DAT2)
/CM5_GPIO ( Ethernet, GPIO, SDCARD)/SD_DAT3: J7.2 (DAT3/CD), Module1.61 (SD_DAT3)
/CM5_GPIO ( Ethernet, GPIO, SDCARD)/SD_PWR: C5.1, J7.4 (VDD), U18.1 (OUT)
/CM5_GPIO ( Ethernet, GPIO, SDCARD)/SD_PWR_ON: Module1.75 (SD_PWR_ON), R13.2, U18.4 (EN)
/CM5_GPIO ( Ethernet, GPIO, SDCARD)/SYNC_OUT: J2.6, Module1.18 (Ethernet_SYNC_OUT(3.3v))
/CM5_GPIO ( Ethernet, GPIO, SDCARD)/TACHO: J14.4, Module1.16 (FAN_TACHO), TP4.1
/CM5_GPIO ( Ethernet, GPIO, SDCARD)/TR0_TAP: J9.3, U3.11 (VC1)
/CM5_GPIO ( Ethernet, GPIO, SDCARD)/TR1_TAP: J9.1, U3.12 (VC2)
/CM5_GPIO ( Ethernet, GPIO, SDCARD)/TR2_TAP: J9.2, U3.13 (VC3)
/CM5_GPIO ( Ethernet, GPIO, SDCARD)/TR3_TAP: J9.4, U3.14 (VC4)
/CM5_GPIO ( Ethernet, GPIO, SDCARD)/TRD0_N: Module1.10 (Ethernet_Pair0_N), U2.4 (D2+), U2.7, U3.2 (TRD0-)
/CM5_GPIO ( Ethernet, GPIO, SDCARD)/TRD0_P: Module1.12 (Ethernet_Pair0_P), U2.5 (D2-), U2.6, U3.1 (TRD0+)
/CM5_GPIO ( Ethernet, GPIO, SDCARD)/TRD1_N: Module1.6 (Ethernet_Pair1_N), U2.2 (D1-), U2.9, U3.6 (TRD1-)
/CM5_GPIO ( Ethernet, GPIO, SDCARD)/TRD1_P: Module1.4 (Ethernet_Pair1_P), U2.1 (D1+), U2.10, U3.3 (TRD1+)
/CM5_GPIO ( Ethernet, GPIO, SDCARD)/TRD2_N: Module1.9 (Ethernet_Pair2_N), U1.4 (D2+), U1.7, U3.8 (TRD2-)
/CM5_GPIO ( Ethernet, GPIO, SDCARD)/TRD2_P: Module1.11 (Ethernet_Pair2_P), U1.5 (D2-), U1.6, U3.7 (TRD2+)
/CM5_GPIO ( Ethernet, GPIO, SDCARD)/TRD3_N: Module1.5 (Ethernet_Pair3_N), U1.2 (D1-), U1.9, U3.10 (TRD3-)
/CM5_GPIO ( Ethernet, GPIO, SDCARD)/TRD3_P: Module1.3 (Ethernet_Pair3_P), U1.1 (D1+), U1.10, U3.9 (TRD3+)
/CM5_GPIO ( Ethernet, GPIO, SDCARD)/USBOTG: J2.10; also elsewhere on the board
/CM5_GPIO ( Ethernet, GPIO, SDCARD)/VBAT: BT1.1 (+), Module1.76 (VBAT)
/CM5_GPIO ( Ethernet, GPIO, SDCARD)/WL_nDis: J3.1, Module1.89 (WiFi_nDisable)
/CM5_GPIO ( Ethernet, GPIO, SDCARD)/nPWR_LED: Module1.95 (LED_nPWR), R10.2
/CM5_GPIO ( Ethernet, GPIO, SDCARD)/nRPIBOOT: J2.2, Module1.93 (nRPIBOOT)
/CM5_HighSpeed/SCL0: Module1.80 (SCL0); also elsewhere on the board
/CM5_HighSpeed/SDA0: Module1.82 (SDA0); also elsewhere on the board
GND: BT1.2 (-), C1.2, C5.2, J2.1, J2.3, J2.5, J2.7, J2.9, J2.11, J2.13, J3.2, J7.6 (VSS), J7.11 (SHIELD), J8.6, J8.9, J8.14, J8.20, J8.25, J8.30, J8.34, J8.39, J14.3, Module1.1 (GND), Module1.2 (GND), Module1.7 (GND), Module1.8 (GND), Module1.13 (GND), Module1.14 (GND), Module1.22 (GND), Module1.23 (GND), Module1.32 (GND), Module1.33 (GND), Module1.42 (GND), Module1.43 (GND), Module1.52 (GND), Module1.53 (GND), Module1.59 (GND), Module1.60 (GND), Module1.65 (GND), Module1.66 (GND), Module1.71 (GND), Module1.74 (GND), Module1.98 (GND), SW1.2, U1.3 (GND), U1.8 (GND), U2.3 (GND), U2.8 (GND), U3.19 (SHIELD), U3.20 (SHIELD), U18.2 (GND); also elsewhere on the board
unnamed: C1.1, U3.4 (CT), U3.5 (CT)
unnamed: D1.1 (K), R10.1, TP5.1
unnamed: D2.1 (K), R1.1, TP3.1
unnamed: Module1.21 (LED_nACT), R1.2
unnamed: R3.1, U3.18 (LEDG_K)
unnamed: R2.1, U3.16 (LEDY_K)

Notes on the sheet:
40Way GPIO Header
Activity LED
R2 : Simplify nPWR_LED Drive
FAN connector
R2 : Add R13 to support CM4Lite
Ethernet POE Protection
GPIO Voltage select
R2 : Pullup added for Fans that don't have a strong internal pullup
Not Fitted header
POE Header
Force RPIBOOT = Jumper Pins 1-2
PWR LED
Ethernet
CM5Lite SDCARD I/F


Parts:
C2, C7, C8: 10u; C_0805_2012Metric; Part Description 10uF 10% 10V Ceramic Capacitor X7R 0805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
C3: 100uF; CP_EIA-7343-31_Kemet-D; Part Description Capacitor, SP-Cap, 100u, 6.3V, 15mR ESR
C12, C13: 100n; C_0402_1005Metric; Part Description 0.1uF 10% 16V Ceramic Capacitor X7R 040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
J5, J16: Conn_01x22_Female; Hirose_FH12-22S-0.5SH_1x22-1MP_P0.50mm_Horizontal; Part Description 22 Position FFC, FPC Connector Contacts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
J6: THD-02-R; PinHeader_2x02_P2.54mm_Vertical; Part Description PinHeader_2x02_P2.54mm_Vertical
J10, J22: 690-019-298-412; EDAC 690-019-298-412; Part Description HDMI Connector, Right Angle, 19 Contact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
J12: USB3_A; MTCONN_UBAF30-D2011; Part Description Dual USB 3 connector
Module1: ComputeModule5-CM5; Raspberry-Pi-5-Compute-Module; Part Description 100 Position Connector Receptacle, Cent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
R6, R7, R8: 2.2K 1%; R_0402_1005Metric; Part Description Resistor 2.2K M1005 1% 63mW
R12: 15K 1%; R_0402_1005Metric; Part Description Resistor 15K M1005 1% 63mW
U6: AP22653W6; SOT-23-6; Part Description Power Switch/Driver 1:1 P-Channel 2.1A 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
U12: RT9742SNGV; TSOT-23_HandSoldering; Part Description Power Switch/Driver 1:1 N-Channel 500mA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

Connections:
/+3.3v: J5.22, J16.22, R8.1; also elsewhere on the board
/+5v: C2.1, C12.1, U6.1 (IN), U12.1 (IN); also elsewhere on the board
/CM5_GPIO ( Ethernet, GPIO, SDCARD)/CAM_GPIO0: J5.17; also elsewhere on the board
/CM5_GPIO ( Ethernet, GPIO, SDCARD)/CAM_GPIO1: J5.18; also elsewhere on the board
/CM5_GPIO ( Ethernet, GPIO, SDCARD)/GPIO_VREF: R6.1, R7.1; also elsewhere on the board
/CM5_GPIO ( Ethernet, GPIO, SDCARD)/ID_SC: J6.1; also elsewhere on the board
/CM5_GPIO ( Ethernet, GPIO, SDCARD)/ID_SD: J6.3; also elsewhere on the board
/CM5_GPIO ( Ethernet, GPIO, SDCARD)/USBOTG: Module1.101 (USB_OTG_ID); also elsewhere on the board
/CM5_HighSpeed/DPHY0_C_N: J5.8, Module1.127 (MIPI0_C_N)
/CM5_HighSpeed/DPHY0_C_P: J5.9, Module1.129 (MIPI0_C_P)
/CM5_HighSpeed/DPHY0_D0_N: J5.2, Module1.115 (MIPI0_D0_N)
/CM5_HighSpeed/DPHY0_D0_P: J5.3, Module1.117 (MIPI0_D0_P)
/CM5_HighSpeed/DPHY0_D1_N: J5.5, Module1.121 (MIPI0_D1_N)
/CM5_HighSpeed/DPHY0_D1_P: J5.6, Module1.123 (MIPI0_D1_P)
/CM5_HighSpeed/DPHY0_D2_N: J5.11, Module1.133 (MIPI0_D2_N)
/CM5_HighSpeed/DPHY0_D2_P: J5.12, Module1.135 (MIPI0_D2_P)
/CM5_HighSpeed/DPHY0_D3_N: J5.14, Module1.139 (MIPI0_D3_N)
/CM5_HighSpeed/DPHY0_D3_P: J5.15, Module1.141 (MIPI0_D3_P)
/CM5_HighSpeed/DPHY1_C_N: J16.8, Module1.187 (MIPI1_C_N)
/CM5_HighSpeed/DPHY1_C_P: J16.9, Module1.189 (MIPI1_C_P)
/CM5_HighSpeed/DPHY1_D0_N: J16.2, Module1.175 (MIPI1_D0_N)
/CM5_HighSpeed/DPHY1_D0_P: J16.3, Module1.177 (MIPI1_D0_P)
/CM5_HighSpeed/DPHY1_D1_N: J16.5, Module1.181 (MIPI1_D1_N)
/CM5_HighSpeed/DPHY1_D1_P: J16.6, Module1.183 (MIPI1_D1_P)
/CM5_HighSpeed/DPHY1_D2_N: J16.11, Module1.193 (MIPI1_D2_N)
/CM5_HighSpeed/DPHY1_D2_P: J16.12, Module1.195 (MIPI1_D2_P)
/CM5_HighSpeed/DPHY1_D3_N: J16.14, Module1.194 (MIPI1_D3_N)
/CM5_HighSpeed/DPHY1_D3_P: J16.15, Module1.196 (MIPI1_D3_P)
/CM5_HighSpeed/HDMI0_CEC: J22.13 (CEC), Module1.151 (HDMI0_CEC)
/CM5_HighSpeed/HDMI0_CK_N: J22.12 (CK-), Module1.190 (HDMI0_CLK_N)
/CM5_HighSpeed/HDMI0_CK_P: J22.10 (CK+), Module1.188 (HDMI0_CLK_P)
/CM5_HighSpeed/HDMI0_D0_N: J22.9 (D0-), Module1.184 (HDMI0_TX0_N)
/CM5_HighSpeed/HDMI0_D0_P: J22.7 (D0+), Module1.182 (HDMI0_TX0_P)
/CM5_HighSpeed/HDMI0_D1_N: J22.6 (D1-), Module1.178 (HDMI0_TX1_N)
/CM5_HighSpeed/HDMI0_D1_P: J22.4 (D1+), Module1.176 (HDMI0_TX1_P)
/CM5_HighSpeed/HDMI0_D2_N: J22.3 (D2-), Module1.172 (HDMI0_TX2_N)
/CM5_HighSpeed/HDMI0_D2_P: J22.1 (D2+), Module1.170 (HDMI0_TX2_P)
/CM5_HighSpeed/HDMI0_HOTPLUG: J22.19 (HPD/HEAC-), Module1.153 (HDMI0_HOTPLUG)
/CM5_HighSpeed/HDMI0_SCL: J22.15 (SCL), Module1.200 (HDMI0_SCL)
/CM5_HighSpeed/HDMI0_SDA: J22.16 (SDA), Module1.199 (HDMI0_SDA)
/CM5_HighSpeed/HDMI1_CEC: J10.13 (CEC), Module1.149 (HDMI1_CEC)
/CM5_HighSpeed/HDMI1_CK_N: J10.12 (CK-), Module1.166 (HDMI1_CLK_N)
/CM5_HighSpeed/HDMI1_CK_P: J10.10 (CK+), Module1.164 (HDMI1_CLK_P)
/CM5_HighSpeed/HDMI1_D0_N: J10.9 (D0-), Module1.160 (HDMI1_TX0_N)
/CM5_HighSpeed/HDMI1_D0_P: J10.7 (D0+), Module1.158 (HDMI1_TX0_P)
/CM5_HighSpeed/HDMI1_D1_N: J10.6 (D1-), Module1.154 (HDMI1_TX1_N)
/CM5_HighSpeed/HDMI1_D1_P: J10.4 (D1+), Module1.152 (HDMI1_TX1_P)
/CM5_HighSpeed/HDMI1_D2_N: J10.3 (D2-), Module1.148 (HDMI1_TX2_N)
/CM5_HighSpeed/HDMI1_D2_P: J10.1 (D2+), Module1.146 (HDMI1_TX2_P)
/CM5_HighSpeed/HDMI1_HOTPLUG: J10.19 (HPD/HEAC-), Module1.143 (HDMI1_HOTPLUG)
/CM5_HighSpeed/HDMI1_SCL: J10.15 (SCL), Module1.147 (HDMI1_SCL)
/CM5_HighSpeed/HDMI1_SDA: J10.16 (SDA), Module1.145 (HDMI1_SDA)
/CM5_HighSpeed/HDMI_5v: C13.1, J10.18 (+5V), J22.18 (+5V), U12.2 (OUT)
/CM5_HighSpeed/PCIE_CLK_N: Module1.112 (PCIe_CLK_N); also elsewhere on the board
/CM5_HighSpeed/PCIE_CLK_P: Module1.110 (PCIe_CLK_P); also elsewhere on the board
/CM5_HighSpeed/PCIE_PWR_EN: Module1.106 (PCIE_PWR_EN); also elsewhere on the board
/CM5_HighSpeed/PCIE_RX_N: Module1.118 (PCIe_RX_N); also elsewhere on the board
/CM5_HighSpeed/PCIE_RX_P: Module1.116 (PCIe_RX_P); also elsewhere on the board
/CM5_HighSpeed/PCIE_TX_N: Module1.124 (PCIe_TX_N); also elsewhere on the board
/CM5_HighSpeed/PCIE_TX_P: Module1.122 (PCIe_TX_P); also elsewhere on the board
/CM5_HighSpeed/PCIE_nCLKREQ: Module1.102 (PCIe_nCLKREQ); also elsewhere on the board
/CM5_HighSpeed/PCIE_nRST: Module1.109 (PCIe_nRST); also elsewhere on the board
/CM5_HighSpeed/PCIE_nWAKE: Module1.104 (PCIE_nWAKE); also elsewhere on the board
/CM5_HighSpeed/SCL0: J5.20; also elsewhere on the board
/CM5_HighSpeed/SCL1: J6.2, J16.20, R7.2
/CM5_HighSpeed/SDA0: J5.21; also elsewhere on the board
/CM5_HighSpeed/SDA1: J6.4, J16.21, R6.2
/CM5_HighSpeed/USB3-0-D_N: J12.A2 (D-), Module1.136 (USB3-0-D_N)
/CM5_HighSpeed/USB3-0-D_P: J12.A3 (D+), Module1.134 (USB3-0-D_P)
/CM5_HighSpeed/USB3-0-RX_N: J12.A6 (SSRX+), Module1.128 (USB3-0-RX_N)
/CM5_HighSpeed/USB3-0-RX_P: J12.A5 (SSRX-), Module1.130 (USB3-0-RX_P)
/CM5_HighSpeed/USB3-0-TX_N: J12.A9 (SSTX+), Module1.140 (USB3-0-TX_N)
/CM5_HighSpeed/USB3-0-TX_P: J12.A8 (SSTX-), Module1.142 (USB3-0-TX_P)
/CM5_HighSpeed/USB3-1-D_N: J12.B2 (D-), Module1.165 (USB3-1-D_N)
/CM5_HighSpeed/USB3-1-D_P: J12.B3 (D+), Module1.163 (USB3-1-D_P)
/CM5_HighSpeed/USB3-1-RX_N: J12.B6 (SSRX+), Module1.157 (USB3-1-RX_N)
/CM5_HighSpeed/USB3-1-RX_P: J12.B5 (SSRX-), Module1.159 (USB3-1-RX_P)
/CM5_HighSpeed/USB3-1-TX_N: J12.B9 (SSTX+), Module1.169 (USB3-1-TX_N)
/CM5_HighSpeed/USB3-1-TX_P: J12.B8 (SSTX-), Module1.171 (USB3-1-TX_P)
/CM5_HighSpeed/VBUS: C3.1, C7.1, C8.1, J12.A1 (VBUS), J12.B1 (VBUS), U6.6 (OUT)
/CM5_HighSpeed/VBUS_EN: Module1.111 (VBUS_EN), U6.3 (EN)
/USB2_N: Module1.103 (USB2_N); also elsewhere on the board
/USB2_P: Module1.105 (USB2_P); also elsewhere on the board
GND: C2.2, C3.2, C7.2, C8.2, C12.2, C13.2, J5.1, J5.4, J5.7, J5.10, J5.13, J5.16, J5.19, J10.2 (D2S), J10.5 (D1S), J10.8 (D0S), J10.11 (CKS), J10.17 (GND), J10.SH1 (SH), J10.SH2 (SH), J10.SH3 (SH), J10.SH4 (SH), J12.10 (SHIELD), J12.A4 (GND), J12.A7 (DRAIN), J12.B4 (GND), J12.B7 (DRAIN), J16.1, J16.4, J16.7, J16.10, J16.13, J16.16, J16.19, J22.2 (D2S), J22.5 (D1S), J22.8 (D0S), J22.11 (CKS), J22.17 (GND), J22.SH1 (SH), J22.SH2 (SH), J22.SH3 (SH), J22.SH4 (SH), Module1.107 (GND), Module1.108 (GND), Module1.113 (GND), Module1.114 (GND), Module1.119 (GND), Module1.120 (GND), Module1.125 (GND), Module1.126 (GND), Module1.131 (GND), Module1.132 (GND), Module1.137 (GND), Module1.138 (GND), Module1.144 (GND), Module1.150 (GND), Module1.155 (GND), Module1.156 (GND), Module1.161 (GND), Module1.162 (GND), Module1.167 (GND), Module1.168 (GND), Module1.173 (GND), Module1.174 (GND), Module1.179 (GND), Module1.180 (GND), Module1.185 (GND), Module1.186 (GND), Module1.191 (GND), Module1.192 (GND), Module1.197 (GND), Module1.198 (GND), R12.2, U6.2 (GND), U12.3 (GND); also elsewhere on the board
unnamed: J16.17, R8.2
unnamed: R12.1, U6.5 (ILIM)

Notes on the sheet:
USB 3 Pairs P/N swapped to help routing
Jumpers to be fitted if DPHY1 is used
Current Limit switch
DSI/CSI Connectors
Stacked USB connectors


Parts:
C4, C6, C14, C15, C16, C17: 10u; C_0805_2012Metric; Part Description 10uF 10% 10V Ceramic Capacitor X7R 0805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
C10, C19: 100n; C_0402_1005Metric; Part Description 0.1uF 10% 16V Ceramic Capacitor X7R 040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
C11: 4.7nF; C_0402_1005Metric; Part Description 4.7nF capacitor 0402
D3: LED Green; LED_0603_1608Metric; Part Description Green 572nm LED Indication - Discrete 2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
J4: Bus_M.2_Socket_M; M.2 M Key socket; Part Description M.2 M Key connector
L1: 2.2uH; L_Bourns_SRP5030CC; Part Description Inductor, SMT, 2520, 2u2, IRMS=7A, ISAT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
M1: M.2 Screw; Part Description M.2 Screw
M2, M3, M4, M5: M.2 Solder Nut; Part Description Solder nut for M.2 slot
R14: 100K 1%; R_0402_1005Metric; Part Description Resistor 100K M1005 1% 63mW
R15: 10K 1%; R_0402_1005Metric; Part Description Resistor 10K M1005 1% 63mW
R16: 2.2K 1%; R_0402_1005Metric; Part Description Resistor 2.2K M1005 1% 63mW
R17: 1k; R_0402_1005Metric; Part Description Resistor 1K M1005 1% 63mW
TP1: TestPoint; TestPoint_Pad_2.0x2.0mm; Part Description Test point; not fitted
U7: ASEK-32.768KHZ-L-R-T; Crystal_SMD_3225-4Pin_3.2x2.5mm; Part Description 32KHz Xtal oscilator
U8: AP3441SHE-7B; DFN-8-1EP_2x2mm_P0.5mm_EP1.05x1.75mm; Part Description 3A DC-DC converter

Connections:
/+5v: C4.1, C6.1, C10.1, U8.3 (VIN); also elsewhere on the board
/CM5_HighSpeed/PCIE_CLK_N: J4.53 (REFCLKn); also elsewhere on the board
/CM5_HighSpeed/PCIE_CLK_P: J4.55 (REFCLKp); also elsewhere on the board
/CM5_HighSpeed/PCIE_PWR_EN: R14.1, U8.7 (EN); also elsewhere on the board
/CM5_HighSpeed/PCIE_RX_N: J4.43 (PETp0); also elsewhere on the board
/CM5_HighSpeed/PCIE_RX_P: J4.41 (PETn0); also elsewhere on the board
/CM5_HighSpeed/PCIE_TX_N: J4.49 (PERp0); also elsewhere on the board
/CM5_HighSpeed/PCIE_TX_P: J4.47 (PERn0); also elsewhere on the board
/CM5_HighSpeed/PCIE_nCLKREQ: J4.52 (~CLKREQ); also elsewhere on the board
/CM5_HighSpeed/PCIE_nRST: J4.50 (~PERST); also elsewhere on the board
/CM5_HighSpeed/PCIE_nWAKE: J4.54 (~PEWAKE); also elsewhere on the board
/PCIe-M2/FB: C11.2, R15.2, R16.1, U8.1 (FB)
/PCIe-M2/M2_3v3: C11.1, C14.1, C15.1, C16.1, C17.1, C19.1, D3.2 (A), J4.2 (3.3V), J4.4 (3.3V), J4.12 (3.3V), J4.14 (3.3V), J4.16 (3.3V), J4.18 (3.3V), J4.70 (3.3V), J4.72 (3.3V), J4.74 (3.3V), L1.2, R15.1, U7.1 (EN), U7.4 (VDD)
GND: C4.2, C6.2, C10.2, C14.2, C15.2, C16.2, C17.2, C19.2, J4.1 (GND), J4.3 (GND), J4.9 (GND), J4.15 (GND), J4.21 (GND), J4.27 (GND), J4.33 (GND), J4.39 (GND), J4.45 (GND), J4.51 (GND), J4.57 (GND), J4.71 (GND), J4.73 (GND), J4.75 (GND), J4.M1 (GND2230), J4.M2 (GND2242), J4.M3 (GND2260), J4.M4 (GND2280), J4.S1, J4.S2, R14.2, R16.2, U7.2 (GND), U8.4 (PGND), U8.8 (SGND), U8.9 (PAD); also elsewhere on the board
unnamed: D3.1 (K), R17.1, TP1.1
unnamed: J4.10 (DAS/~DSS/~LED1), R17.2
unnamed: J4.68 (SUSCLK), U7.3 (Out)
unnamed: L1.1, U8.6 (LX)

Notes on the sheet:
Activity LED



Board: 4 copper layers, 160.0 x 90.0 mm, 78 parts (5 on the bottom side), 160 nets.

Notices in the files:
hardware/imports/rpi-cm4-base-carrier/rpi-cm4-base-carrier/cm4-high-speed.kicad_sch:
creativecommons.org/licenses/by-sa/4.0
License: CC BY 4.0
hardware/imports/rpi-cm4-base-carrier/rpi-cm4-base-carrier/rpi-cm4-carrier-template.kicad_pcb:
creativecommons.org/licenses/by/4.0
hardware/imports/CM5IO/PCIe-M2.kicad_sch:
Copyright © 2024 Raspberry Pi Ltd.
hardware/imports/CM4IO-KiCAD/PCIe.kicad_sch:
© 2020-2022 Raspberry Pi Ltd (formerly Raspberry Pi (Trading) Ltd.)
